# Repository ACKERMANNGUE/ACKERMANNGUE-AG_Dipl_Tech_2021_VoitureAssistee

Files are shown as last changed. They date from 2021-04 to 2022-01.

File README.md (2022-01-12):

# ACKERMANNGUE/AG_Dipl_Tech_2021_VoitureAssistee
 Repository contenant le travail de diplôme de Technicien ES en informatique réalisé par Ackermann Gawen en 2021

 ## Liens utiles
 * [Documentation technique](https://ackermanngue-ag-dipl-tech-2021-voitureassistee.readthedocs.io/fr/latest/documentation_technique.html)
 * [Journal de bord](https://ackermanngue-ag-dipl-tech-2021-voitureassistee.readthedocs.io/fr/latest/logbook.html)
 * [Trello](https://trello.com/b/ZtMZWkWF/voiture-assist%C3%A9e) 

Bonjour à toi.

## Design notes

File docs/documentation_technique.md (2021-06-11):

--- 
title: "Documentation technique de Voiture Assistée"
author: Ackermann Gawen
---
# Documentation technique
## Résumé

_Voiture assistée_ est un projet d'étude portant sur les voitures autonomes et leur fonctionnement. Ce projet est un défi que je me suis lancé étant donné la découverte des différents appareils utilisés pour ce projet. La plus-value sera surtout l'acquisition de nouvelles connaissances dans le domaine de l'informatique physique et de la mise en pratique des connaissances aquisent durant ces 6 dernières années d'études d'informatique. Par conséquent, le but du projet est de réaliser une voiture se déplaçant à l'aide d'une interface web et qui sait se déplacer par elle-même en évitant les obstacles sur sa route.

## Abstract

_Assisted Car_ is a study project about autonomous cars and how they work. This project is a challenge that I set myself given the discovery of the different devices used for this project. The added value will be mainly the acquisition of new knowledge in the field of physical computing and the application of the knowledge acquired during the last 6 years of computer science studies. Therefore, the goal of the project is to realize a car moving with the help of a web interface and which knows how to move by itself by avoiding the obstacles on its way.

## Poster

Poster du projet Voiture Assistée

## Cahier des charges

### Titre du projet

Le titre du projet est Voiture assistée, car le but du projet est d'en réaliser une.

### Contexte

Ce projet m'a été proposé par M. Bonvin car il a vu que j'allais faire une simulation de voiture autonome, il s'est dit que l'on pourrait tourner la chose autrement. Il a une multitude de Raspberry Pi, de composants ainsi qu'une voiture LEGO controlable. C'est pourquoi il m'a dirigé vers une programmation utilisant des capteurs et du bluetooth.

### Objectif

L'objectif principal de ce projet est de réaliser une voiture capable de se déplacer d'un point A à un point B en évitant les différents obstacles sur sa route. Pour ce faire, il faudra trouver un moyen de communiquer avec le Technic Hub afin de mouvoir la voiture. Ensuite, il faudra faire fonctionner indépendamment les différents capteurs. Pour ensuite créer un algorithme événementiel gérant les différentes pondérations des messages que les capteurs enverront.

### Technologies et matériels utilisés

#### Logiciels

- Visual Studio Code
  - Python
  - Flask
- Github
- Markdown
- QCAD
- Photoshop CS6
- Pencil
- Trello

#### Matériels

- Raspberry Pi 0 WiFi
- Raspberry Pi 4B
- 4 Caméras infrarouges (PI NoIR)
- 4 phares (Bright Pi v1.0)
- GPS (Ultimate GPS Breakout v3)
- Émetteur WiFi (ASUS RT-AC58U)
- LEGO 4x4 X-trem Off-Roader
- Détecteur infrarouge (Flying-Fish)
- Radar 360 (RPLiDAR A2M8)

#### Environnement de développement

Pour me connecter au Raspberry Pi sur lequel je travaille, j'utilise :

- Remote SSH pour éditer le code
  - Il s'agit d'une extension Visual Studio Code disponible [ici](https://marketplace.visualstudio.com/items?itemName=ms-vscode-remote.remote-ssh)
- Github pour publier mon code écrit sur le Raspberry Pi et pour mettre à disposition la documentation technique ainsi que le journal de bord
- RealVNC pour me connecter à distance à l'interface graphique du Raspberry Pi
  - Il s'agit d'un logiciel créant un serveur et un client permettant de contrôler à distance l'écran d'un autre ordinateur, disponible [ici](https://www.realvnc.com/fr/connect/download/viewer/).

### Description détaillée de ce que l'application fait

La voiture est télécommandable à distance à l'aide d'une interface web. Sur le site internet, on a accès à la gestion des états des différents capteurs ainsi que des données qu'ils envoient tel que pour la détection sol, le radar 360° ainsi que pour le flux vidéo des caméras.

#### Plan de la voiture

Croquis du plan de la voiture
Dans le croquis du plan de la voiture présent ci-dessus, je vais énoncer le rôle de chaque composant.

1. Les phares sont représentés par le Bright Pi
2. Les détecteurs de sol placés au niveau des roues sont représentés par le Flying-Fish
3. Le Raspberry Pi 4 est représenté par RSP 4
4. Le Raspberry Pi 0 WiFi est représenté par RSP 0 W
5. Le scanner 360° est représenté par le Lidar

En comparaison, voici de quoi est équipée une vraie voiture autonome :

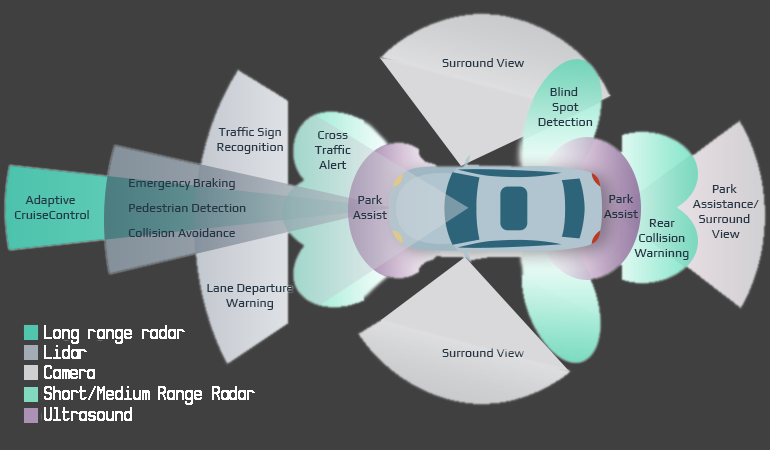
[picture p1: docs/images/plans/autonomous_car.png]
Plan d'une voiture autonome


#### Schéma explicatif de l'application

L'application offre plusieurs pages.

#### Interface utilisateur de l'application

Une page d'interface utilisateur, pour avoir accès aux informations des capteurs ainsi que leurs états.

Interface utilisateur

#### Interface télécommande

Une page de télécommande pour la voiture.

##### En mode manuel

L'utilisateur déplace la voiture à l'aide de la manette disponible sur le site web.

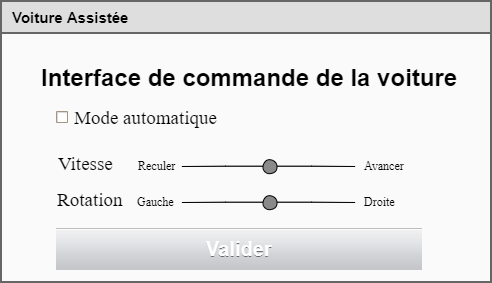
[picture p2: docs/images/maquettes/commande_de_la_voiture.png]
Interface de télécommande en mode manuel


##### En mode automatique

La voiture se déplace de manière rectiligne en évitant les obstacles sur sa route.

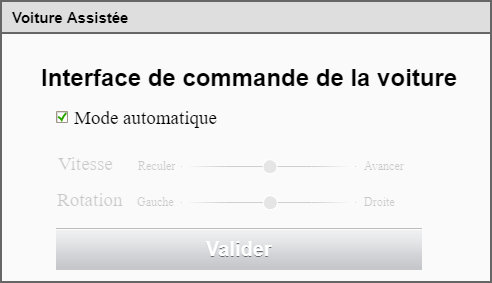
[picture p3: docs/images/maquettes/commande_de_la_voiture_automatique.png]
Interface de télécommande en mode automatique


## Contact

| Status | Nom | Prénom | Email | Numéro de téléphone |
| --- | :---: | :----: | :---: | --- |
| Élève | Ackermann | Gawen  | gawen.ackrm@eduge.ch | +41 79 88 98 69 4 |
| Professeur de diplôme |  Bonvin | Pascal | edu-bonvinp@eduge.ch | +33 6 32 17 84 11 |

## Manuel technique
Dans cette rubrique, nous allons voir comment les divers éléments utilisés dans ce projet ont été mis en place.

### Structure du projet
Dans cette section, je vais vous expliquer la structure de mon projet.

```
├── code
│   ├── Flask
│   └── Toolbox
├── docs
│   ├── images
│   ├── plans
│   ├── documentation_technique.md
│   ├── index.md
│   ├── logbook.md
│   └── requirements.txt
├── site
├── mkdocs.yml
└── README.md
```

Le répertoire :

* `Flask` contient les 2 serveurs Flask à exécuter sur les divers Raspberry Pi
* `Toolbox` contient les différents fichiers python et C++ utilisés pour la mise en place ainsi que les premiers tests des divers éléments à utiliser dans l'application
* `images` contient toutes les images utilisées pour la documentation technique
* `plans` contient les fichiers QCad des plans initiaux de la voiture
* `site` la documentation compilée par MkDocs

### Plan réseau

Étant donné que les divers éléments communiquent par le WiFi, ils doivent donc avoir des adresses IP. Dans mon cas, j'ai choisi d'utiliser des adresses IP statiques. Tous les Raspberry Pi 0 WiFi sont connectés sur le point d'accès qu'est le Raspberry Pi 4. Pour comprendre comment le Raspberry Pi 4 a été transformé en point d'accès, veuillez lire la section parlant de RaspAP dans le guide de mise en place des éléments utilisés.

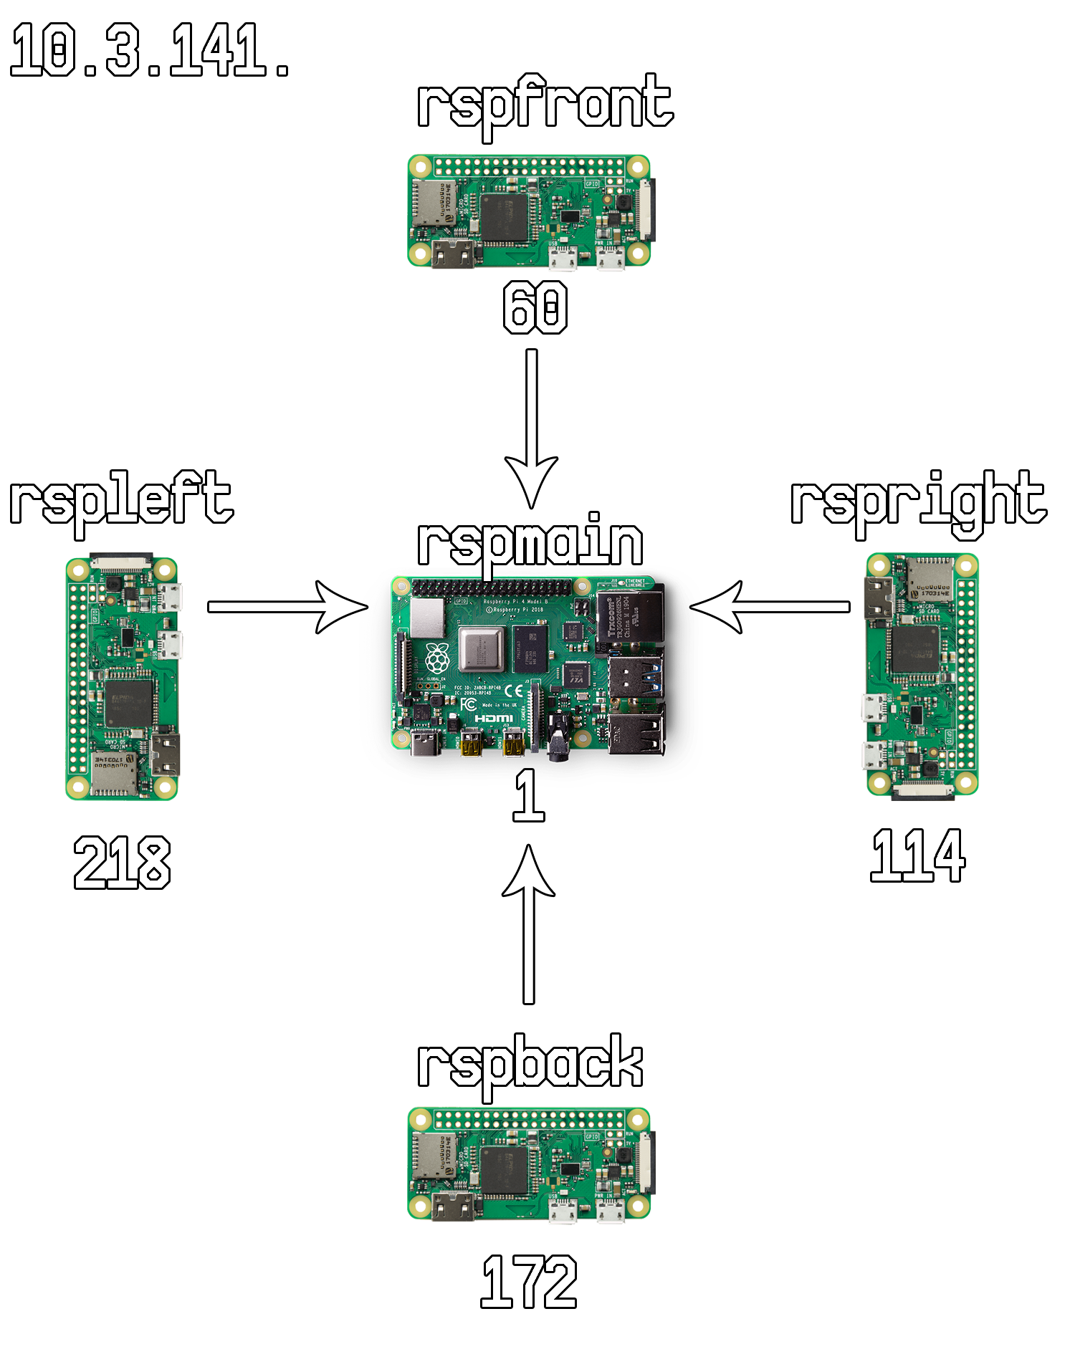
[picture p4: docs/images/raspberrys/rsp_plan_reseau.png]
Plan réseau des Raspberry Pi


### Branchements
#### Alimentation générale
Pour l'alimentation générale, j'ai pris 2 anciens câbles USB que j'ai coupés et dénudés afin de récupérer l'alimentation (Le VCC et le GND). Ces deux câbles ont ensuite été soudés sur les pins soudées à la plaquette.

À la base, la plaquette et la rangée de pins ressemblaient à ceci : 
Plaquette et pins utilisés afin de créer le système d'alimentation générale

Pour ensuite être soudé de la sorte : 

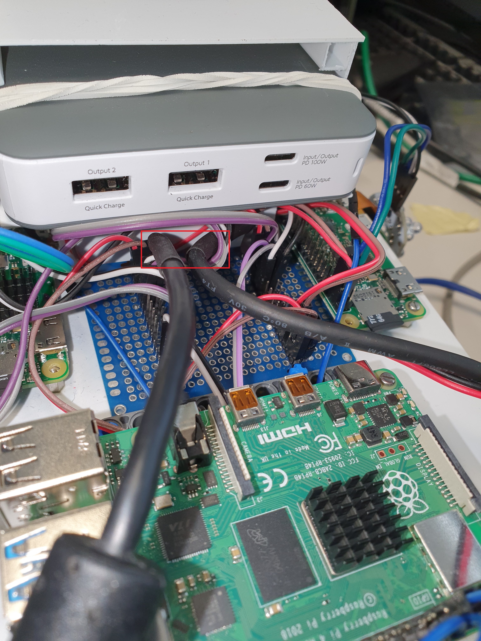
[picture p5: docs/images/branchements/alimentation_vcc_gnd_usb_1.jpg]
Système d'alimentation générale


Système d'alimentation générale

Le courant est soudé sur la pin de gauche tandis que la terre sur la pin de droite. Ce processus a été répété 2 fois, car il y a deux sorties présentes sur la batterie externe.

Les câbles USB sont branchés dans les ports Output 1 et 2 de la batterie externe comme ceci :

Courant de l'alimentation générale

Il est important de noter, que chaque composant est branché à l'alimentation générale de la sorte : 

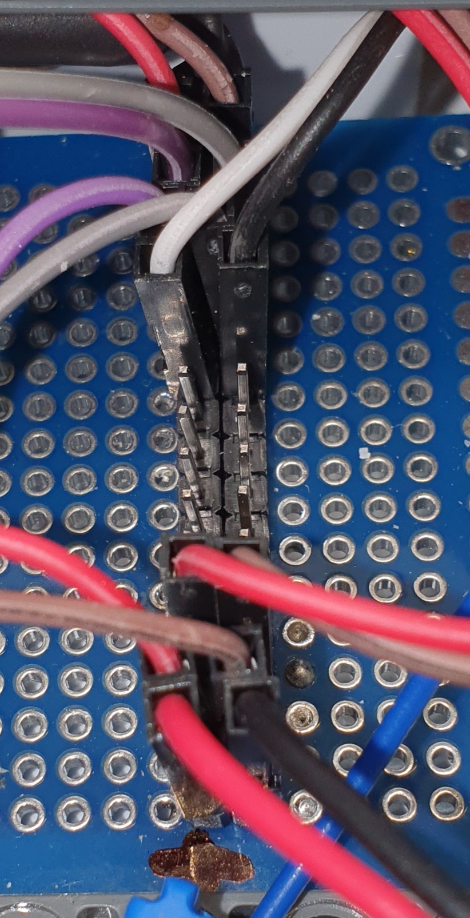
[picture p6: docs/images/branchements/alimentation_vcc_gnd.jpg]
Branchement des composants sur l'alimentation générale


Par conséquent sur cet exemple, les câbles rouges, blancs et violets sont branchés sur le courant et les câbles noirs, gris et bruns sont branchés sur la terre.

#### Raspberry Pi 4
De base, le Raspberry Pi 4 était branché à l'alimentation générale et était alimenté par les pins 4 et 6 du GPIO, mais après quelques tests, j'ai pu me rendre compte que certain Raspberry Pi 0 WiFi branché au système d'alimentation générale n'avait pas assez de courant et ne faisaient que de redémarrer en boucle. C'est pourquoi après réflexion, j'ai branché le Raspberry Pi 4 sur la batterie externe en USB-C comme ceci afin de libérer de la charge de courant de l'alimentation générale :

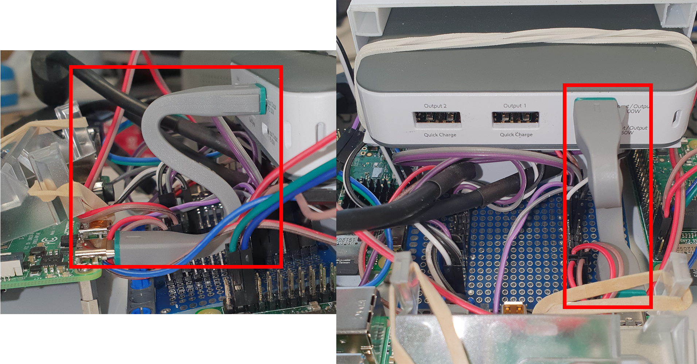
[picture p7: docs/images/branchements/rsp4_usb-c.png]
Branchement du Raspberry Pi 4 à la batterie externe


##### Lidar
Le lidar est connecté à l'adaptateur qui permet de le brancher en USB au raspberry comme vu dans la section portant sur le Lidar dans le guide de mise en place.

Pour l'affichage graphique des données perçues par le Lidar, veuillez regarder la section parlant de Matplotlib dans le guide de mise en place et pour ce qui est de l'affichage des données en un quasi-temps réel, j'utilise la même méthode que pour la récupération du flux de la caméra en temps réel.

##### Flying-Fish
Les divers Flying-Fish sont branchés par des câbles gris et violets à l'alimentation générale, mais les valeurs de sorties qu'ils fournissent sont branchés par des câbles bleus sur les GPIO suivant du raspberry pi 4 :

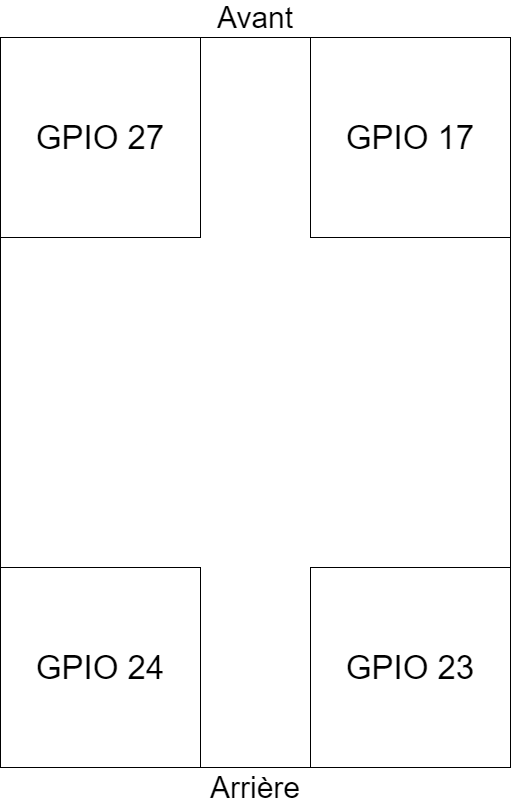
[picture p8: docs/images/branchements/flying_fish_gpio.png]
GPIO utilisés pour les Flying-Fish


#### Raspberry Pi 0 WiFi
Le raspberry pi 0 WiFi est branché à l'alimentation générale et est alimenté par les pins 4 et 6 du GPIO.

##### Caméra 
La caméra est branchée de la même manière que dans la section expliquant le module caméra dans le document de mise en place des composants.

#### Bright Pi 
Le Bright Pi est branché sur l'alimentation générale avec des câbles blancs et noirs. Les 2 autres câbles bleus et verts sont branchés sur des GPIO I2C, donc les pins 2 et 9. Pour ce qui est du câblage pour les câbles bleus et verts, il est identique à la section expliquant ce qu'est le Bright Pi dans le guide de mise en place.

### Analyse organique
Dans cette section, nous allons parler plus en détail du fonctionnement de l'application et des éléments mis en place.

#### Raspberry Pi 4
##### À quoi sert-il ?
Ce raspberry pi est le raspberry pi principal. C'est-à-dire que c'est lui qui va être le point d'accès par rapport aux autres rapsberry pi dont la voiture est équipée.

##### Comment on l'utilise ?
Pour exécuter le script du serveur principal, il faut utiliser la commande `python3 server.py` depuis le répertoire `/code/Flask/flask_server`. Ce script est un serveur Flask nous donnant accès aux différentes fonctionnalités de l'application.

##### Comment fonctionne-t-il ?
Une fois le serveur lancé, et après nous être rendu avec un navigateur web connecté à l'adresse du raspberry pi et sur le port 5000 du réseau fournit par le raspberry pi 4. Exemple : `10.3.141.1:5000`

###### Barre de navigation
La barre de navigation nous permet de changer de page. Cette dernière contient 5 éléments.

Barre de navigation du site web

* A. Redirection sur la page d'accueil
* B. Redirection sur la page de télécommande
* C. Redirection sur la page du tableau de bord
* D. Création d'une connexion avec la voiture
* E. Déconnexion avec la voiture
  
###### Page d'accueil
Ceci est la page sur laquelle on arrive lorsque l'on tape l'adresse IP du point d'accès avec le port 5000.

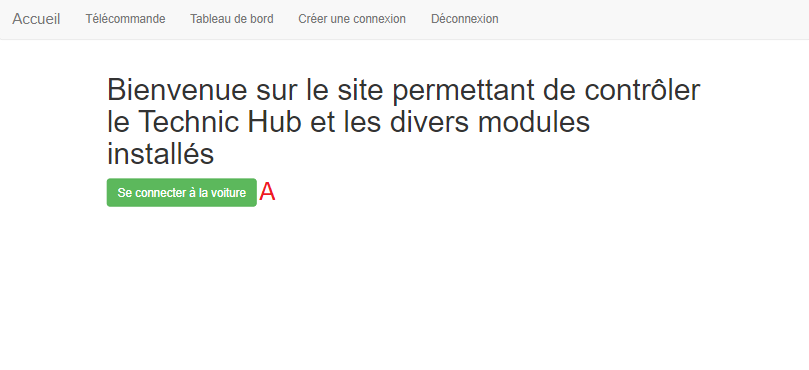
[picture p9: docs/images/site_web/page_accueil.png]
Page d'accueil du site web


* A. Bouton créant une connexion avec la voiture

###### Page de télécommande
Cette page permet, si une connexion avec la voiture est établie, de contrôler la voiture.

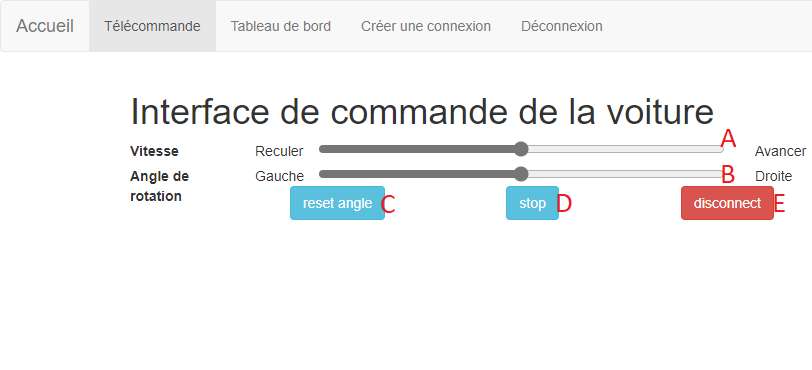
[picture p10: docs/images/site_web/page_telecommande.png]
Page de télécommande du site web


* A. Une barre coulissante allant de -100 à 100 pour gérer la vitesse de la voiture
* B. Une barre coulissante allant de -100 à 100 pour gérer le guidon de la voiture
* C. Bouton remettant le guidon à sa position initiale
* D. Bouton coupant les moteurs de la voiture
* E. Bouton de déconnexion à la voiture

Il est important de savoir que dans le code gérant les déplacements de la voiture, j'inverse les données et les divise par 100, car les valeurs sont comprises entre -1 et 1. La raison pour laquelle j'inverse par la suite les vitesses dans le code, c'est parce que pour avancer avec la voiture, il faut lui donner une vitesse négative, cependant je trouvais plus logique pour une interface utilisateur que pour avancer l'on ajuste la barre coulissante à droite.

###### Page du tableau de bord
Cette page permet à l'utilisateur de gérer les différents capteurs et de voir en temps réel les données reçues par les caméras ainsi que par le Lidar.

Page de télécommande du site web

* A. Case à cocher (dés)activant le mode automatique
* B. Case à cocher (dés)activant les leds à la position indiquée 
  * Les cases de gauche allument les leds blanches, les cases de droites allument les leds infrarouges
* C. Case à cocher (dés)activant la caméra à la position indiquée
* D. Case à cocher (dés)activant la récupération des données du Lidar

De base, toutes les caméras sont éteintes ainsi que le radar :

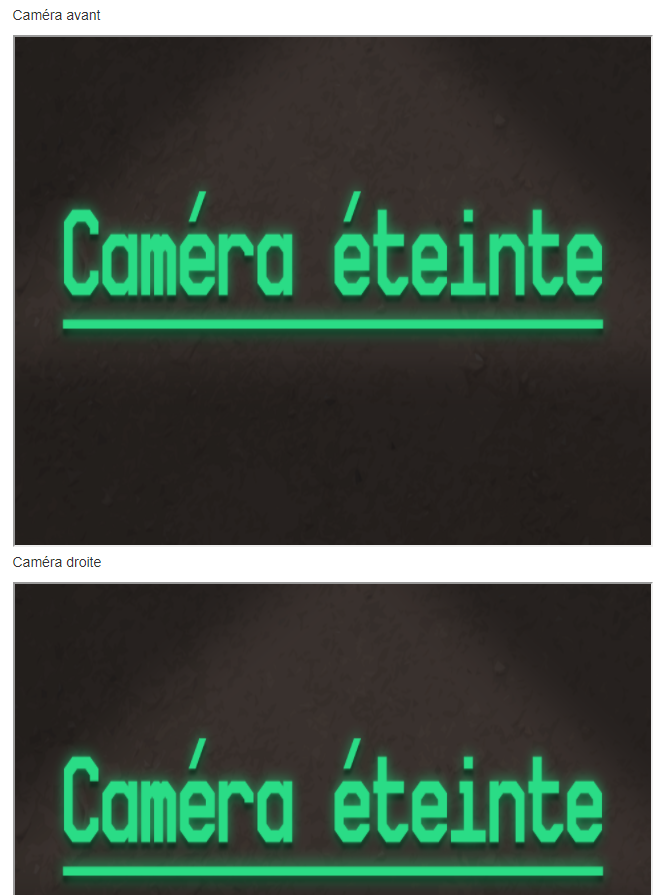
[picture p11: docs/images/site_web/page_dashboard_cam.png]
Caméras éteintes


Radar éteint

Voici ce à quoi ça ressemble lorsque l'on active une caméra et le radar :

Caméra et radar activé

J'ai choisi d'afficher les éléments à la suite, car l'utilisateur va utiliser son téléphone pour se connecter à l'application. Il est donc plus pratique d'avoir accès aux éléments comme ceci étant sur un téléphone portable.

Pour comprendre comment le flux des diverses caméras sont récupérés, veuillez regarder la section parlant de le récupération du flux vidéo dans le guide de mise en place. 

###### Page création de connexion
Lors de l'appui sur cet élément, cela va lancer une connexion avec la voiture.

###### Page de déconnexion
Lors de l'appui sur cet élément, cela va lancer une déconnexion avec la voiture.

##### Comment fonctionne la connexion avec la voiture ?
La création de la connexion avec la voiture s'effectue dans la classe `car`. Cette classe lorsque l'on crée un nouvel objet, va demander une connexion Gatt au Technic Hub.

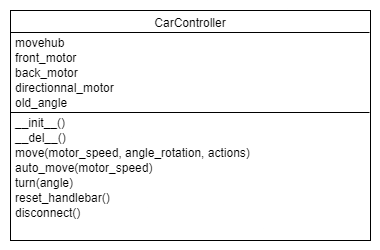
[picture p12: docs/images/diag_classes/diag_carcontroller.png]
Diagramme de classe CarController


```python
class CarController:
    """Class controlling the car"""

    MY_MOVEHUB_ADD = "90:84:2B:50:36:43"
    MY_BTCTRLR_HCI = "hci0"
    MIN_ANGLE = -1
    MAX_ANGLE = 1
    DEFAULT_ANGLE = 0
    MAX_MOTOR_POWER = 1
    MOTOR_STOP_POWER = 0
    MAXIMUM_SPEED_WHEN_GROUND_ISNT_DETECTED = 0.2

    def __init__(cls):
        cls.connection = get_connection_gatt(hub_mac=cls.MY_MOVEHUB_ADD)
        try:
            cls.movehub = MoveHub(cls.connection)
            # The motors
            cls.front_motor = Motor(cls.movehub, cls.movehub.PORT_A)
            cls.back_motor = Motor(cls.movehub, cls.movehub.PORT_B)
            cls.directionnal_motor = EncodedMotor(cls.movehub, cls.movehub.PORT_C)
            cls.old_angle = cls.DEFAULT_ANGLE
        except:
            cls.movehub = None
            cls.front_motor = None
            cls.back_motor = None
            cls.directionnal_motor = None
            cls.instance = None
            cls.connection = None
            cls.old_angle = None

```

On fait un try / except car si la demande n'est pas aboutie, il faut que l'on puisse tout de même remplir les champs de la classe.

Voici la route qui permet de créer la connexion :

```python
@app.route("/create_car/")
def create_car():
    """Used to the creation of the car"""
    global car
    car = CarController()
    if hasattr(car, "connection"):
        return render_template("form_remote_car.html")
    else:
        car = None
        return render_template(
            "error.html", msg="Une connexion est nécessaire pour pouvoir interagir avec"
        )
```

Lors de l'appel à la route ci-dessus, il ne faut pas oublier de cliquer sur le bouton vert du `Technic Hub`. 

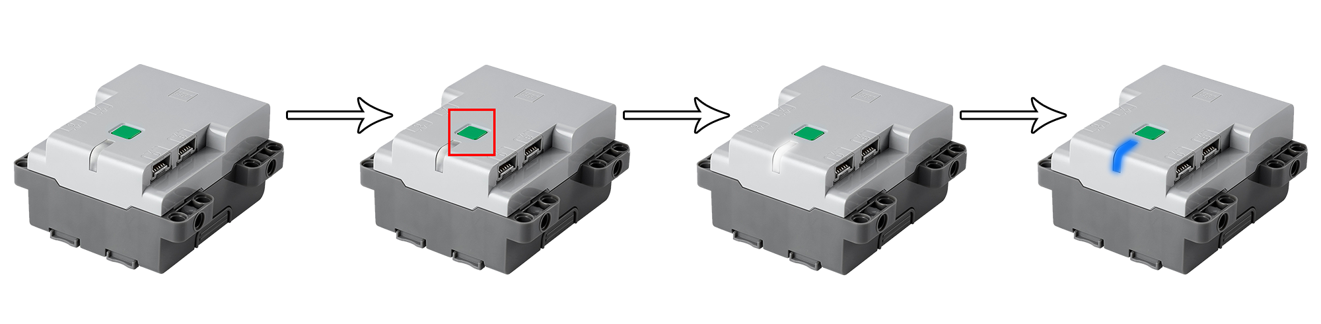
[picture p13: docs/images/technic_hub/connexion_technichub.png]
Préparation du Technic Hub à l'appareillage


Il est important de noter que la voiture est stockée dans une variable globale car ceci nous permet de alors d'avoir accès à la voiture depuis divers méthodes. À la base, cette connexion avec la voiture était faite à travers le design pattern du Singelton : 

```python
def __new__(cls):
    if(cls.instance is None):
        cls.instance = super(CarController, cls).__new__(cls)
        cls.connection = get_connection_gatt(hub_mac=cls.MY_MOVEHUB_ADD)
        try:
            cls.movehub = MoveHub(cls.connection)
            # The motors
            cls.front_motor = Motor(cls.movehub, cls.movehub.PORT_A)
            cls.back_motor = Motor(cls.movehub, cls.movehub.PORT_B)
            cls.directionnal_motor = EncodedMotor(cls.movehub, cls.movehub.PORT_C)
        except:
            cls.movehub = None
            cls.front_motor = None
            cls.back_motor = None
            cls.directionnal_motor = None
    return cls.instance
```

Le problème que le Singleton avait était que des fois, il perdait la connexion à la voiture alors que l'instance de l'objet était toujours présente. C'est-à-dire, que lorsque l'on se déconnectait de la voiture à l'aide de la méthode de déconnexion appelée par la route :

```python
# Code présent dans la classe CarController
def disconnect(self):
        self.connection.disconnect()

# Code présent dans le fichier server.py dans le répertoire /code/Flask/flask_server/
@app.route("/close_connection/")
def close_connection():
    """Close the connection between the Raspberry Pi and the Technic Hub"""
    global car
    output = "Connexion toujours en cours"
    if car != None:
        car.disconnect()
        output = "Connexion fermée avec l'appareil {0}".format(car.MY_MOVEHUB_ADD)
        car = None

    return render_template("connection.html", msg=output)

```

##### Comment fonctionne la récupération des données du Lidar ?

Pour activer l'API C++ pour y récupérer les distances à chaque angles qui sont écrits dans la console et afin d'éviter de rendre le code bloquant, j'ai utilisé `Asyncio`. 

Voici le code permettant l'appel et le traitement asynchrone des données :

```python
@app.route("/bg_processing_lidar/<string:state>", methods=["POST"])
def bg_process_lidar(state=None):
    """Process the values passed by Javascript"""

    try:
        loop = asyncio.get_running_loop()
    except RuntimeError:  # no event loop running:
        loop = asyncio.new_event_loop()
    finally:
        loop.run_until_complete(main(state))

    return ""

async def main(should_scan):
    """
    The main function which calls the run loop async

    should_scan : The code to know if the program should scan or not
    """
    await run(should_scan)

async def run(should_scan):
    """
    Will run the subprocess and bind the async method

    should_scan : The code to know if the program should scan or not
    """
    command = ("./scanner/simple_grabber /dev/ttyUSB0 " + should_scan).split()
    process = await create_subprocess_exec(*command, stdout=PIPE, stderr=PIPE)
    await asyncio.wait([_read_stream(process.stdout, lambda x: {get_radar_data(x)})])
    await process.wait()

async def _read_stream(stream, callback):
    """
    Will read the text in the console from the process simple_grabber

    stream : The streaming of the data in the console
    callback : The method to call when data has been received

    """
    while True:
        line = await stream.readline()
        if line:
            callback(line.split(b","))
        else:
            break

def get_radar_data(row):
    """
    Will parse the data received in text by the Lidar

    row : Row to read and to add or modify in the array of angles
    """
    global rows
    # row normaly is like [angle, distance]
    tmp = row
    if len(tmp) == 2:
        angle = int(tmp[0])
        # remove the line return
        dist = tmp[1].replace(b"\n", b"")
        rows[angle] = float(dist)

```

Comme l'on peut le voir, lors de l'activation ainsi que de la désactivation du Lidar. On effectue un processus, car étant donné que dans le code de l'API, il s'agit d'une boucle infinie récupérant et lissant les données qui sont affichées dans la console, on a besoin de manière asynchrone à traiter ses données et à les mettre dans le tableau.

C'est ce à quoi sert la méthode `_read_stream`. Cette méthode nous permet de lire ligne par ligne le contenu de sortie de la console (`process.stdout`) et en l'ajoutant dans le tableau avec la méthode `get_radar_data(row)`.

Méthode utilisée pour récupérer en temps réel les données du Lidar

###### Code de l'API C++ modifié

```cpp

int main(int argc, const char *argv[])
{
    const char *opt_com_path = NULL;
    _u32 opt_com_baudrate = 115200;
    u_result op_result;
    bool run_scan = false;

    // check if the the program should run scans
    if(argc == 3) {
        char arg = (char)*argv[2];
        if(arg == '1') {
            run_scan = true;
        } else if(arg == '0') {
            run_scan = false;
        }
    }

    if (argc < 2)
    {
        print_usage(argc, argv);
        return -1;
    }
    opt_com_path = argv[1];

    // create the driver instance
    RPlidarDriver *drv = RPlidarDriver::CreateDriver(DRIVER_TYPE_SERIALPORT);

    if (!drv)
    {
        fprintf(stderr, "insufficent memory, exit\n");
        exit(-2);
    }

    rplidar_response_device_health_t healthinfo;
    rplidar_response_device_info_t devinfo;
    do
    {
        // try to connect
        if (IS_FAIL(drv->connect(opt_com_path, opt_com_baudrate)))
        {
            fprintf(stderr, "Error, cannot bind to the specified serial port %s.\n", opt_com_path);
            break;
        }

        op_result = drv->getDeviceInfo(devinfo);

        if (IS_FAIL(op_result))
        {
            if (op_result == RESULT_OPERATION_TIMEOUT)
            {
                // you can check the detailed failure reason
                fprintf(stderr, "Error, operation time out.\n");
            }
            else
            {
                fprintf(stderr, "Error, unexpected error, code: %x\n", op_result);
                // other unexpected result
            }
            break;
        }

        op_result = drv->getHealth(healthinfo);
        if (IS_OK(op_result))
        { // the macro IS_OK is the preperred way to judge whether the operation is succeed.
            switch (healthinfo.status)
            {
            case RPLIDAR_STATUS_WARNING:
                printf("Warning.");
                break;
            case RPLIDAR_STATUS_ERROR:
                printf("Error.");
                break;
            }
            printf(" (errorcode: %d)\n", healthinfo.error_code);
        }
        else
        {
            fprintf(stderr, "Error, cannot retrieve the lidar health code: %x\n", op_result);
            break;
        }

        if (healthinfo.status == RPLIDAR_STATUS_ERROR)
        {
            fprintf(stderr, "Error, rplidar internal error detected. Please reboot the device to retry.\n");
            break;
        }

        drv->startMotor();

        if (IS_FAIL(drv->startScan(0, 1))) // you can force rplidar to perform scan operation regardless whether the motor is rotating
        {
            fprintf(stderr, "Error, cannot start the scan operation.\n");
            break;
        }

        int max_size_arr_angle_dist = 360;
        float angle_dist_tmp[max_size_arr_angle_dist];
        float angle_dist[max_size_arr_angle_dist];
        int size_arr_angle_dist = (sizeof(angle_dist) / sizeof(angle_dist[0]));

        const int MAX_RANGE_LIDAR = 16000.0f;
        const int MIN_RANGE_LIDAR = 0.0f;
        // used as a code in order to treat the data below in another process
        //printf("<<<\n");
        while (run_scan)
        {
            //reset the array to empty (empty represented by the 0)
            std::fill_n(angle_dist, max_size_arr_angle_dist, 0.0f);
            capture_and_display(angle_dist, drv);

            if (size_arr_angle_dist == 0)
            {
                fprintf(stderr, "Error, cannot grab scan data.\n");
                break;
            }
            
            /* Correct the errors */
            for (size_t j = 0; j < max_size_arr_angle_dist; j++)
            {
                if (angle_dist[j] < MIN_RANGE_LIDAR && angle_dist[j] >= MAX_RANGE_LIDAR)
                {
                    angle_dist[j] = MIN_RANGE_LIDAR;
                }
            }

            /* make the average of distance */
            capture_and_display(angle_dist_tmp, drv);
            for (size_t j = 0; j < max_size_arr_angle_dist; j++)
            {
                if (angle_dist_tmp[j] > MIN_RANGE_LIDAR && angle_dist_tmp[j] < MAX_RANGE_LIDAR)
                {
                    angle_dist[j] = (angle_dist[j] + angle_dist_tmp[j]) / 2;
                }
            }

            for (size_t j = 0; j < max_size_arr_angle_dist; j++)
            {
                printf("%d,%f\n", j, angle_dist[j]);
            }
        }

    } while (0);

    drv->stop();
    drv->stopMotor();

    RPlidarDriver::DisposeDriver(drv);
    return 0;
}

```

##### Comment fonctionne la gestion du déplacement de la voiture ?
###### Télécommande
La télécommande effectue des appels AJAX avec les valeurs des barres coulissantes comme ceci :

```javascript
<script type="text/javascript">

$(document).on('input', '#rngMove', function() {
    execute();
});

$(document).on('input', '#rngRotationAngle', function() {
    execute();
});

function execute(){
    $.ajax({
            url: '/bg_processing_car/',
            data: $('form').serialize(),
            type: 'POST',
            success: function(response) {
                console.log("action performed");
            },
            error: function(error) {
                console.log(error);
            }
        });
    }
</script>
```

Les ID `rngMove` et `rngRotationAngle` sont ceux attachés aux barres coulissantes. À chaque changement de valeurs, qu'il s'agisse du guidon ou de la vitesse des moteurs, la route appelée à l'aide d'AJAX `/bg_processing_car/` se charge de faire le traitement :

```python
@app.route("/bg_processing_car/", methods=["POST"])
def bg_process_car():
    """Process the values passed by Javascript"""

    global car

    move_speed = request.form["rngMove"]
    angle_rotation = request.form["rngRotationAngle"]

    if car != None:
        # Convert the values
        move_speed = float(move_speed)
        angle_rotation = int(angle_rotation)
        # Get the allowed actions of the car
        actions = get_actions_for_car(move_speed)
        car.move(move_speed, angle_rotation, actions)
    return render_template(
        "form_remote_car.html",
        speed=move_speed,
        angle=angle_rotation,
    )

def get_actions_for_car(speed):
    """Process the actions that the car is allowed to do according to the flying-fish"""
    actions = (constants.CODE_TURN_NOTHING, constants.CODE_MOVE_NOTHING)
    # INDEX 0 represent the turn code
    # INDEX 1 represent the move code
    if (
        GPIO.input(constants.GPIO_FLYING_FISH_FRONT_LEFT)
        and GPIO.input(constants.GPIO_FLYING_FISH_FRONT_RIGHT)
        and not GPIO.input(constants.GPIO_FLYING_FISH_BACK_LEFT)
        and not GPIO.input(constants.GPIO_FLYING_FISH_BACK_RIGHT)
    ):
        print("les deux avant")
        actions = (constants.CODE_TURN_NOTHING, constants.CODE_MOVE_BACKWARD)

    elif GPIO.input(constants.GPIO_FLYING_FISH_FRONT_LEFT):
        print("gauche avant")
        actions = (constants.CODE_TURN_RIGHT, constants.CODE_MOVE_NOTHING)

    elif GPIO.input(constants.GPIO_FLYING_FISH_FRONT_RIGHT):
        print("droite avant")
        actions = (constants.CODE_TURN_LEFT, constants.CODE_MOVE_NOTHING)

    elif (
        not GPIO.input(constants.GPIO_FLYING_FISH_FRONT_LEFT)
        and not GPIO.input(constants.GPIO_FLYING_FISH_FRONT_RIGHT)
        and GPIO.input(constants.GPIO_FLYING_FISH_BACK_LEFT)
        and GPIO.input(constants.GPIO_FLYING_FISH_BACK_RIGHT)
    ):
        print("les deux arrière")
        actions = (constants.CODE_TURN_NOTHING, constants.CODE_MOVE_FORWARD)

    elif GPIO.input(constants.GPIO_FLYING_FISH_BACK_LEFT):
        print("gauche arrière")
        actions = (constants.CODE_TURN_RIGHT, constants.CODE_MOVE_FORWARD)

    elif GPIO.input(constants.GPIO_FLYING_FISH_BACK_RIGHT):
        print("droite arrière")
        actions = (constants.CODE_TURN_LEFT, constants.CODE_MOVE_FORWARD)

    return actions
```

Voici le code de déplacement pour la voiture dans la classe `CarController` :

```python

    def move(self, motor_speed, angle_rotation, actions):
        """Moves the car with a specific speed and rotation

        motor_speed : The motor's speed
                      NOTE : to move forward, the value must be reversed because it is basically negative
        angle_rotation : The rotation of the directionnal motor
        actions : The list of the possible actions
        """
        # Invert the power direction
        if motor_speed != 0:
            motor_speed *= -1
        # Max value of motor is -1 and +1 but in the HTML form, the range input can be set between -100 to +100
        motor_speed /= 100
        angle_rotation /= 100

        # INDEX 0 represent the turn code
        # INDEX 1 represent the move code
        try:
            if actions[0] == constants.CODE_TURN_LEFT and angle_rotation < 0:
                self.turn(angle_rotation)

            elif actions[0] == constants.CODE_TURN_RIGHT and angle_rotation > 0:
                self.turn(angle_rotation)

            elif actions[0] == constants.CODE_TURN_NOTHING:
                self.turn(angle_rotation)

            if actions[1] == constants.CODE_MOVE_FORWARD and motor_speed < 0:
                if motor_speed > self.MAXIMUM_SPEED_WHEN_GROUND_ISNT_DETECTED:
                    motor_speed = self.MAXIMUM_SPEED_WHEN_GROUND_ISNT_DETECTED
                self.front_motor.start_power(motor_speed)
                self.back_motor.start_power(motor_speed)

            elif actions[1] == constants.CODE_MOVE_BACKWARD and motor_speed > 0:
                if motor_speed > self.MAXIMUM_SPEED_WHEN_GROUND_ISNT_DETECTED:
                    motor_speed = self.MAXIMUM_SPEED_WHEN_GROUND_ISNT_DETECTED
                self.front_motor.start_power(motor_speed)
                self.back_motor.start_power(motor_speed)

            elif actions[1] == constants.CODE_MOVE_NOTHING:
                self.front_motor.start_power(motor_speed)
                self.back_motor.start_power(motor_speed)
        except AssertionError:
            pass

    def turn(self, angle):
        """Turn the directionnal motor from the input value

        angle : The angle we wants the directionnal motor goes to
        """
        try:
            self.directionnal_motor.start_power(angle)
            self.old_angle = angle
        except AssertionError:
            pass

    def reset_handlebar(self):
        # Reset the angle
        angle = self.old_angle * -1
        angle /= 2
        try:
            self.directionnal_motor.start_power(angle)
            self.old_angle = angle
        except AssertionError:
            pass

    def stop_moving(self):
        """Stop the motors"""
        # Reset the angle
        try:
            self.reset_handlebar()
            self.front_motor.start_power(self.MOTOR_STOP_POWER)
            self.back_motor.start_power(self.MOTOR_STOP_POWER)
        except AssertionError:
            pass
```

On peut remarquer que dans les différentes méthodes j'utilise des `try` / `except`. Je suis obligé de les utiliser, car lors de l'envoie d'une commande au `Technic Hub`, il doit retourner une réponse, cependant des fois il se peut que pendant qu'il traite une commande, avant qu'il aie pu répondre une autre commande lui soit envoyée. Ce qui cause un problème de confirmation, et qui par conséquent faisait crash le programme.

###### Boutons
Pour comprendre plus en détail le rôle des boutons présent sur la page de télécommande, veuillez vous référer à la section décrivant l'interface pour la télécommande. 

Voici comment les actions qu'ils produisent sont gérées :

```python
@app.route("/form_remote_response/", methods=["POST"])
def form_remote_response():
    """The form's answer of the remote"""
    global car
    # Init
    move_speed = constants.DEFAULT_SPEED
    angle_rotation = constants.DEFAULT_ANGLE

    returned_value = render_template(
        "form_remote_car.html",
        speed=move_speed,
        angle=angle_rotation,
    )
    error = render_template(
        "error.html", msg="Une connexion est nécessaire pour pouvoir intéragir avec"
    )
    if request.method == "POST":
        if request.form["send_request"] == constants.BTN_REQUEST_RESET_ANGLE:
            if car != None:
                car.reset_handlebar()
            else:
                returned_value = error
        elif request.form["send_request"] == constants.BTN_REQUEST_STOP:
            if car != None:
                car.stop_moving()
            else:
                returned_value = error
        elif request.form["send_request"] == constants.BTN_REQUEST_DISCONNECT:
            returned_value = redirect("/close_connection/")
    return returned_value
```

###### Comment fonctionne le système d'arrêt d'urgence de la voiture ?

Le système d'argent d'urgence est basé sur ce que les Flying-Fish détectent.

Au lancement de l'application, la méthode `initFlyingFish()` est exécutée, ils ont tous été attachés à une méthode qui se déclenchera à chaque changement d'état :

```python

flying_fish_state = [
    constants.FLYING_FISH_STATE_GROUNDED,
    constants.FLYING_FISH_STATE_GROUNDED,
    constants.FLYING_FISH_STATE_GROUNDED,
    constants.FLYING_FISH_STATE_GROUNDED,
]

def initFlyingfish():
    # Set the mode into Broadcom SOC channel
    # It allows to use GPIO number instead of pin number
    GPIO.setmode(GPIO.BCM)
    # Set the GPIO into input mode
    GPIO.setup(constants.GPIO_FLYING_FISH_FRONT_RIGHT, GPIO.IN)
    GPIO.setup(constants.GPIO_FLYING_FISH_FRONT_LEFT, GPIO.IN)
    GPIO.setup(constants.GPIO_FLYING_FISH_BACK_RIGHT, GPIO.IN)
    GPIO.setup(constants.GPIO_FLYING_FISH_BACK_LEFT, GPIO.IN)

    # Add the events
    GPIO.add_event_detect(
        constants.GPIO_FLYING_FISH_FRONT_RIGHT, # GPIO 17
        GPIO.FALLING,
        callback=get_grounded_state,
        bouncetime=constants.GPIO_BOUNCEBACK, 
    )
    GPIO.add_event_detect(
        constants.GPIO_FLYING_FISH_FRONT_LEFT,  # GPIO 27
        GPIO.FALLING,
        callback=get_grounded_state,
        bouncetime=constants.GPIO_BOUNCEBACK,
    )
    GPIO.add_event_detect(
        constants.GPIO_FLYING_FISH_BACK_RIGHT,  # GPIO 23
        GPIO.FALLING,
        callback=get_grounded_state,
        bouncetime=constants.GPIO_BOUNCEBACK,
    )
    GPIO.add_event_detect(
        constants.GPIO_FLYING_FISH_BACK_LEFT,  # GPIO 24
        GPIO.FALLING,
        callback=get_grounded_state,
        bouncetime=constants.GPIO_BOUNCEBACK,
    )

def get_grounded_state(self):
    """Will stop the motors if the ground isn't detected anymore"""
    global car
    global flying_fish_state

    for i in range(len(constants.GPIO_FLYING_FISH)):
        for sensor_state in flying_fish_state:
            input_values = not GPIO.input(constants.GPIO_FLYING_FISH[i][0])
            if sensor_state != input_values:
                if car != None and (input_values) != True:
                    car.stop_moving()
                # Invert his state
                sensor_state = input_values
        flying_fish_state[i] = sensor_state
    print(flying_fish_state)

```

Pour savoir quel Flying-Fish est associée à quel GPIO, veuillez lire la section en parlant dans la section des branchements.

Lorsque l'un des Flying-Fish change d'état et que son nouvel état n'est pas `True`, la voiture coupe alors ses moteurs. Si le nouvel état est `True`, cela veut dire que l'on vient de détecter du sol.

À noter, que l'utilisateur peut toujours faire avancer sa voiture lorsque l'un des capteurs ne détecte plus de sol, car si on arrive dans une configuration comme celle-ci :

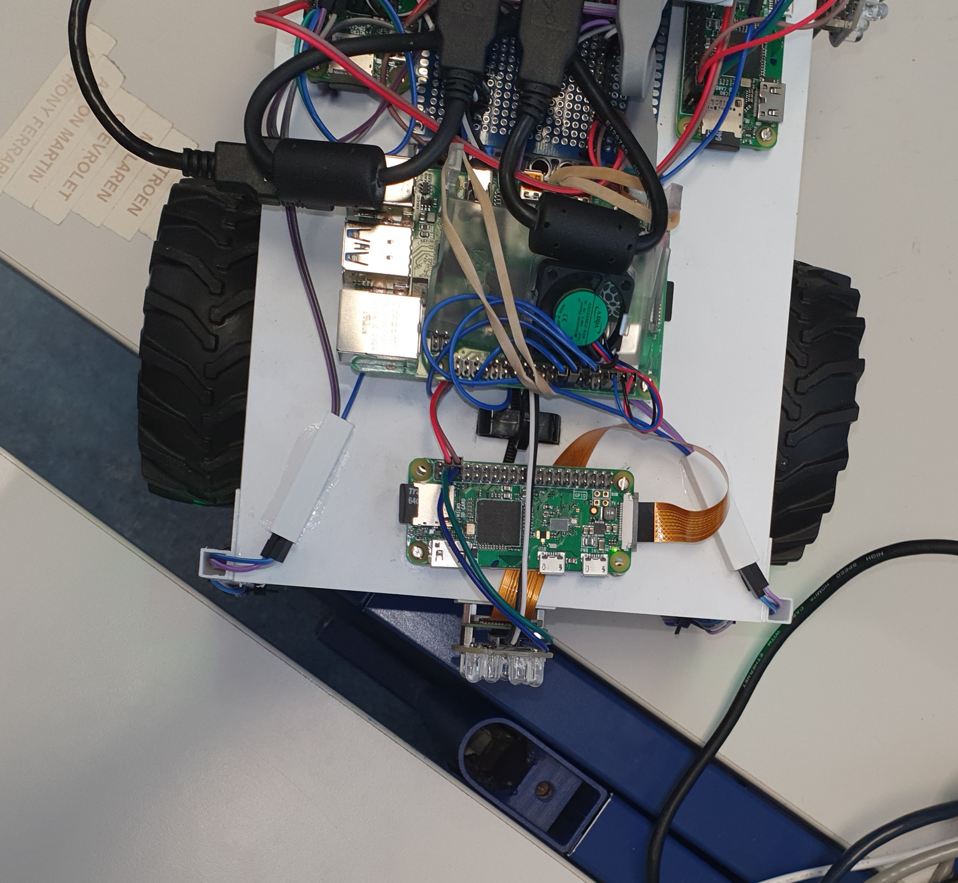
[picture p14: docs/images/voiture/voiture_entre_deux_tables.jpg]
Voiture entre 2 tables


Sachant qu'il s'agit de l'utilisateur, il est conscient qu'il peut toujours avancer, cependant je n'ai pas laissé l'utilisateur allez dans le sens du vide, car même s'il se peut qu l'on arrive dans la quasi-même configuration que vu dans l'image du dessus, mais avec les deux roues entrent les tables. 

Je ne l'ai pas laissé avancer dans le sens du vide, car dans la plupart du temps si la ligne de détecteur ne détecte plus de sol. C'est qu'il y a de fortes chances que nous ne puissions pas atteindre l'autre côté du vide et par conséquent faire tomber la voiture dans ce dernier.

Mais dans le cas où la voiture est au bord de table de justesse, l'utilisateur peut tout de même mettre les gaz à fond. Ce qui est déconseillé, car certes  du moment ou ne l'on détecte plus de sol, les moteurs se coupent, mais à cause de l'inertie des roues, la voiture tombe dans le vide. Il est donc très important que dans ce genre de cas l'utilisateur soit conscient de ce qu'il fait.

Voiture au bord de table

##### Comment fonctionne le mode automatique de la voiture ?

Lorsque le lidar est actif et que le mode automatique a été activé par la route `/launch_automatic_mode/<int:state>`, la méthode gérant la voiture va être lancée sur un autre thread différent de celui principal. À la base, j'avais tenté d'utiliser `Asyncio` une nouvelle fois pour ce cas, mais j'avais besoin de pouvoir changer l'état de la boucle présente dans `automatic_mode()`, car avec `Asyncio` lorsque je relançais le mode automatique, il y avait des erreurs qui intervenaient tandis qu'en exécutant le programme sur un autre thread on peut relancer le mode avec l'état de la case à cocher associée.

```python
@app.route("/launch_automatic_mode/<int:state>", methods=["POST"])
def launch_automatic_mode(state=None):
    """Launch the automatic_mode on another thread"""
    global automatic_mode_state
    automatic_mode_state = state
    # Create the thread
    thread = threading.Thread(target=automatic_mode)
    # Launch it
    thread.start()
    return ""

def automatic_mode():
    """Execute the automatic mode"""
    global car
    global rows
    global automatic_mode_state
    global obstacles_distances_front_left
    global obstacles_distances_front_right

    while automatic_mode_state == constants.MODE_ON:
        # Used to store the obstacles detected at left and right
        obstacles_distances_front_left = []
        obstacles_distances_front_right = []
        for i in range(len(rows)):
            distance = rows[i]

            if car != None:
                # Verify that the current angle is between 0 and 15, 345 and 360 
                if (
                    i < constants.MAX_ANGLE_OBSTACLE_DETECTION
                    or i > constants.FULL_ANGLE - constants.MAX_ANGLE_OBSTACLE_DETECTION
                ):
                    # Verify if the distance is lower than the max front distance obstacle detection 
                    if (
                        distance < constants.FRONT_DISTANCE_OBSTACLE_DETECTION
                        and distance > 0
                    ):
                        # If the current angle is lower than the max angle
                        # Add it into the left array
                        if i < constants.MAX_ANGLE_OBSTACLE_DETECTION:
                            obstacles_distances_front_left.append(distance)
                        # If the current angle is greater than the max angle inverted (345 to 360)
                        # Add it into the right array
                        if (
                            i
                            > constants.FULL_ANGLE
                            - constants.MAX_ANGLE_OBSTACLE_DETECTION
                        ):
                            obstacles_distances_front_right.append(distance)
                        # Compute the power, more the obstacle is near, more the motors will be powered
                        speed = distance / constants.FRONT_DISTANCE_OBSTACLE_DETECTION
                        # Goes backward
                        car.auto_move(speed)
                # Verify that the current angle is between 165 and 180, 180 and 195 
                elif (
                    i < constants.HALF_ANGLE + constants.MAX_ANGLE_OBSTACLE_DETECTION
                    or i > constants.HALF_ANGLE - constants.MAX_ANGLE_OBSTACLE_DETECTION
                ):
                    # Verify if the distance is lower than the max front distance obstacle detection 
                    if (
                        distance < constants.BACK_DISTANCE_OBSTACLE_DETECTION
                        and distance > 0
                    ):
                        # Compute the power, more the obstacle is near, more the motors will be powered
                        speed = distance / constants.BACK_DISTANCE_OBSTACLE_DETECTION
                        # Goes forward
                        car.auto_move(speed * (-1))
                else:
                    # If nothing, reset the handlebar and stop the motors
                    car.stop_moving()
                    car.reset_handlebar()

                # Select the smallest element
                lowest_dist_left = constants.FRONT_DISTANCE_OBSTACLE_DETECTION
                for i in range(len(obstacles_distances_front_left)):
                    if lowest_dist_left > obstacles_distances_front_left[i]:
                        lowest_dist_left = obstacles_distances_front_left[i]

                # Select the smallest element
                lowest_dist_right = constants.FRONT_DISTANCE_OBSTACLE_DETECTION
                for i in range(len(obstacles_distances_front_right)):
                    if lowest_dist_right > obstacles_distances_front_right[i]:
                        lowest_dist_right = obstacles_distances_front_right[i]
                # Check that their values are not the default one
                if (
                    lowest_dist_right != constants.FRONT_DISTANCE_OBSTACLE_DETECTION
                    and lowest_dist_left != constants.FRONT_DISTANCE_OBSTACLE_DETECTION
                ):
                    # If the nearest obstacle is at left, we need to turn to the right
                    if lowest_dist_left < lowest_dist_right:
                        car.turn(car.MIN_ANGLE)
                    # If the nearest obstacle is at right, we need to turn to the left
                    elif lowest_dist_left > lowest_dist_right:
                        car.turn(car.MAX_ANGLE)
                    # Else, just reset the handlebar
                    else:
                        car.reset_handlebar()
```

Voici l'algorithme résumé :

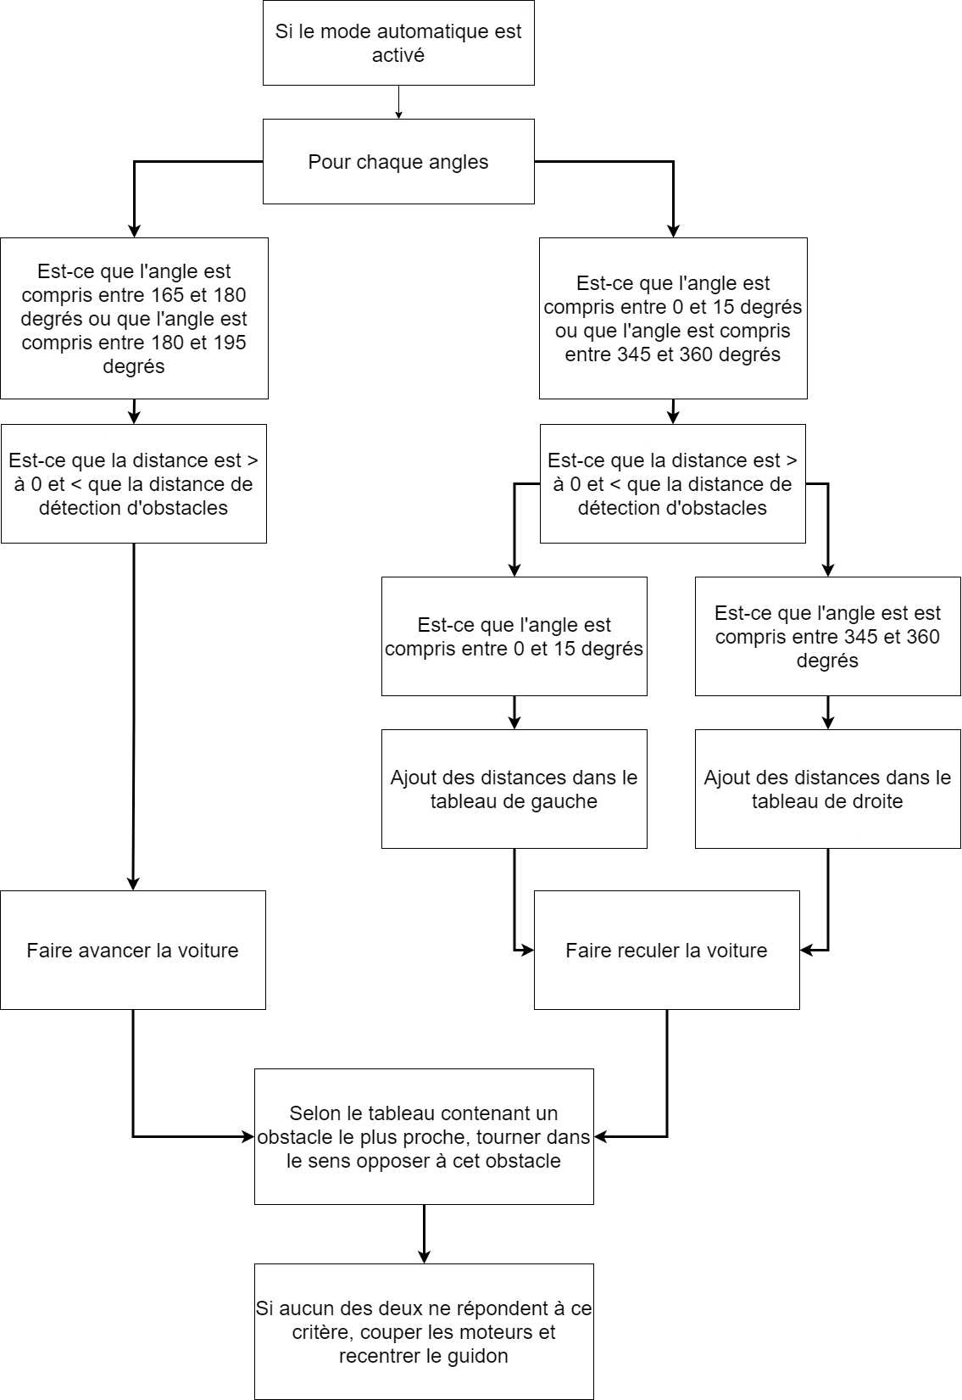
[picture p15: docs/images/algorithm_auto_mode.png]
Algorithme du mode automatique


#### Raspberry Pi 0 WiFi

##### À quoi servent-ils ?
Les raspberry pi 0 WiFi, sont utilisés pour gérer les caméras et les phares.

##### Comment on l'utilise ?
Il faut lancer sur chaque raspberry pi 0 WiFi le serveur Flask avec la commande : `python3 ACKERMANNGUE-AG_Dipl_Tech_2021_VoitureAssistee/code/Flask/flask_sensors_control/server.py`.
##### Comment fonctionne-t-il ?
Le serveur Flask proprose 2 routes :

###### Gestion des capteurs à distance
Pour gérer les capteurs à distance, j'utilise 2 serveurs Flask différents.

Le premier est le serveur principal tournant sur le Pi 4, celui sur lequel l'utilisateur sera pour avoir accès au tableau de bord, à la télécommande pour la voiture.

Le second est le serveur tournant sur les Pi 0 WiFi, son rôle est d'effectuer des actions en fonction des diverses routes utilisées. Il y a 2 routes très importantes.

1. `@app.route('/streaming_camera')`
2. `@app.route('/<string:sensor>/<int:state>', methods=['POST', 'OPTIONS'])`

1. Le flux vidéo de la caméra
2. La gestion des modules caméra et bright-pi

La seconde est celle qui effectue les actions sur les capteurs, voici un exemple : `192.168.50.230:5000/camera/1`. 

À noter, il est important d'utiliser `Flask-CORS` comme suit :

```python

...

from flask_cors import CORS
from flask_cors.decorator import cross_origin

...

app = Flask(__name__)
cors = CORS(app, withCredentials = True)

...

```

Chaque composant est considéré comme un capteur ayant pour valeurs de classes un nom ainsi qu'un état : 

Diagramme de classe Sensor

Vu que l'on accède à cette route depuis une autre adresse IP, il est nécessaire d'ajouter cette ligne `@cross_origin()` car elle permet de laisser l'accès à cette route depuis un autre domaine. De plus, il est important d'ajouter `'OPTIONS'` car lors de la première _lecture_ de CORS, cette méthode sera utilisée en tant qu'approbation de la part du serveur.

```python

@app.route('/<string:sensor>/<int:state>', methods=['POST', 'OPTIONS'])
@cross_origin()
def sensor_control(sensor=None, state=None):
"""
    Route used to manage the sensors

    sensors : The sensor's name
    state : The sensor's state
    """
    state = int(state)
    
    global brightpi_led_state
    global brightpi_ir_state
    global camera_state
    global light
    
    sensors = []
    # Check the request method
    if request.method == "POST": 
        # Change the state
        if sensor == constants.SENSOR_BRIGHTPI_LED:
            if state == constants.STATE_ON:
                brightpi_led_state = constants.STATE_ON
            elif state == constants.STATE_OFF:
                brightpi_led_state = constants.STATE_OFF
            light.set_led_on_off(brightpilib.LED_WHITE, brightpi_led_state)
        elif sensor == constants.SENSOR_BRIGHTPI_IR:
            if state == constants.STATE_ON:
                brightpi_ir_state = constants.STATE_ON
            elif state == constants.STATE_OFF:
                brightpi_ir_state = constants.STATE_OFF
            light.set_led_on_off(brightpilib.LED_IR, brightpi_ir_state)

        if sensor == constants.SENSOR_CAMERA:
            if state == constants.STATE_ON:
                camera_state = constants.STATE_ON
            elif state == constants.STATE_OFF:
                camera_state = constants.STATE_OFF

    # Add the sensors into the list
    sensors.append(Sensor(constants.SENSOR_BRIGHTPI_LED, brightpi_led_state))
    sensors.append(Sensor(constants.SENSOR_BRIGHTPI_IR, brightpi_ir_state))
    sensors.append(Sensor(constants.SENSOR_CAMERA, camera_state))

    return convert_array_to_json(sensors)

...

```

Dans la page du tableau de bord pour l'utilisateur se trouve l'appel AJAX qui va effectuer l'action :

```javascript

<script type="text/javascript">
const STATE_ON = 1;
const STATE_OFF = 0;

const CODE_FRONT = 0;
const CODE_RIGHT = 1;
const CODE_BACK = 2;
const CODE_LEFT = 3;
const CODE_OTHER = 4;

const SENSOR_CAMERA = "camera"
const SENSOR_LIDAR = "lidar"

const MODE_AUTOMATIC = "auto"

const IP_RSP_FRONT = 60;
const IP_RSP_RIGHT = 114;
const IP_RSP_BACK = 172;
const IP_RSP_LEFT = 218;
const IP_RSP_MAIN = 1;
const IP_NETWORK = "10.3.141.";

$(document).ready(function () {
    $("#form_dashboard :checkbox").change(function () {
        let endpoint = "";
        let ip_address = IP_NETWORK;
        // get the value of the checkbok, it can be "bright-pi", "camera" or "flying-fish"
        let cbx_value = $(this).val()
        // get the name of the checkbox
        let cbx_name = $(this).attr('name')
        // get the last char of the checkbox's name in order to know which side needs to be changed
        // example : cbxLight0, the 0 = the bright pi front sensors
        let code_position = parseInt(cbx_name.substring(cbx_name.length - 1, cbx_name.length))
        // reload the iframe of the selected camera
        if(cbx_value == SENSOR_CAMERA){
            var iframe = document.getElementById(`cnvCam${code_position}`);
            console.log(iframe.src)
            iframe.src = iframe.src
        }

        // choose the correct ip for the raspberry 
        switch (code_position) {
            case CODE_FRONT:
                ip_address+=IP_RSP_FRONT
                break;
            case CODE_RIGHT:
                ip_address+=IP_RSP_RIGHT
                break;
            case CODE_BACK:
                ip_address+=IP_RSP_BACK
                break;
            case CODE_LEFT:
                ip_address+=IP_RSP_LEFT
                break;
            case CODE_OTHER:
                ip_address+=IP_RSP_MAIN
                break;
            default:
                break;
        }
        // verify the state of the checkbox
        if (this.checked) {
            cbx_state = STATE_ON;
        } else {
            cbx_state = STATE_OFF;
        }
        // add the Flask port
        ip_address += ":5000";
        // set the URL
        endpoint = `http://${ip_address}/${cbx_value}/${cbx_state}`
        if(cbx_value == SENSOR_LIDAR){
            endpoint = `/bg_processing_lidar/${cbx_state}`;
            $("#lidar").attr("src", `/video_feed/${cbx_state}`);
        }
        if(cbx_value == MODE_AUTOMATIC){
            endpoint = `/launch_automatic_mode/${cbx_state}`;
        }
        execute(endpoint);
    });
});

function execute(endpoint) {
    $.ajax({
        url: endpoint,
        type: "POST",
        success: function (response) {
            console.log(response);
        },
        error: function (error) {
            console.log(error);
        },
    });
}

</script>

```

###### Récupération du flux vidéo
La méthode que j'utilise pour récupérer le flux vidéo de la caméra avec un serveur Flask est tirée de [ce github](https://github.com/EbenKouao/pi-camera-stream-flask).

Cette méthode se construit comme suit : 

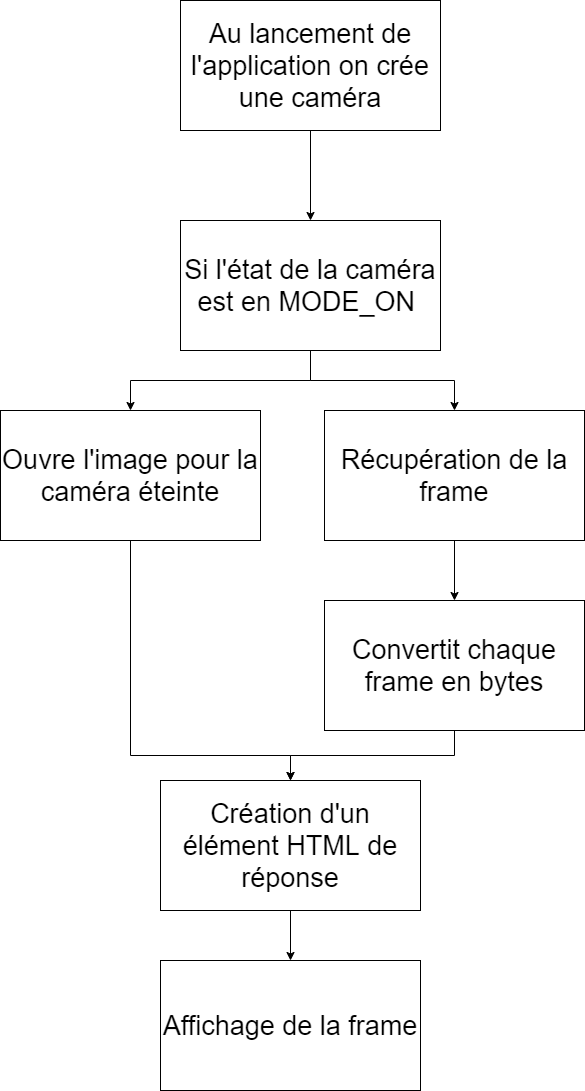
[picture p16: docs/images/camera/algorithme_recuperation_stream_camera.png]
Caméra et radar activé


Voici le code utilisé dans le fichier `server.py` présent dans le répertoire `\code\Flask\flask_sensors_control` :

```python

@app.route('/streaming_camera')
def cam_stream():
    global camera_state
    return render_template('index.html', name=constants.FRONT_CAM, mode=camera_state, on=constants.STATE_ON, off=constants.STATE_OFF)

def gen(camera):
    #get camera frame
    while True:
        frame = camera.get_frame()
        yield (b'--frame\r\n'
               b'Content-Type: image/jpeg\r\n\r\n' + frame + b'\r\n\r\n')

@app.route('/video_feed')
def video_feed():
    global pi_camera
    return Response(gen(pi_camera),
                    mimetype='multipart/x-mixed-replace; boundary=frame')

```

À noter, le code pour la caméra a été repris du GitHub, mais dans mon cas il a été important de le modifier car à la base la caméra avait comme nombre de frame par seconde à 30 ainsi qu'une qualité d'image de 480p ce que j'ai changé à la moitié afin d'éviter de surcharger le processeur du Raspberry Pi 4 :

```python

import cv2
from libs.pivideostream import PiVideoStream
import imutils
import time
import numpy as np

class VideoCamera(object):
    def __init__(self, flip = True, fps=15, res=(320, 256)):
        print("cam init")
        self.vs = PiVideoStream(resolution=res, framerate=fps).start()
        time.sleep(2.0)
        if self.vs != None:
            print("cam init done")
        self.flip = flip

    def __del__(self):
        print("cam del")
        self.vs.stop()

    def flip_if_needed(self, frame):
        if self.flip:
            return np.flip(frame, 0)
        return frame

    def get_frame(self):
        frame = self.flip_if_needed(self.vs.read())
        ret, jpg = cv2.imencode('.jpg', frame)
        return jpg.tobytes()
```

Voici le code `HTML` utilisé pour faire l'affichage de l'image :

```HTML
<title>{{name}}</title>
<meta name="viewport" content="width=device-width, initial-scale=1">
<link rel="stylesheet" href="https://cdnjs.cloudflare.com/ajax/libs/font-awesome/4.7.0/css/font-awesome.min.css">

<body>
  <div class="main" id="newpost">
    {% if mode == on %}
    <img class="camera-bg" style="width: 100%; height:80%; background-attachment: fixed;" id="bg" class="center"
      src="{{ url_for('video_feed') }}">
    {% elif mode == off %}
    <img class="camera-bg" style="width: 100%; height:80%; background-attachment: fixed;" id="bg" class="center"
      src="../static/img/camera_down.png">
    {% endif %}
  </div>
</body>
```

Cette image va donc être modifiée à chaque frame reçue par la caméra.

## Dates importantes

- Lundi 19 avril 2021 : Début du travail de diplôme
- Vendredi 30 avril 2021 : Évaluation intermédiaire 1
- Vendredi 14 mai 2021 : Rendu du rapport intermédiaire + poster
- Vendredi 14 mai 2021 : Rendu version intermédiaire du résumé et de l’abstract (pour conseils par l’enseignant d’anglais)
  Lundi 17 mai 2021 : Évaluation intermédiaire 2
- Jeudi 20 mai 2021 après-midi : Soirée poster : amis, famille, CFC, experts
  - 14h00 : Visite des classes de 1re année (cf. SG)
  - 16h30 : Amis, famille, experts, enseignants Tech ES…
  - 18h00 : Fin de la soirée poster
- Lundi 31 mai 2021 : Évaluation intermédiaire 3
- Vendredi 11 juin 2021 : Rendu du travail avant 12h00
- Jeudi 17 juin 2021 : Défenses à blanc + harmonisation des notes
- Lundi 21 juin ou mardi 22 juin 2021 : Défenses de diplôme

## Retour d'expérience

### Problèmes bloquants

Durant la conception de ce projet, n'étant pas assez préparée théoriquement dans l'univers qu'est l'informatique physique. J'ai rencontré de nombreux problèmes que j'ai su résoudre, mais qui m'ont fait prendre plus de temps que prévu sur certaines tâches.

#### Bluetooth

Le tout premier problème que j'ai eu était le problème de la connexion bluetooth à la voiture. Ce problème est celui qui m'a pris le plus du temps à résoudre, car je m'y étais mal pris dès le départ. La première erreur que j'ai faite a été de penser que pour se connecter à la voiture, il fallait utiliser notre propre connexion bluetooth à la voiture, ceci avec un script python utilisant le module bluetooth. J'ai donc été faire des recherches sur les potentiels manières de s'y connecter. 
La première librairie que j'ai essayée fut celle de [BrickNil](https://github.com/virantha/bricknil), mais je n'avais rien réussi à en faire. Ensuite, je suis tombé sur la libraire [pyb00st](https://github.com/JorgePe/pyb00st) mais en lisant sa documentation j'ai vu qu'il parlait d'un `BOOST Move Hub` pour son code et vu que j'utilisais un `Technic Hub` et que même visuellement il ne ressemblait pas au hub que j'utilisais, j'ai par conséquent cru que cela ne fonctionnerait pas. Cependant, dans la documentation de `pyb00st`, je me suis aperçu que pour se connecter à la voiture il utilisait 2 méthodes diverses avec le bluetooth. `Bluez` et `BlueGiga`, ayant entendu parler de `Bluez`, je m'étais dit qu'il fallait donc que je me connecte par moi même avec le bluetooth du raspberry pi à la voiture. J'ai donc repris le code que j'ai fait pour le t'chat bluetooth que j'ai tenté de modifier afin de me connecter à la voiture. Après plusieurs tentatives qui n'ont pas fonctionné, je suis tombé sur la libraire de [pylgbst](https://github.com/undera/pylgbst) et en lisant ce qu'il proposait, j'ai vu qu'il proposait différents types de connexion bluetooth (`gatt`, `bluepy` et `bleak`) et permettait la connexion avec un appareil à l'aide de sa mac adresse. Le truc qui m'a fait cogiter un moment, c'est que vu qu'il parlait du `LEGO BOOST Move Hub` lui aussi. Je m'étais donc dit que j'allais me concentrer sur l'envoie de commandes par le bluetooth à la voiture grâce à `pygatt`, car j'étais tombé sur [cette documentation](https://lego.github.io/lego-ble-wireless-protocol-docs/). J'ai vu qu'elle y proposait des commandes en bytes, exactement ce que je pensais avoir besoin. Après avoir tenté, 2-3 approches avec gatt, je me suis dit que j'allais aller fouiller dans le code `pylgbst` pour voir comment eux ils envoyaient leurs commandes. En fouillant, je me suis aperçu qu'il faisait exactement ce que j'avais besoin, c'est donc comme ça que j'ai pu m'apercevoir, sans que ce ne soit écrit quelque part, que le `Technic Hub` était considéré lui aussi comme un `Move Hub`, par conséquent, en utilisant le code de `pylgbst`, j'ai pu résoudre ce problème.

Durant quasiment toute la durée du projet j'ai eu des problèmes de connexion avec la voiture et ce car j'utilisais un singleton afin de recréer un objet `car` dans chaque méthode nécessitant l'appel aux méthodes de la voiture. Le problème était que lorsque je demandais une instance lors de la création de la voiture (sachant qu'il existait toujours une instance en cours), la connexion avec le bluetooth ne se faisait plus et cela faisait planter l'application.

#### Lidar

Le second problème auquel j'ai fait face a été celui de la récupération des données fournies par le Lidar. Là aussi, mon erreur a été de m'arrêter au code trouver durant le sprint 0. J'avais regardé en un premier temps ce que le site officiel du fabricant des Lidar, appelé [Slamtec](https://www.slamtec.com). Dans la section mettant à disposition le kit de développement, on y trouve un repository GitHub. Dans ce repository, on y trouve des fichiers écrits en C++, qui une fois compilée rendent les informations du lidar en temps réel dans la console. Ayant vu que le code fonctionnait parfaitement et qu'il s'agissait du code fournit par le fabricant officiel des Lidar, je me suis dit que c'était la meilleure option. Par conséquent, même si l'on dessoudait le port et qu'on soudait les câbles aux pins associés, je n'avais aucune idée de comment je pourrais récupérer ses informations étant donné que il n'y a pas une API qui me rend de valeur sûre. Du moins, c'est ce que je pensais, car après avoir compris ce qu'était ces 2 pins. Je me suis renseigné afin de voir si il n'y avait pas de moyen de récupérer les informations en python depuis ces pins. En faisant mes recherches, je suis tombé sur ce [repository GitHub](https://github.com/SkoltechRobotics/rplidar) qui permettait d'interagir avec le lidar connecté en USB. Cependant, le code C++ était déjà modifié en conséquence et  mon script python s'occupait de traiter les données reçues dans la console de manière asynchrone et pour finir je n'ai pas très bien compris sa manière dont il pouvait récupérer les distances pour les angles avec son code.

#### Alimentation

Le troisième problème majeur a été les problèmes d'alimentations. Ayant mis un système d'alimentation générale afin d'éviter de surcharger le courant des différents rapsberry pi, j'ai pu me rendre compte que certains éléments pompaient trop de courant et que par conséquent l'alimentation générale n'en fournissait pas suffisamment pour certain raspberry pi. Pour m'en rendre compte, j'ai du démonter la voiture, montée de A à Z afin d'y tester unitairement chaque composant pour m'assurer que ce n'était pas un problème matériel, ce qui m'a pris beaucoup de temps. Tout cela, pour me rendre compte qu'il s'agissait d'un problème de courant trop faible distribué par la batterie externe. 

### Résultat

Au cours de ces 2 derniers mois, j'ai pu mettre en place les différents capteurs et interagir avec eux : Le Bright Pi, La Camera, Le Flying-Fish ainsi que le Lidar. J'ai pu mettre le site web en place, celui permettant de gérer les capteurs et de voir les données qu'ils retournent. J'ai pu télécommander la voiture à distance depuis cette même interface et faire la voiture se déplacer en évitant des obstacles ainsi que la chute lorsqu'une roue ne détecte plus de sol.

### Ce qu'il reste à faire

Dans ce projet, il manque l'utilisation du GPS, l'affichage sur les caméras des carrés montrant les obstacles et leurs distances, l'insertion des choix pris par la voiture dans une base de données afin de pouvoir avoir accès aux logs, avoir une image de la voiture et des icônes signifiant à l'utilisateur quels capteurs sont allumés et lesquels sont éteints. La dernière chose qu'il manque est le système de pondérations des différents éléments, car pour l'instant cette pondération est équivalente pour tous les capteurs. C'est-à-dire que les flying-fish ont autant d'importance que le lidar en termes de priorités des opérations en fonction de leur pondérations.

### Améliorations possibles

#### Optimisation

En un premier temps, j'aimerai pouvoir ajuster le système automatique de la voiture, car je pense que l'on peut rendre la détection plus précise. 

Je pense que le code n'est pas très propre par moment, par conséquent que l'on pourrait optimiser certaine partie du code qu'il s'agisse de performance ou tout simplement de suppression de redondance dans certain cas. De plus, je pense que l'utilisation du Lidar branché sur les pins du GPIO du Raspberry Pi 4 serait moins coûteux énergétiquement et en termes de calculs pour le processeur.

D'une manière ou d'une autre, je pense qu'il est possible d'optimiser le code affichant le radar en un quasi-temps réel, car le problème qu'il y a avec le graphique, c'est que les images s'affichent à la suite et au fur et à mesure s'empilent, donc elles prennent du retard.

#### Caméra
On pourrait : 

* Faire en sorte que la voiture se déplace le long d'une ligne détectée au sol
* Enregistrer le flux vidéo afin de pouvoir les regarder plus tard depuis l'interface web.
* Mettre en place la reconnaissance de panneau et de feux de signalisation pour que la voiture réagisse en conséquence

#### Lidar
On pourrait faire la voiture se déplacer dans une certaine zone, que les données du lidar soient enregistrées afin de pouvoir cartographier une pièce. 

#### Capteur de son
On pourrait ajouter un système de commandes vocales à l'aide d'un capteur de son. Ces commandes seraient des instructions simples telles que `Connexion`, `Avance`, `Recule`, `Tourne à droite`, etc...

#### Interface utilisateur

Pour plus de praticité, je pense qu'il serait une bonne idée de rendre les caméras changeables à l'aide d'un balayage sur le côté :

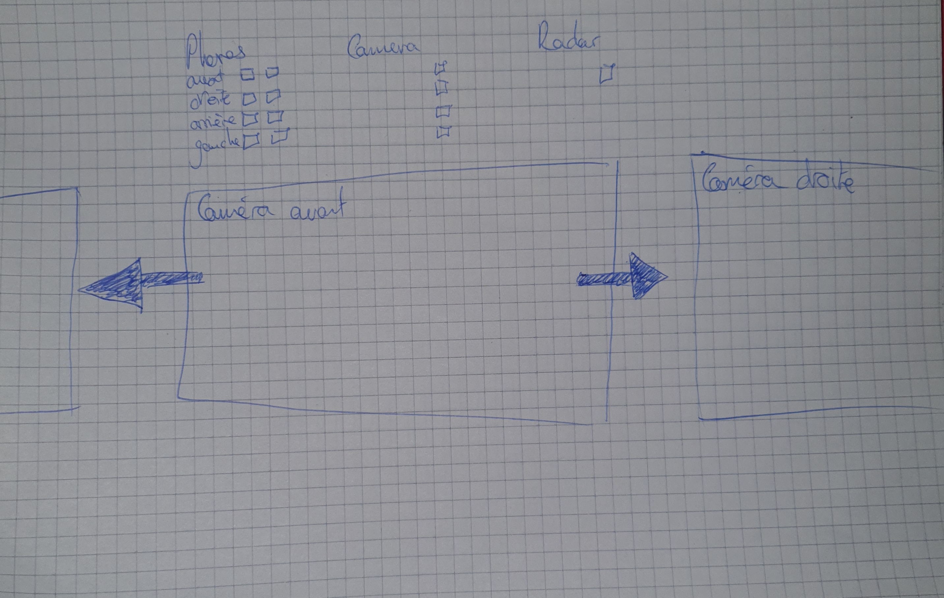
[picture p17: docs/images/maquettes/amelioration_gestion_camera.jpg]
Utilisation d'un balayage pour changer la caméra


### Apports personnels

| Fonctionnalité | Taux d'apport | Commentaire |
|:---:|:---:|:---:|
| Mise en place de serveurs Flask | 100% | |
| Utilisation du Bright Pi | 50% | La librairie fournit avec est très complète et simple d'utilisation |
| Utilisation du Flying-Fish | 80% | M. Bonvin m'a indiqué que l'on pouvait récupérer le signal depuis les pins étant des GPIO |
| Utilisation du Lidar | 70% | L'API C++ a été modifiée par moi pour rendre les distances des angles comme j'en avais besoin |
| Utilisation des caméras | 40% | J'ai utilisé le code d'EbenKouao pour avoir accès au flux vidéo à distance |
| Création d'un point d'accès | 40% | L'application RaspAP m'a permis de rapidement transformer un Raspberry Pi en point d'accès |
| Gestion de la voiture | 60% | Le code de pylgbst m'a été très bénéfique |
| Communication entre les divers appareils | 100% | |
| Gestion des capteurs à distance | 100% | |
| Affichage des données du Lidar sur un graphique | 70% | La librairie Matplotlib m'a permis d'afficher les données dans un format de graphique en cercle pour représenter un radar |

## Conclusion

Il s'est passé plein de choses durant ce travail de diplôme. Ces deux derniers mois ont mis mes connaissances informatiques à rude épreuve. Malgré les divers problèmes que j'ai pu rencontrer durant l'élaboration de ce projet, je suis très fier de ce que j'ai réussi à produire avec les connaissances actuelles que j'ai, n'étant pas un professionnel dans le domaine de l'informatique physique. Grâce à ces 2 mois j'ai pu apprendre de nombreuses choses. 

La première est qu'il est nécessaire d'avoir une approche méthodique et organisée face au travail qui nous est demandé de réaliser. Pour ma part, je devais réaliser une application permettant de contrôler une voiture à distance ainsi de pouvoir interagir avec les capteurs suivant :

- Caméra infrarouge
- Bright Pi
- GPS
- Flying-Fish
- RPLiDAR

Et de récupérer leurs données s'ils en retournent. L'élément que je n'ai pas pu implémenter a été le GPS ainsi que la fonctionnalité d'affichage des obstacles sur la caméra. Cependant, on peut avoir accès au radar 360° en temps réel, ce qui remplace à peu près cette fonctionnalité. De plus, avec mon projet on peut contrôler la voiture à distance et interagir en temps réel avec les capteurs attachés à la voiture à l'aide de son téléphone portable.

La seconde est qu'avoir une approche méthodique et rigoureuse est très important, car c'est en décomposant les diverses thématiques que l'on peut plus aisément prévoir les points bloquants afin de les résoudre. En plus de toutes les connaissances que j'avais, décomposer les problèmes auxquels j'ai fait face, m'a permis de les résoudre plus aisément. 

La dernière chose est la connaissance générale concernant l'informatique physique. De plus, je pense que c'est une très bonne chose de mettre ses compétences à l'épreuve de temps en temps, car connaissant les bases d'un domaine, si dans ce même domaine on donne tout ce qu'on a pour mener à bien un projet, ce dernier nous le rendra en acquisition de connaissances. 

C'est pourquoi je suis fier de ce que j'ai réalisé durant ce travail de diplôme et que s'il m'était demandé de refaire un projet similaire, je sauterais sur l'occasion sans hésiter, car pouvoir créer quelque chose de physique est très satisfaisant.

### Remerciements

Je souhaite remercier :

* M. Bonvin qui a su m'aiguiller dans ce projet
* M. Garcia qui a commandé les divers éléments nécessaires à la réalisation du projet

## Code source

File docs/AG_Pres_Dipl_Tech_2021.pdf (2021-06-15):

Travail de diplôme 2021, CFPT-Informatique | Ackermann Gawen
V1.0

# Voiture Assistée

## Sommaire

PROJET

DÉMONSTRATION

01

03

02
04

05

06

FONCTIONNEMENT DE L’APPLICATION

ÉLÉMENTS TECHNIQUES

CONCLUSION

QUESTIONS

# PROJET

01

## Voiture Assistée

Le but du projet est réaliser une voiture autonome sachant se déplacer en évitant les obstacles sur son chemin. À l’aide d’une interface web, on peut gérer et voir les données des capteurs installés

## Enseignant

- M. Bonvin

5

## Technologie existante

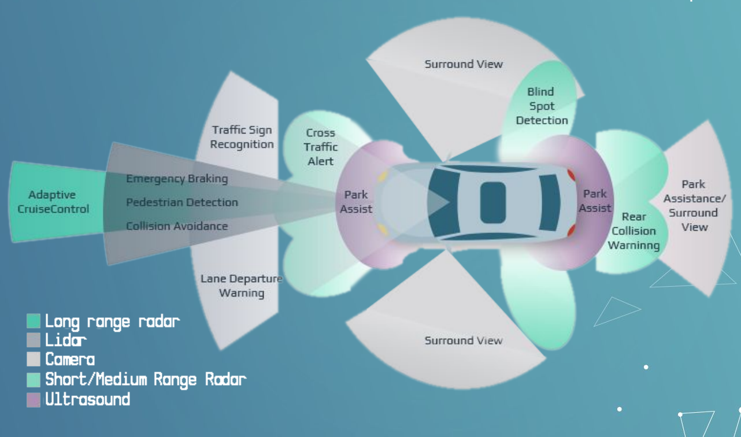
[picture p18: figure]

Une voiture autonome est souvent constituée des mêmes capteurs

## Technologies utilisées

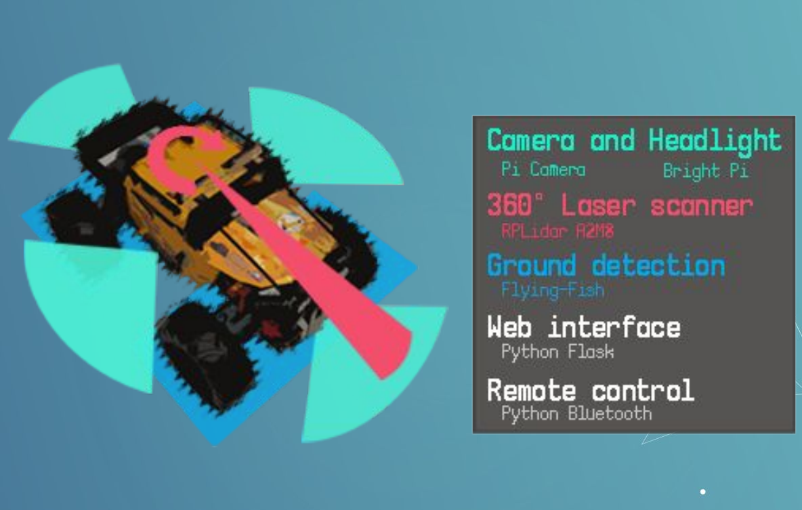
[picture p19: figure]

## Technologies utilisées

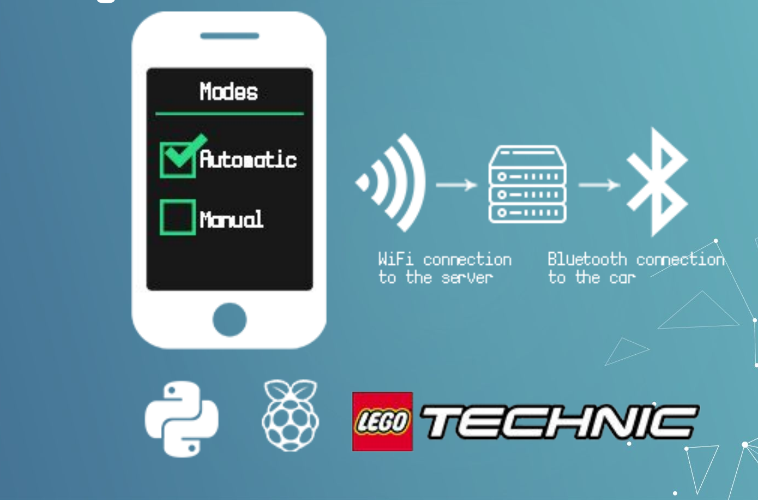
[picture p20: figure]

# DÉMONSTRATION

02

# FONCTIONNEMENT DE L’APPLICATION

03

## Schéma général

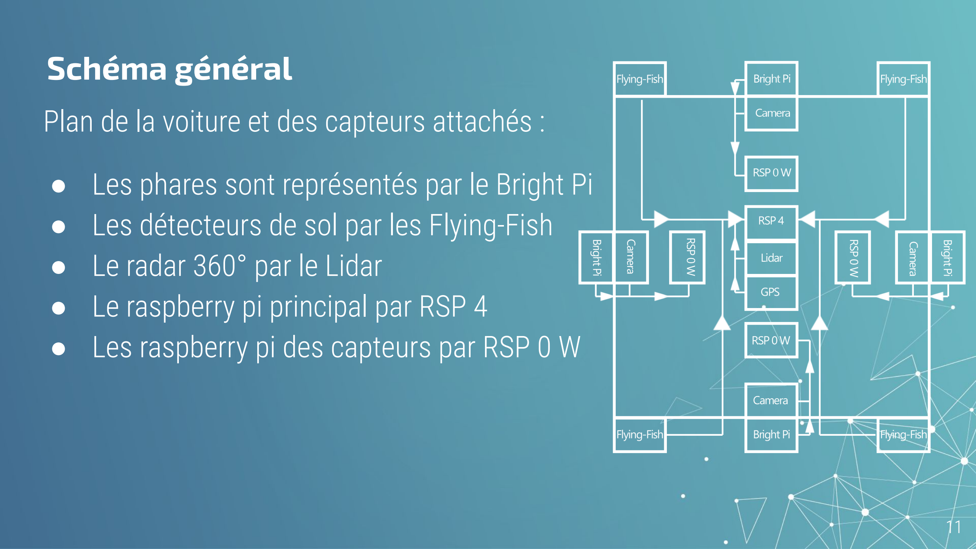
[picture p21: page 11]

Plan de la voiture et des capteurs attachés :

- Les phares sont représentés par le Bright Pi
- Les détecteurs de sol par les Flying-Fish
- Le radar 360° par le Lidar
- Le raspberry pi principal par RSP 4
- Les raspberry pi des capteurs par RSP 0 W

## L’application

L’utilisateur peut depuis l’interface web :

- Se (dé)connecter à la voiture par bluetooth
- Télécommander la voiture
- Gérer l’état des divers capteurs installés
- Avoir accès aux données fournies par les capteurs
- Gérer l’activation du mode automatique

## L’application

L’application est divisé en 2 serveurs différents :

- Serveur principal (connexion à la voiture, télécommande, tableau de bord, …)
- Serveur des capteurs

Le serveur principal tourne sur un Raspberry Pi 4

Le serveur des capteurs tourne indépendamment sur chaques Raspberry Pi 0 WiFi

## L’application

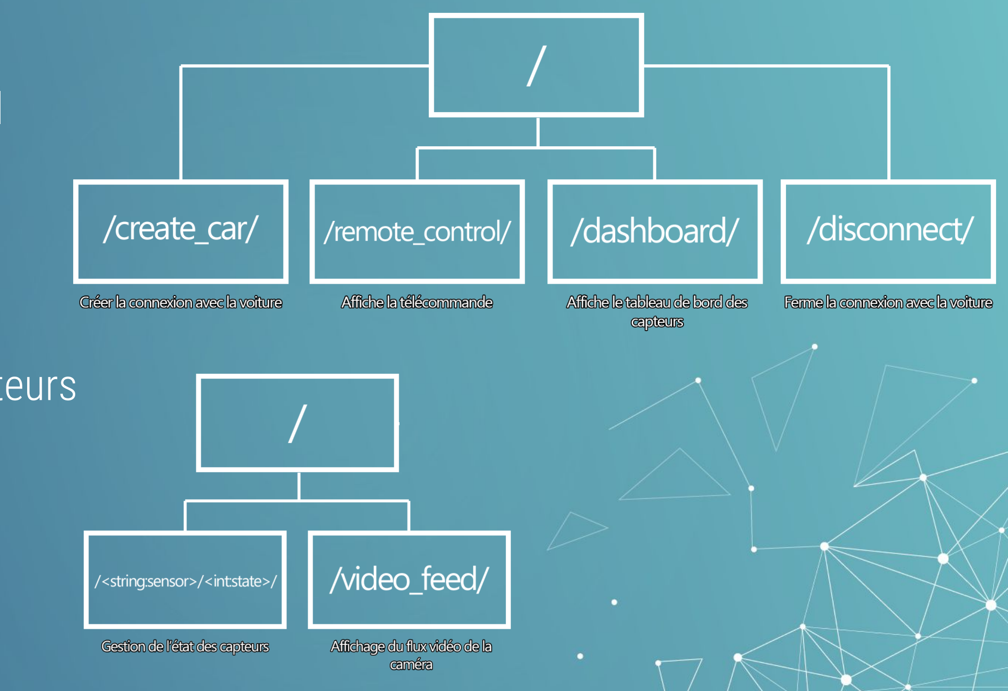
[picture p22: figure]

- Serveur principal
- Serveur des capteurs

# ÉLÉMENTS TECHNIQUES

04

## Récupération des données du Lidar

- Utilisation de l’API C++ fourni par Slamtec

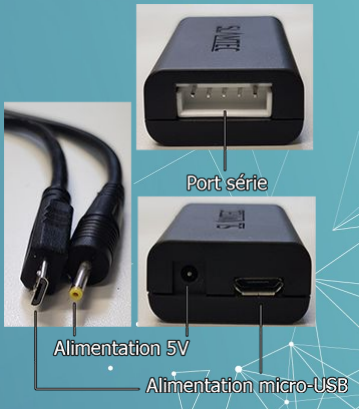
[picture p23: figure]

- Branchement à l’adaptateur

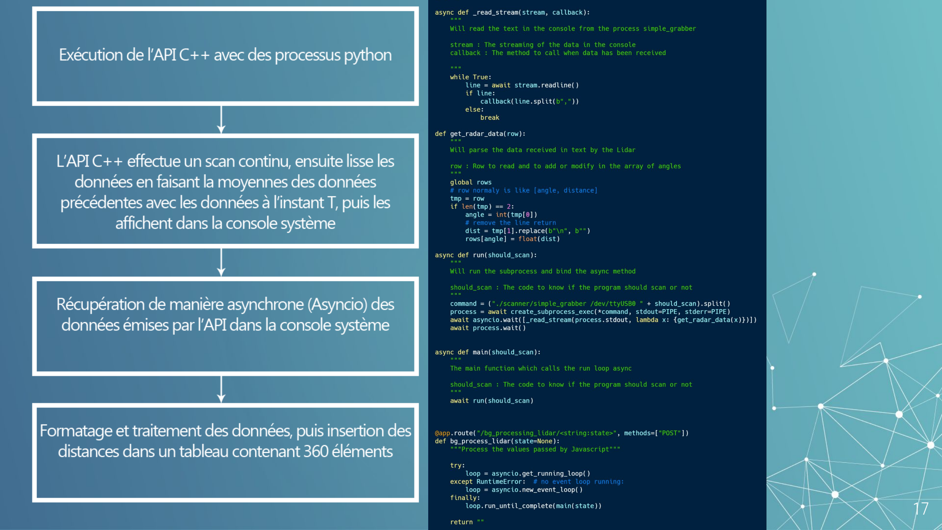
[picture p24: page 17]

## Code C++ modifié


## Récupération des données du Lidar


- Dessouder les câbles branchés au port série pour les souder sur le GPIO du Raspberry Pi 4

## Connexion à la voiture avec le Bluetooth


- Tentative de connexion à l’aide de gatt ○ Connexion établie, mais

toujours pas
télécommandable
- Tentative d’envoi de
commandes en bytes

## Connexion à la voiture avec le Bluetooth


# CONCLUSION

05

## Ce qui devait être fait

Réaliser une interface web accessible depuis le téléphone qui permet :

- De contrôler la voiture
- D’activer le mode automatique
- De gérer les capteurs installés
- De voir les données des capteurs
- D’enregistrer les données GPS
- Afficher les obstacles encadrés avec leurs distance par rapport à la voiture sur les caméras
- D’enregistrer les actions menées par la voiture

## Ce qui a été réalisé

- Interface web accessible depuis le téléphone
- Contrôle de la voiture
- D’activer le mode automatique
- De gérer les capteurs installés
- De voir les données des capteurs

## Ce qu’il reste à faire

- D’enregistrer les données GPS
- Afficher les obstacles encadrés avec leurs distance par rapport à la voiture sur les caméras
- D’enregistrer les actions menées par la voiture

Merci de votre attention,

## Avez-vous des questions ?

06


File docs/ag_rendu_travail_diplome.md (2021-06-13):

# Rendu du travail de diplôme
Vous trouverez ci-dessous les éléments importants : 

## Repository du projet
Pour avoir accès au code source, rendez vous sur mon repository git ici présent : 
L'entièreté du code est placée dans le répertoire `code`.
https://github.com/ACKERMANNGUE/ACKERMANNGUE-AG_Dipl_Tech_2021_VoitureAssistee

## Documentation du projet
Pour avoir accès à la documentation du projet, veuillez vous rendre sur ce lien : https://ackermanngue-ag-dipl-tech-2021-voitureassistee.readthedocs.io/fr/latest/index.html

## Documentation du code du projet
Pour avoir accès à la documentation du code générée avec Doxygen il faut télécharger le repository du projet à cette adresse : https://github.com/ACKERMANNGUE/ACKERMANNGUE-AG_Dipl_Tech_2021_VoitureAssistee. 

Une fois le repository téléchargé, allez dans le répertoire `\docs\Doxygen\html`, puis ouvrez le fichier html nommé : `files.html`.
Une fois ouvert, vous pourrez avoir accès au code commenté que j'ai écrit. 
Par exemple, si vous souhaitez voir le code sur serveur principal, cliquez sur le fichier `server.py` présent dans `\code\Flask\flask_server\`. Une page comme celle-ci apparaîtra :

Interface de l'arborescence du projet

Depuis cette page, vous aurez accès aux divers méthodes présentes dans le fichier. Si vous cliquez sur une des méthodes, vous serez redirigé vers la description de cette dernière:

Interface des méthodes présentes dans un fichier

Interface des méthodes présentes dans un fichier décrites

Pour voir les divers mini projets de tests élaborés qui m'ont servis à implémenter les divers éléments, allez dans le répertoire `Toolbox`. Ce répertoire contient aussi des codes d'exemples trouvés sur internet.

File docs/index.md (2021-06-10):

--- 
title: "Page d'accueil de la documentation en ligne"
author: Ackermann Gawen
---
# Bienvue sur la documentation en ligne de Voiture Assistée

## Navigation

Pour lire : 

* la documentation technique du projet, cliquez sur l'onglet `Documentation technique de Voiture Assistée`
* le journal de bord, cliquez sur l'onglet `Journal de bord du projet`
* le guide de mise en place des différents éléments utilisés, cliquez sur l'onglet `Guide de mise en place des différents logiciels et matériels utilisés`


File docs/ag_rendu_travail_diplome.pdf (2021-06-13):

ag_rendu_travail_diplome.md | 6/13/2021


1 / 2

# Rendu du travail de diplôme

Vous trouverez ci-dessous les éléments importants :

## Repository du projet

Pour avoir accès au code source, rendez vous sur mon repository git ici présent : L'entièreté du code est placée dans le répertoire code. https://github.com/ACKERMANNGUE/ACKERMANNGUE-AG_Dipl_Tech_2021_VoitureAssistee

## Documentation du projet

Pour avoir accès à la documentation du projet, veuillez vous rendre sur ce lien : https://ackermanngue-agdipl-tech-2021-voitureassistee.readthedocs.io/fr/latest/index.html

## Documentation du code du projet

Pour avoir accès à la documentation du code générée avec Doxygen il faut télécharger le repository du projet à cette adresse : https://github.com/ACKERMANNGUE/ACKERMANNGUE-AG_Dipl_Tech_2021_VoitureAssistee.

Une fois le repository téléchargé, allez dans le répertoire \docs\Doxygen\html, puis ouvrez le fichier html nommé : files.html. Une fois ouvert, vous pourrez avoir accès au code commenté que j'ai écrit. Par exemple, si vous souhaitez voir le code sur serveur principal, cliquez sur le fichier server.py présent dans \code\Flask\flask_server\. Une page comme celle-ci apparaîtra :

Depuis cette page, vous aurez accès aux divers méthodes présentes dans le fichier. Si vous cliquez sur une des méthodes, vous serez redirigé vers la description de cette dernière:


ag_rendu_travail_diplome.md | 6/13/2021

2 / 2

Pour voir les divers mini projets de tests élaborés qui m'ont servis à implémenter les divers éléments, allez dans le répertoire Toolbox. Ce répertoire contient aussi des codes d'exemples trouvés sur internet.

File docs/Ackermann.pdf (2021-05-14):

Ackermann Gawen | 14.05.2021 | T.IS-E2A

## Résumé

Voiture assistée est un projet d'étude portant sur les voitures autonomes et leur fonctionnement. Ce projet m'a été proposé par M. Bonvin étant donné que la première ébauche du cahier des charges comportait en une simulation de voiture autonome mais ce dans une application windows form. M. Bonvin ayant entendu parler de mon projet, il a su amener un côté plus intéressant et professionnel dans le travail que je vais devoir réaliser. Étant donné la découverte des différents appareils utilisés pour ce projet, la plus value sera surtout l'acquisition de nouvelles connaissances dans le domaine de l'informatique physique. Par conséquent, le but du projet est de réaliser une voiture se déplaçable à l'aide d'une interface web et qui sait se déplacer par elle-même en évitant les obstacles sur sa route.

## Abstract

Voiture assistée is a study project about autonomous cars and their functioning. This project was proposed to me by Mr. Bonvin since the first draft of the specifications included a simulation of an autonomous car but in a windows form application. Mr. Bonvin heard about my project, he knew how to bring a more interesting and professional side in the work that I will have to realize. Considering the discovery of the different devices used for this project, the added value will be especially the acquisition of new knowledge in the field of physical computing. Therefore, the goal of the project is to realize a car that can be moved by a web interface and that knows how to move by itself and which avoids obstacles on its way.

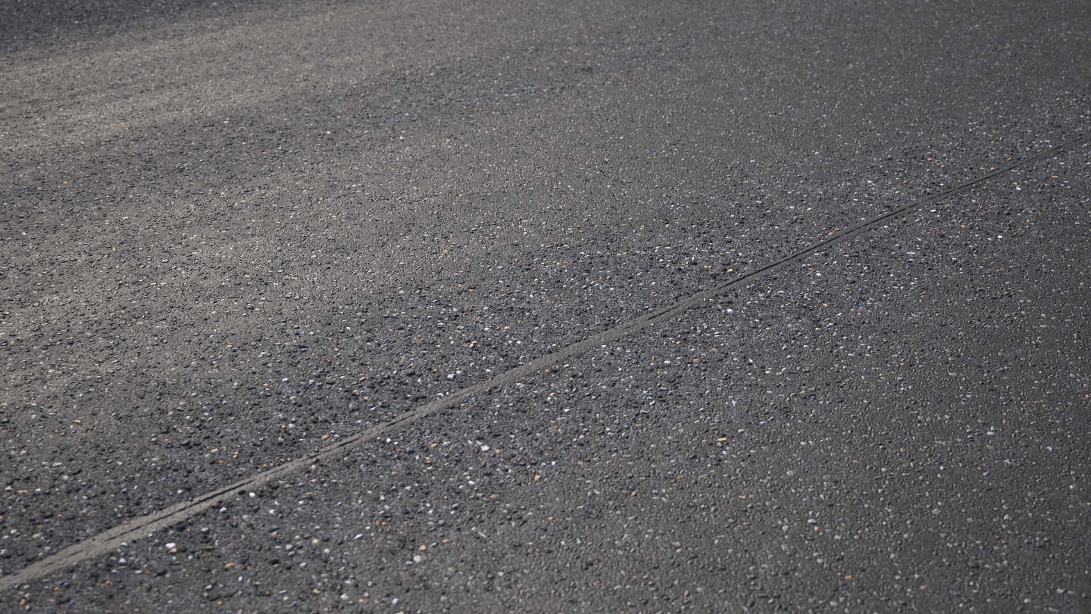
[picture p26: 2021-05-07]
docs/images/references_poster/texture_road.jpg

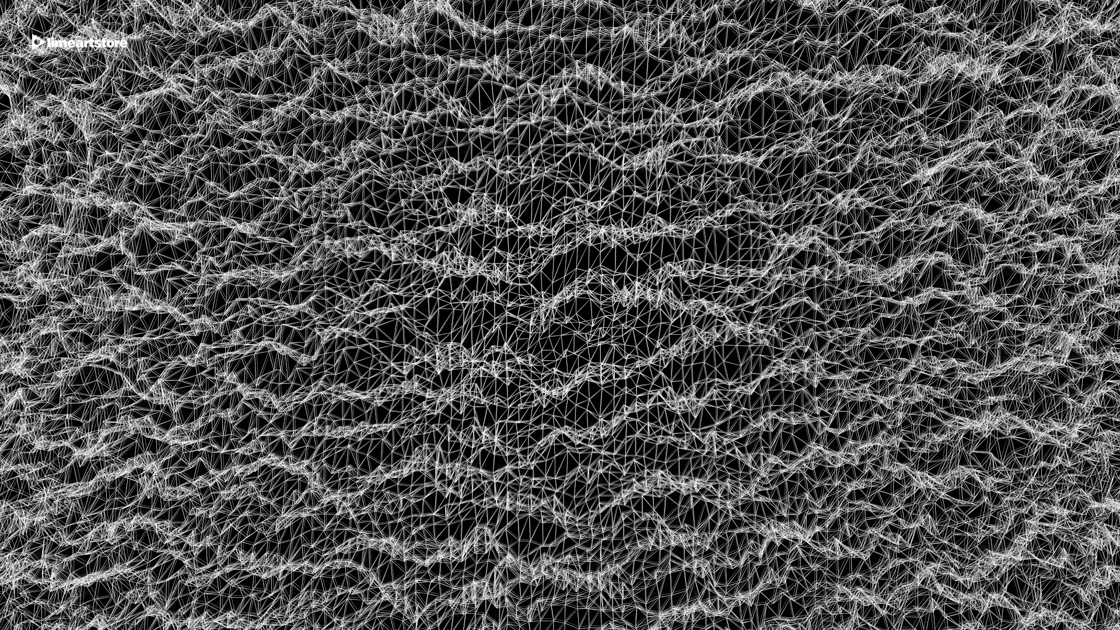
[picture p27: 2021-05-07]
docs/images/references_poster/texture_wireframe.jpg

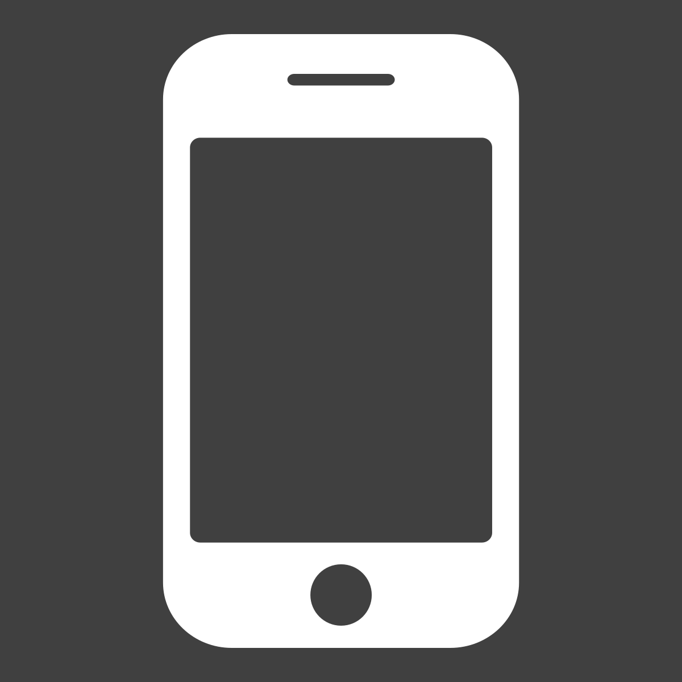
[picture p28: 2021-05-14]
docs/images/references_poster/smartphone.png

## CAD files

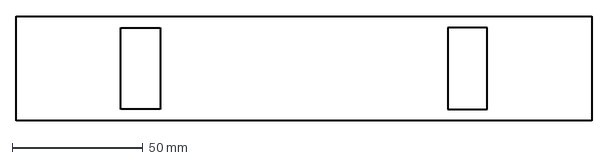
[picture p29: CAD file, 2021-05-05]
docs/plans/plaque_avant-arriere.dxf
220.0 x 40.0 mm

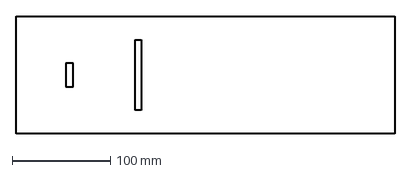
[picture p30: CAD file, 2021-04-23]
site/plans/plaque_superieure.dxf
385.0 x 120.0 mm

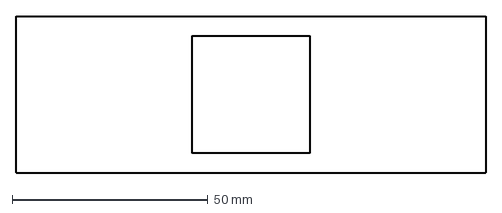
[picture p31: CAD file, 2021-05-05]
docs/plans/plaque_cote_droite-gauche.dxf
120.0 x 40.0 mm

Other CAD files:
docs/plans/plaque_superieure.dxf

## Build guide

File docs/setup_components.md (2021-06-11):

--- 
title: "Guide de mise en place des différents logiciels et matériels utilisés"
author: Ackermann Gawen
---
# Guide de mise en place des différents logiciels et matériels utilisés

## Description détaillée de chaque capteur

### Raspberry Pi

Il s'agit d'un mini-ordinateur de la taille d'une carte de crédit équipée de différents capteurs, cela dépend du modèle.

#### Mise en place

En fonction du modèle du Raspberry Pi, il faut flasher les cartes SD avec différents OS avec le [Raspberry Pi Imager](https://www.raspberrypi.org/software/) :

- Pour un Raspberry Pi 4, installé la version `Raspberry Pi OS Full (32-bit)` pour faire les tests à l'aide d'une interface graphique
- Pour un Raspberry 0 WiFi, installé la version `Raspberry Pi OS Lite (32-bit)` utilisé juste pour transiter des données

#### Utilisation

##### Pi 4

Un Raspberry Pi 4B est constitué des différents éléments :

Schéma du Raspberry Pi 4 montrant où se situent chaque composant Schéma du Raspberry Pi montrant où se situent chaque composant Pour le GPIO, voici les pins disponibles :

Schéma du Raspberry Pi montrant où se situent les GPIO (General Purpose Input/Output)

À noter, la pin numéro 1 se situe à côté du module Bluetooth tandis que la pin 39 se situe en diagonal du `PoE HAT Header`.

##### Pi 0 WiFi

Le Pi 0 WiFi détient moins d'éléments que le Pi 4, cependant il en détient quelque-uns de différents tel que :

Schéma du Raspberry Pi 0 Wifi montrant où se situent chaque composant

#### Images des Raspberry Pi
Les images qui ont été faites pour les différents raspberry pi nécessitent de télécharger divers paquets. Ces paquets doivent être installés sur les divers raspberry pi afin de lancer les différents scripts.

##### Pi 4

Voici la liste des commandes à effectuer dans l'ordre :

Pour mettre à jour le raspberry pi, utilisez la commande : `sudo apt update && sudo apt full-upgrade`
Ensuite, il faut installer git : `sudo apt install git`.

- Cloner le repos : `git clone https://github.com/ACKERMANNGUE/ACKERMANNGUE-AG_Dipl_Tech_2021_VoitureAssistee`
- Installer les dépendences :
    - `sudo apt install python3-pip`
    - `sudo pip3 install flask`
    - `sudo pip3 install flask_bootstrap`
    - `sudo pip3 install flask_nav`
    - `sudo pip3 install flask_cors`
    - `sudo pip3 install pylgbst`
    - `sudo pip3 install gatt`
    - `sudo pip3 install pygatt`
    - `sudo pip3 install matplotlib`
    - `sudo pip3 install -U numpy`
    - `sudo apt install libatlas-base-dev`
    - `sudo apt install bluetooth pi-bluetooth bluez blueman`
    - `sudo pip3 install RPi.GPIO`
    - `sudo pip3 install opencv-python`
    - `sudo pip3 install smbus`
    - `sudo pip3 install dbus`
    - `sudo pip3 install asyncio`

##### Pi 0 WiFi

Pour mettre à jour le raspberry pi, utilisez la commande : `sudo apt update && sudo apt full-upgrade`
Ensuite, il faut installer git : `sudo apt install git`.

- Cloner le repos : `git clone https://github.com/ACKERMANNGUE/ACKERMANNGUE-AG_Dipl_Tech_2021_VoitureAssistee`
- Installer les dépendences :
    - `sudo apt install python3-pip`
    - `sudo pip3 install flask`
    - `sudo pip3 install flask_cors`
    - `sudo pip3 install libwebp-dev`
    - `sudo pip3 install libtiff-dev`
    - `sudo pip3 install libopenjp2-7`
    - `sudo pip3 install libilmbase-dev`
    - `sudo pip3 install libopenexr-dev`
    - `sudo pip3 install opencv-python`
    - `sudo pip3 install smbus`
    - `sudo pip3 install picamera`
    - `sudo pip3 install imutils`

##### Clonage de carte SD

Pour cloner les cartes SD, j'utilise le programme [balenaEtcher](https://www.balena.io/etcher/). 
Une fois les cartes SD branchées en USB au PC, lorsque le programme est lancé, il faut sélectionner le disque à copier, puis le disque sur lequel la copie doit être effectuée et cliquer sur `Flash` : 

Différentes étapes d'utilisation de balenaEtcher

### Ventilateur

Un ventilateur dans le cadre informatique est utilisé afin de faire descendre la température du processeur, car lorsqu'il fait beaucoup de traitement en même temps, il surchauffe et ceci peut causer des problèmes matériels. 

Le ventilateur est nécessaire, car lorsque toutes les caméras sont allumées et que le lidar tourne, sans le ventilateur, le processeur atteint des températures excédant 70° Celsius tandis qu'avec le ventilateur cette température est limitée à 55° Celsius.

Entre temps, je suis passé du ventilateur de gauche à celui de droite :

Deux ventilateurs que j'ai utilisé

Celui de gauche était temporaire. Je l'avais démonté d'un vieux disque dur, car j'avais demandé à ce que l'on en commande pour un raspberry pi étant donné que mon processeur surchauffait. 

#### Mise en place

Pour le connecter, il faut brancher le câble d'alimentation (rouge) sur la pin 4, le câble de la terre (noir) sur la pin 6 et le câble de transmission (bleu) sur la pin 8  du GPIO comme le montre la boîte dans laquelle le ventilateur était : 

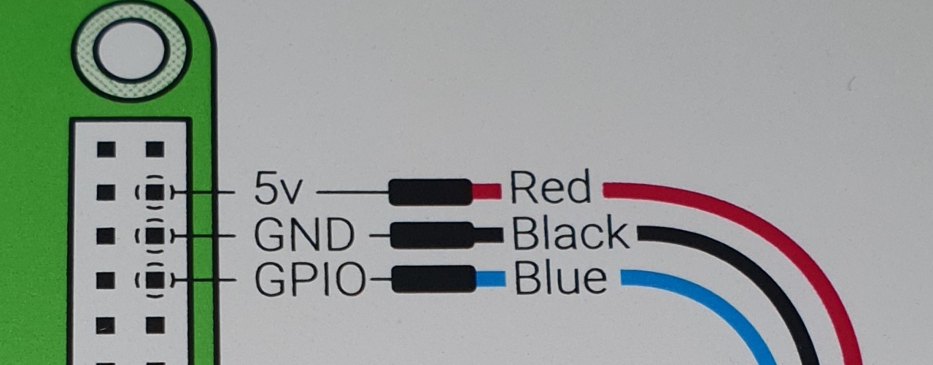
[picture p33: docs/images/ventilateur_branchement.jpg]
Branchement du ventilateur pour le Raspberry Pi


Étant donné qu'il est fournit avec un socle, socle qui est démontable. Je ne l'ai pas enlevé, car sinon il aurait été difficle de faire tenir le ventilateur, car il toucherait le processeur. C'est pourquoi j'ai utilisé un élastique afin de le maintenant sur le Raspberry Pi 4 :

Placement du ventilateur avec un élastique

L'élastique passe sous le Raspberry Pi 4, et est tenu par les branches présentes sur les côtés.

### Caméra

La caméra est un module permettant d'avoir accès à un flux vidéo.

#### Mise en place

J’ai utilisé le guide de la caméra disponible sur sur le [site officiel de MagPi](https://magpi.raspberrypi.org/books). Pour commencer, j’ai activé la caméra dans le panneau de configuration du Raspberry Pi, puis j’ai branché la caméra dans l’emplacement prévu qui se situe entre la prise jack et les ports HDMI.

Si vous branchez une caméra à un Pi 4 :

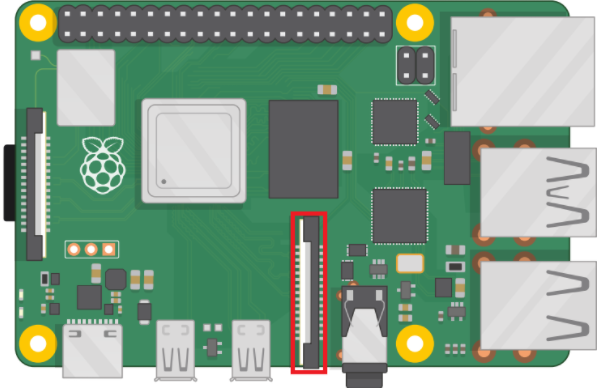
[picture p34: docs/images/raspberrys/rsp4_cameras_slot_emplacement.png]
Schéma du Raspberry Pi 4 montrant où se situe le port d’entré pour la caméra


Si vous branchez une caméra à un Pi 0 WiFi :

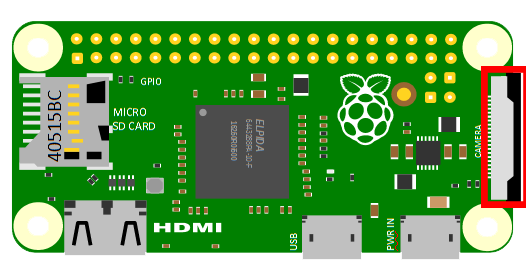
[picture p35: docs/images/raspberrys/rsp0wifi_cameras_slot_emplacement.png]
Schéma du Raspberry Pi 0 WiFi montrant où se situe le port d’entré pour la caméra


Le ruban de la caméra doit être placé de sorte que la languette bleue fasse face à la prise jack. Pour m’assurer que la caméra soit fonctionnelle, j’utilise la commande suivante pour prendre une photo `raspistill -o test.jpg`.

À noter que si vous utiliser une caméra sur un Raspberry Pi 0 WiFi, il faut le câble orange comme ci-dessous :

Différents câbles pour la caméra

#### Utilisation

Pour vérifier qu'un flux vidéo pouvait être lu, j'ai utilisé le code ci-dessous :

```python
from picamera import PiCamera
from time import sleep

camera = PiCamera()

camera.start_preview()
sleep(5)
camera.stop_preview()
```

À noter, il est nécessaire d'exécuter ce code depuis le Raspberry Pi et non par VNC, car l'affichage de la prévisualisation du flux ne s'affiche pas. D'après [ce post](https://raspberrypi.stackexchange.com/questions/29537/sending-raspberry-pi-camera-preview-to-a-laptop-running-vnc-viewer) disponible sur StackEchange, il semblerait que l'aperçu de la caméra soit géré à un bas niveau dans le processeur graphique et par conséquent n'est visible que par le moniteur directement branché au Raspberry Pi.

### Phare (Bright Pi v1.0)

Le Bright Pi est un module comportant 4 leds infrarouges situées aux extrémités et au centre 8 leds.

#### Mise en place

Pour l’utilisation du Bright Pi, je me suis basé sur le guide disponible à l’adresse suivante : https://learn.pi-supply.com/make/bright-pi-quickstart-faq/. J’ai commencé par activer l’I2C dans le panneau de configuration du Raspberry Pi puis j’ai branché les pins aux emplacements indiqués dans le guide de démarrage. Les couleurs ci-dessous doivent être respectées (pour le placement uniquement).
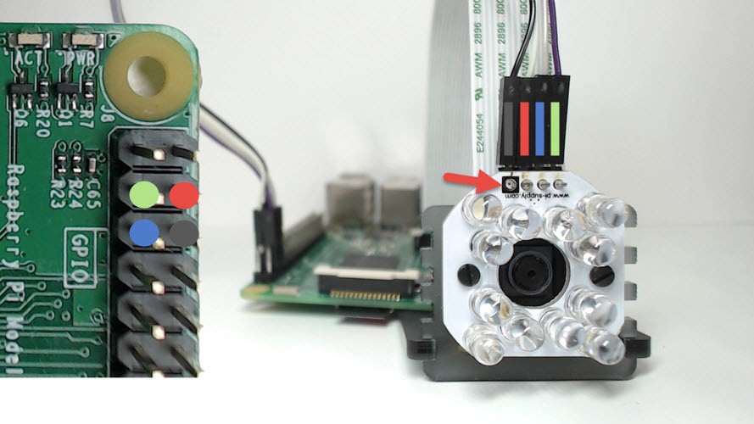
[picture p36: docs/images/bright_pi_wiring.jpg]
Branchement du Bright Pi


Pour s'assurer que le branchement soit correct, il est nécessaire d'utiliser la commande `i2cdetect -y 1`. Ceci devrait être affiché dans la console :

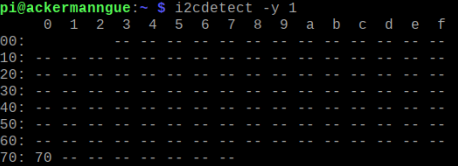
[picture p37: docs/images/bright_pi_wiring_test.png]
Commande affichant le branchement du Bright Pi


Pour tester le Bright Pi, il est nécessaire d'avoir le kit de développement disponible sur [ce repos Github](https://github.com/PiSupply/Bright-Pi).

#### Utilisation

Une fois cela fait, il faut importer les éléments concernant le brightpi avec

```python
from brightpi import *
import time
```

Pour faire clignoter les leds manuellement (à l’aide de lignes de code) j’aurai pu utiliser l’objet BrightPi, mais j’ai finalement utilisé le BrightPiSpecialEffects, car il permet d’avoir accès à des fonctions prédéfinies concernant la manipulation des leds, par exemple à les faire s’allumer une à une dans le sens des aiguilles d’une montre, ce qui peut devenir utile par la suite du travail. Voici le code que j'ai écrit. Ce code permet de faire clignoter les leds d'un côté spécifié.

```python
def blink(repetitions, speed, right_leds, left_leds, side):
    # fait clignoter les leds des côtés spécifiés
    duration = speed / 2
    leds_to_activate = []
    leds_to_desactivate = []
    for i in range(0, repetitions):
        if side == "L":
            leds_to_activate = left_leds
            leds_to_desactivate = right_leds
        if side == "R":
            leds_to_activate = right_leds
            leds_to_desactivate = left_leds

        bright_special.set_led_on_off(leds_to_desactivate, OFF)
        bright_special.set_led_on_off(leds_to_activate, ON)
        time.sleep(duration)
        bright_special.set_led_on_off(leds_to_activate, OFF)
        time.sleep(duration)

bright_special = BrightPiSpecialEffects()
bright_special.reset()

RIGHT_LEDS = [1, 2]
LEFT_LEDS = [3, 4]

blink(10, 1, RIGHT_LEDS, LEFT_LEDS, "R")
```

### Détecteur infrarouge (Flying-Fish)

Le Flying-Fish est un module comportant 2 leds infrarouges, une qui émet et une autre qui reçois. Il est équipé d'un potentiomètre réglant la distance d'émission.

#### Mise en place

Comme le montre ce schéma, le Flying-Fish doit être connecté à une alimentation ainsi qu'à un _Ground_ (appelé _Terre_ en français). La dernière broche est la sortie. C'est-à-dire que lorsque la distance d'émission réglée à l'aide du potentiomètre est dépassée, la lumière d'obstacle s'éteindra et cette broche enverra un signal électrique informant du changement d'état.

Schéma du module Flying-Fish Commande affichant le branchement du Bright Pi

Il faut importer l'accès au GPIO du Raspberry Pi avec :

```python
import RPi.GPIO as GPIO
```

#### Utilisation

C'est pourquoi, j'ai branché le _Vcc_ sur la pin 1 du GPIO, car le voltage accepté est compris entre 3 et 6 Volts, ensuite j'ai branché le _Gnd_ sur la pin 6. J'ai branché le _Out_ à la pin 16 (GPIO 23). Voici le code de test :

```python
import RPi.GPIO as GPIO
import time

# Set the mode into Broadcom SOC channel
# It allows to use GPIO number instead of pin number
GPIO.setmode(GPIO.BCM)

# Set the GPIO 23 into input mode
GPIO.setup(23, GPIO.IN)

while True:
    # The actual state of the GPIO 23
    input_state = GPIO.input(23)
    if input_state == True:
        print("ATTENTION ! IL N'Y A PLUS DE SOL !")
        time.sleep(0.5)
    else:
        print("Sol détecté")
        time.sleep(0.5)
```

### Connexion bluetooth avec le LEGO 4x4 X-trem Off-Roader

Le LEGO 4x4 X-trem Off-Roader est une voiture télécommandable en bluetooth.

#### Mise en place

Dans un premier temps, il faut installer `bleak`, `pygatt` et `bluepy` pour ce faire, j'ai utilisé cette commande : `sudo pip3 install pygatt && pip3 install gatt && pip3 install gattlib && pip3 install bluepy && pip3 install bleak` puis j'ai télécharger le code sources du [repository pylgbst](https://github.com/undera/pylgbst).
Pour tester la connexion bluetooth, j'ai lancé la commande `sudo bluetoothctl`, ensuite j'ai lancé les commandes suivantes : `power on` pour m'assurer que le service soit actif, puis `scan on`. Une fois que des appareils ont été détectés, on peut lancer l'interface graphique située dans la barre des tâches :

Bluetooth interface depuis barre des tâches
ou il est possible d'aller dans les préférences pour l'ouvrir :

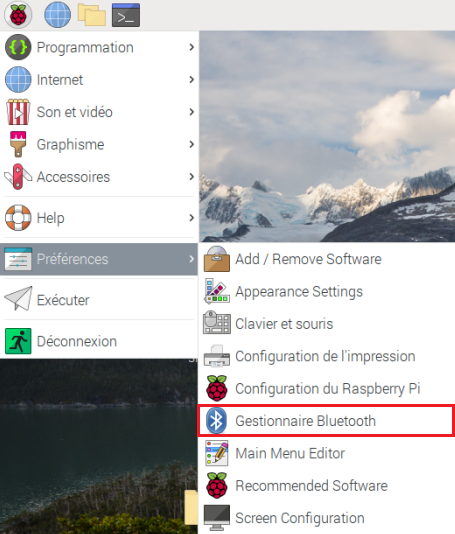
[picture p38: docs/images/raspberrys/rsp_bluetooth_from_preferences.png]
Bluetooth interface depuis les préférences
.

Une fois cette interface ouverte, il faut cliquer sur le bouton _Rechercher_, ce qui effectuera un scan des alentours. Une fois le `Technic Hub` trouvé dans la liste, il est nécessaire de noter son adresse mac : `90:84:2B:50:36:43` afin de pouvoir l'utiliser par la suite.

#### Utilisation

Pour gérer le déplacement de la voiture, à l'aide du kit de développement fourni par pylgbst, voici le code que j'ai écrit :

```python
from pylgbst.hub import MoveHub
from pylgbst.peripherals import Motor, EncodedMotor
from pylgbst import *
from time import sleep

MY_MOVEHUB_ADD = "90:84:2B:50:36:43"
MY_BTCTRLR_HCI = "hci0"

def forward(motor_1, motor_2, motor_3):
    motor_1.start_power(-1)
    motor_2.start_power(-1)
    motor_3.angled(0)
    print("done!")

def downward(motor_1, motor_2, motor_3):
    motor_1.start_power(1)
    motor_2.start_power(1)
    motor_3.angled(0)
    print("done!")

def go_left(motor_3):
    motor_3.angled(-180)
    print("done!")

def go_right(motor_3):
    motor_3.angled(180)
    print("done!")

def stop_moving(motor_1, motor_2):
    motor_1.start_power(0)
    motor_2.start_power(0)
    print("done!")

def reset_angle(motor_3):
    motor_3.angled(degrees=-150)
    print("test 1")
    sleep(1)
    motor_3.angled(degrees=-75)
    print("test 2")
    sleep(1)

def play_scenario(movehub):
    motor_a = Motor(movehub, movehub.PORT_A)
    motor_b = Motor(movehub, movehub.PORT_B)
    motor_c = EncodedMotor(movehub, movehub.PORT_C)

    print("Reset angle:")
    reset_angle(motor_c)
    sleep(2)

    print("Forward:")
    forward(motor_a, motor_b, motor_c)
    sleep(1)

    print("Downward:")
    downward(motor_a, motor_b, motor_c)
    sleep(1)

    print("Stop")
    stop_moving(motor_a, motor_b)

    print("Left:")
    go_left(motor_c)
    sleep(2)

    print("Right:")
    go_right(motor_c)
    sleep(2)

def exiting(connection):
    print("bye")
    connection.disconnect()

conn = get_connection_gatt(hub_mac=MY_MOVEHUB_ADD)

try:
    movehub = MoveHub(conn)
    play_scenario(movehub)
    exiting(conn)
finally:
    exiting(conn)
```

Le code fournit, propose différentes méthodes de connexion tel que :

- bluepy
- bluegiga
- gatt
- bleak
- gattool
- gattlib

Ayant vu dans plusieurs documentations le nom de `GATT` ressortir, je m'y suis penché pour comprendre de quoi il s'agissait. `GATT` est un acronyme de l'anglais _Generic Attribute Profile_, il définit comment les 2 appareils vont échanger leurs données, tout en suivant un système de _Services_ et de _Characteristics_. C'est pourquoi j'ai utilisé la connexion avec `GATT`.

#### Problème rencontré

Au départ, je tentais d'appareiller le Raspberry Pi au Technic Hub depuis les commandes disponibles dans le mode `bluetoothctl`, mais j'avais cette erreur `Failed to pair: org.bluez.Error.AuthenticationFailed`.

##### Comment je l'ai résolu

J'ai alors compris que pour me connecter au Technic hub, j'aurai besoin d'y avoir accès par un moyen qui permette de transmettre des données, car depuis la documentation LEGO, j'ai aperçu des commandes écrites avec des bytes en hexadécimal. De plus,j'ai remarqué qu'ils mettaient à disposition les UUID des hubs, car ils ont tous le même fabricant.

Il y a plein de pistes que j'ai entrevues sur les différents repository, cependant je ne m'y étais pas intéressé plus que ça, car aucun ne mentionnait le nom de Technic Hub. Après avoir été dans les différents repository ci-dessous et après avoir regardé comment étaient écrites leurs transmissions au hub bluetooth. J'ai réussi à comprendre comment je pouvais m'appareiller au Technic Hub et comment interagir avec.

### Radar 360 (RPLiDAR A2M8)

Le RPLiDAR A2M8 est un scanner laser à 360°. Il permet de connaître la distance entre lui et les obstacles à chaque angle.

#### Mise en place

Le lidar est branchable par port série. Cependant, un adaptateur est fourni avec et nous permet de récupérer les données par USB.

Types de connexions

Au dos de l'adaptateur, on peut y voir les éléments suivants :

Informations inscrites au dos de l'adaptateur

| Couleur du câble | Nom du signal | Type de signal | Description | Tension minimale | Tension habituelle | Tension maximale |
| :---: | :---: | :---: | :---: | :---: | :---: | :---: |
| Rouge | VCC | Power | Puissance totale | 4.9V | 5V | 5.2V |
| Vert | TX | Output | Sortie des données sur le port série relative au scanner | 0V | 3.3V | 3.5V |
| Jaune | RX | Input | Entrée des données sur le port série relative au scanner | 0V | 3.3V | 3.5V |
| Noir | GND | Power | La Terre | 0V | 0V | 0V |
| Bleu | MOTOCTL | Input | Moteur de scan, régulé avec un PWM | 0V | 3.3V | 5V |

Informations complémentaires pour le PWM, voici les valeurs utilisées :

| |  Unité | Valeur minimale | Valeur habituelle | Valeur maximale |
| :---: | :---: | :---: | :---: | :---: |
| Haut niveau de tension |  Volts | 3.0 | 3.3 | 5 |
| Fréquence du PWM | Herz | 24,500 | 25,000 | 25,500 |
| Plage de cycles d'utilisation | Pourcent | 0 | 60 | 100 |

Si on le souhaite, on peut modifier la vitesse de transmission. De base, la vitesse de transmission est paramétrée sur 115'200 Baud, mais on peut la montée à 256'000 Baud.

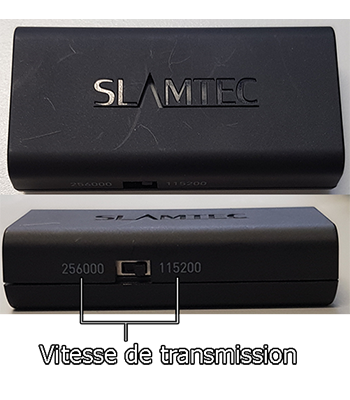
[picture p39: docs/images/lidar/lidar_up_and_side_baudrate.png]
Vitesse de transmission du Lidar


Il faut commencer par télécharger le kit de développement disponible sur [le repository officiel de Slamtec](https://github.com/Slamtec/rplidar_sdk/releases/tag/release%2Fv1.12.0). Une fois le SDK téléchargé sur le Raspberry. Nous pouvons brancher le Lidar à l'adaptateur. Depuis l'adaptateur, branché le micro-USB dessus puis l'USB au Raspberry Pi.

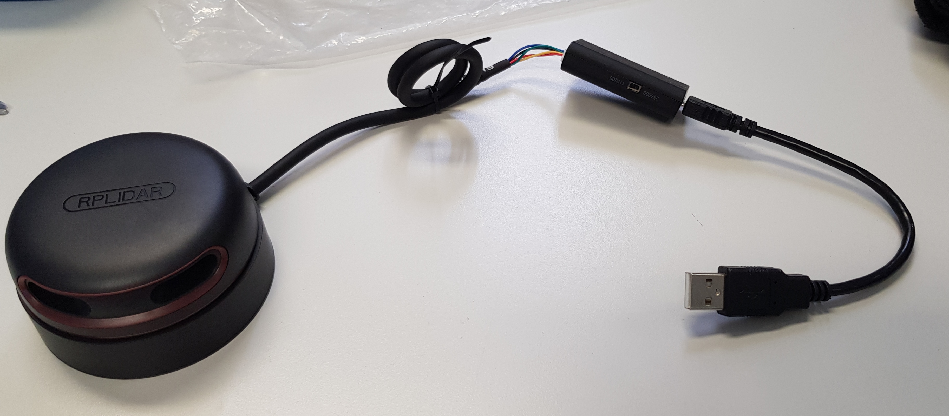
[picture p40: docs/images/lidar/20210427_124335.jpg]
Branchement du Lidar à l'adaptateur


#### Utilisation

Afin de vérifier qu'il soit bien détecté, il faut exécuter la commande suivante `ls /dev/*USB*` ceci devrait être retourné `/dev/ttyUSB0`. Dans le dossier du code source, il faut aller dans le répertoire `sdk/app/` et exécuter la commande make dans un terminal. Pour exécuter l'un des 3 programmes suivant :

1. ultra_simple
2. simple_grabber
3. frame_grabber

Nous pouvons maintenant exécuter le programme souhaité en utilisant la commande suivante dans un terminal : `nom_du_programme /dev/ttyUSB0`.

#### Problème rencontré

Les codes fournis fonctionnent parfaitement, sauf qu'aucun ne permet de récupérer depuis une variable ou autre les valeurs d'angles. Cependant, elles sont affichées dans la console.

##### Comment je l'ai résolu

Il y avait 2 possibilités :

1. La première était de récupérer les câbles séries (rouge, bleu, jaune, ...) et de les connecter directement au GPIO sur les pins qui fournissent :
   - TX
   - RX
   - VCC
   - Ground
   - MotorCTL est un PWM

Comme indiqué sur ce schéma du GPIO du raspberry pi de manière plus détaillé que le premier vu dans la section parlant des Raspberry Pi :

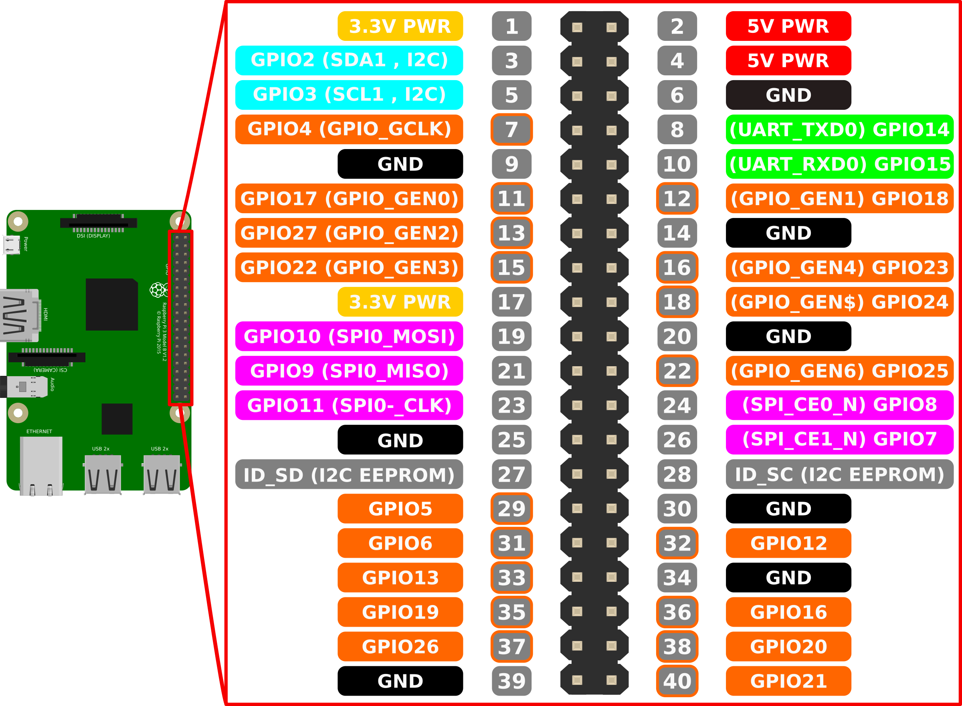
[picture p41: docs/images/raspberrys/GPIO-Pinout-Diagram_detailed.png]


Il s'agirait donc des pins : 2 (VCC), 6 (GND), 8 (TX), 9 (RX)

2. La seconde option était de récupérer les données que l'API de Slamtec, [ici présente](https://github.com/Slamtec/rplidar_sdk/releases) écrite en `C++`. Cette dernière fournissait les données en les affichant dans la console sous un format : `Theta: 210.31 Dist: 00875.00`, Theta représentant un angle et Dist représentant la distance en millimètre d'un obstacle.
   Malheureusement trop tard, j'ai trouvé [cette librairie](https://rplidar.readthedocs.io/en/latest/) en python qui faisait quasiment tout le travail à ma place.

Cela dit, la méthode que j'utilise actuellement se résume à ça :

Méthode utilisée pour récupérer en temps réel les données du Lidar

Le problème de cette méthode est qu'elle n'est vraiment pas optimisée, car on va lire de manière asynchrone les données reçues par le programme `C++` et traitée puis mise dans le tableau de distance à chaque itération. Cette même itération est stoppable à tout moment avec un paramètre à changer dans le lancement du processus.

### Émetteur WiFi (ASUS RT-AC58U)

Un émetteur sans fil diffuse des ondes en utilisant la fréquence radio (RF). Il permet de rendre une connexion internet sans y être connecté de manière filaire. Pour ce projet, nous utilisons un ASUS RT-AC58U.

#### Mise en place

##### Branchement

Pour mettre en place le routeur, il faut d'abord brancher l'alimentation dans le port indiqué ainsi que le câble ethernet permettant la connexion à internet dans le port bleu. Pour récupérer les sorties ethernet, il faut les brancher dans les ports jaunes.

Branchements à faire pour le routeur

Sur le haut du routeur, on peut voir différentes leds s'allumer, voici la signification de ces dernières : 

Branchements à faire pour le routeur

Une fois que le branchement est fait, il faut se rendre sur http://router.asus.com/, la page de connexion vous sera alors affichée. Par défaut, les identifiants pour s'y connecter sont pour le nom d'utilisateur ainsi que pour le mot de passe `admin`.

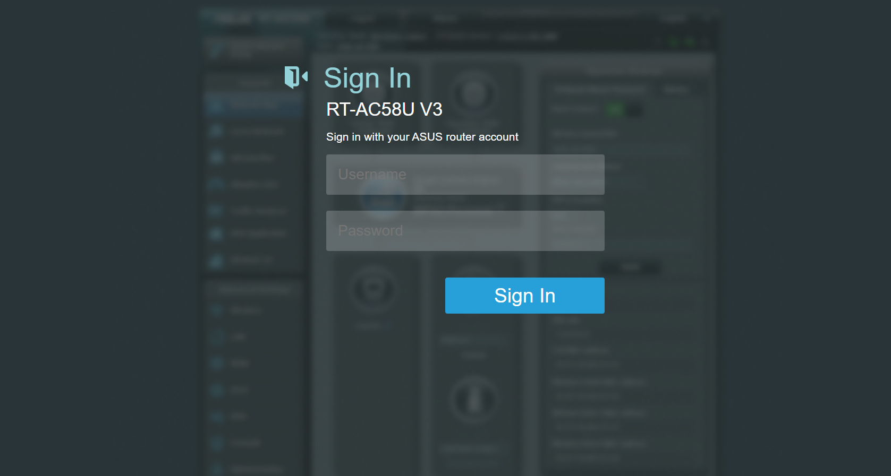
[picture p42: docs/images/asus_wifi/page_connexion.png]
Page de connexion


##### Configuration

Pour commencer à paramétrer le réseau, il faut en un premier temps cliquer sur le bouton `Quick Internet Setup`

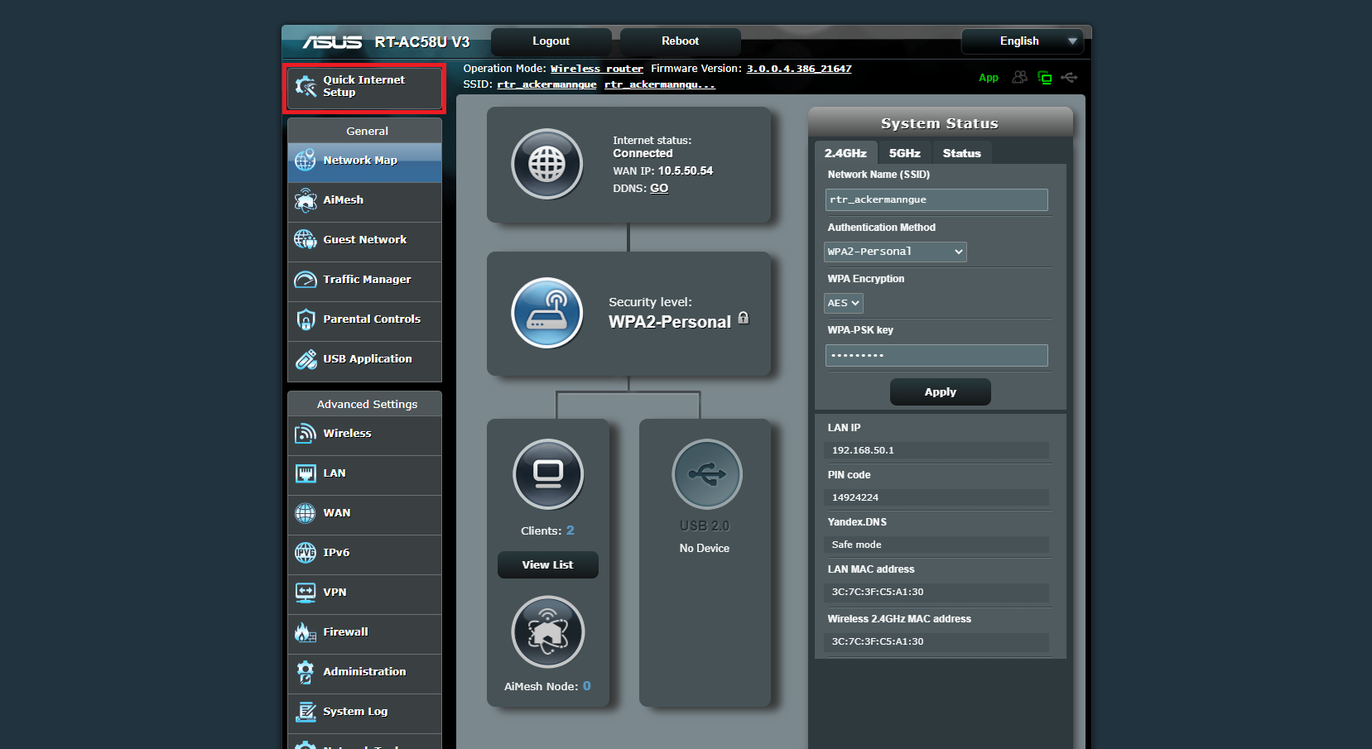
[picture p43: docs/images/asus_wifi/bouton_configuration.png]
Bouton de configuration du réseau


Cette première page sera affichée, vous laissant le choix entre une configuration rapide ou détaillée. Le mode avancé n'étant pas nécessaire, il est préférable de cliquer sur le bouton `Create A New Network`

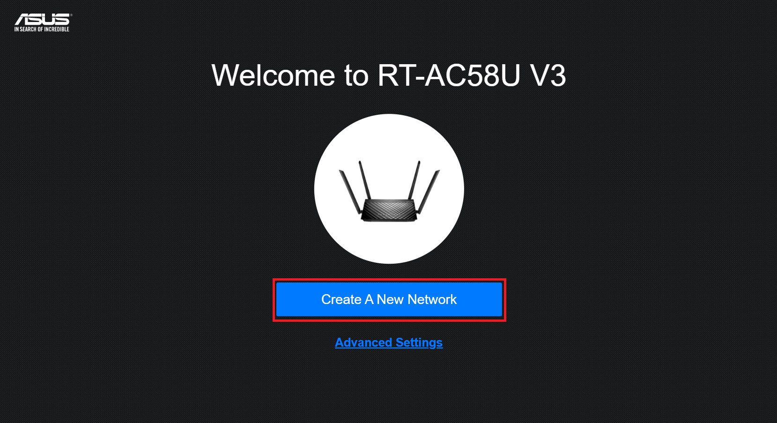
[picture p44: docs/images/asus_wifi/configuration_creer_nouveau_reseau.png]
Création d'un nouveau réseau


Ensuite, cette page de configuration s'affichera, et vous pourrez renter les différentes informations telles que le SSID (nom du réseau) et son mot de passe. Une fois les différents champs remplis, il faut cliquer sur `Apply`.

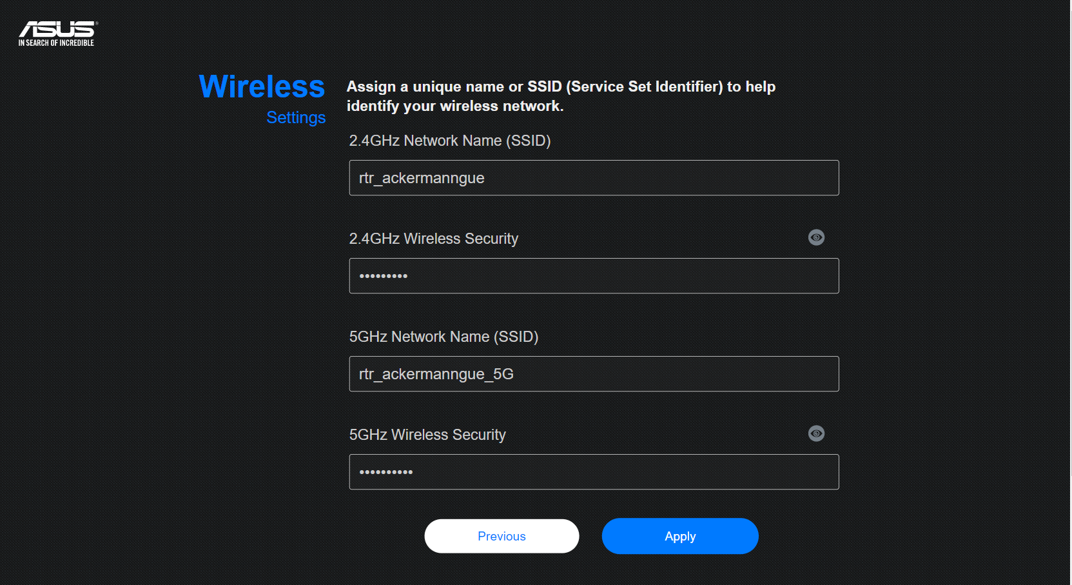
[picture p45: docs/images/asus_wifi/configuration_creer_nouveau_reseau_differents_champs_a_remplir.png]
Champs à remplir


Le routeur va nous demander si l'on veut que `Yandex` soit active, son rôle est de restreindre l'accès aux sites malicieux et aux contenus pour adulte. Dans mon cas, je l'ai activé :  

Activation de Yandex

Il est fort probable que vous deviez mettre à jour votre appareil avec le firmware :

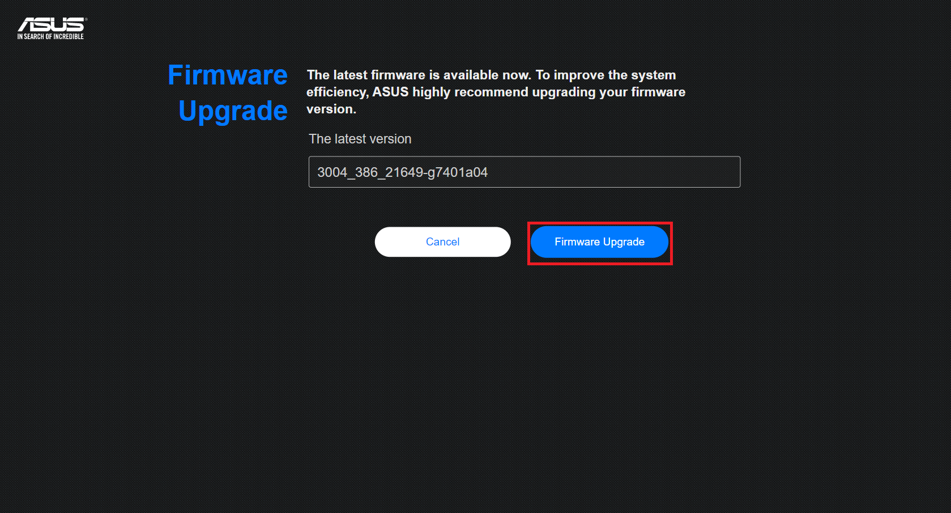
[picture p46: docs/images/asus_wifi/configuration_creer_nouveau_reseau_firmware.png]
Mise à jour du firmware


##### Changement des paramètres de connexion à l'interface web

Pour modifier le nom d'utilisateur ainsi que son mot de passe, il faut cliquer sur le bouton `Administration` : 

Bouton d'administration du réseau

Cette page s'affichera, et il faudra cliquer sur l'onglet `System` afin d'avoir accès à l'interface nous permettant de modifier ces informations : 

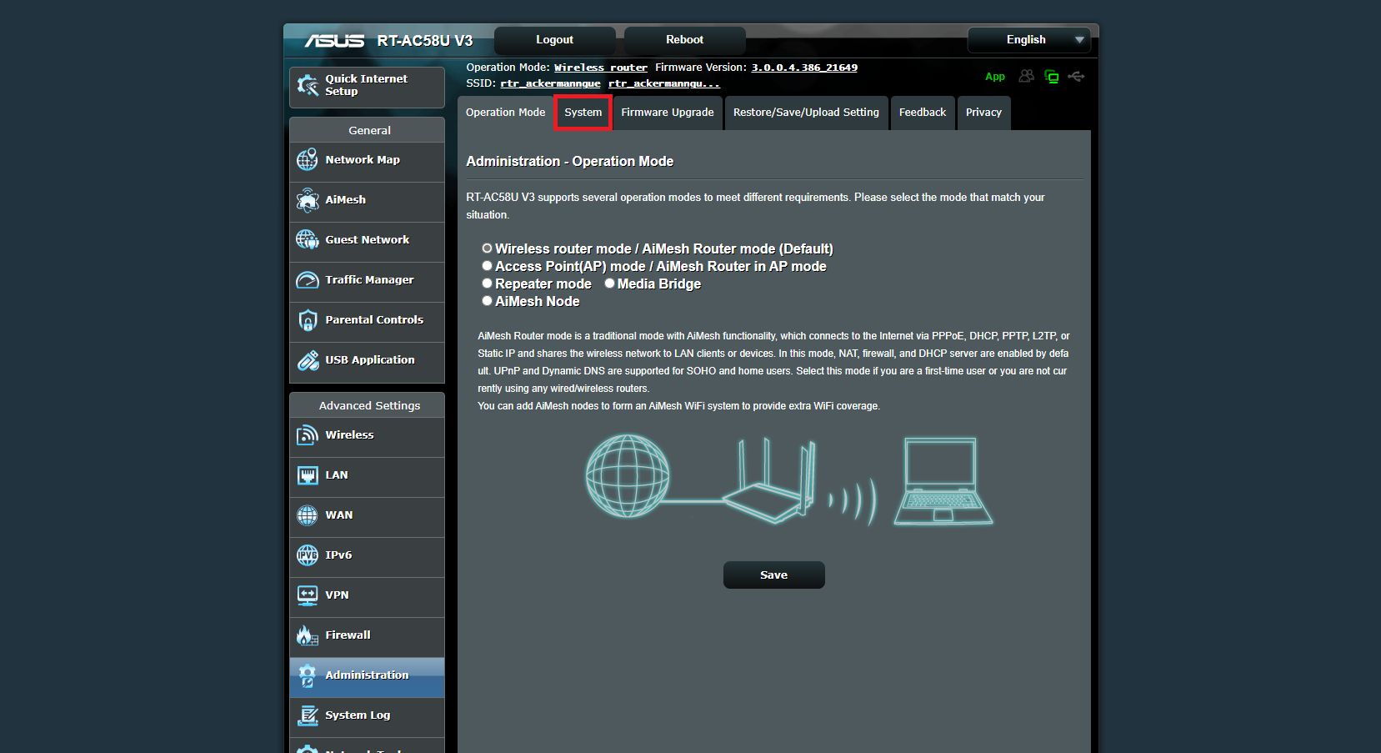
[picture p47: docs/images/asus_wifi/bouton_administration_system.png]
Onglet system


Une fois dans l'onglet, vous pourrez modifier les informations ici : 

Changement du nom d'utilisateur ainsi que de son mot de passe pour se connecter à l'interface web

#### Utilisation

Il faut activer le WiFi sur l'appareil que l'on souhaite connecter, une fois les réseaux scannés. Nous devrions pouvoir avoir accès au réseau `le_SSID_du_réseau` et s'y connecter en entrant le mot de passe choisi sur l'interface nous permettant de paramétrer notre réseau.

## Python Flask

Flask est un framework web disponible en python qui permet de développer aisément des applications web.

### Mise en place

Flask est téléchargeable depuis la commande `pip3 install Flask`.

### Utilisation

Dans un premier temps, il est important de créer un fichier python. Dans cet exemple, ce sera `hello.py`.

#### Application de base

Il faut d'abord importer Flask. Et l'initialiser de la manière suivante :

```python
from flask import Flask
app = Flask(__name__)

@app.route('/')
def hello_world():
    return 'Hello, World!'
```

Pour lancer l'application, il faut d'abord exporter la variable d'environnement `FLASK_APP` de la manière suivante dans un terminal : `export FLASK_APP=hello.py`. Une fois cela fait, lancer le serveur avec la commande : `flask run --host=0.0.0.0`. Le `--host=0.0.0.0` rend l'accès au serveur public depuis d'autres appareils connectés sur le réseau. Dans mon cas, mon Raspberry Pi a cette adresse IP : `10.5.50.42` et mon PC `10.5.50.52`. Pour aller sur le site, je tape l'adresse IP du Raspberry Pi ainsi que le port 5000, http://10.5.50.42:5000/.

```
 * Serving Flask app "hello.py"
 * Environment: production
   WARNING: Do not use the development server in a production environment.
   Use a production WSGI server instead.
 * Debug mode: off
 * Running on http://0.0.0.0:5000/ (Press CTRL+C to quit)
127.0.0.1 - - [28/Apr/2021 08:42:15] "GET / HTTP/1.1" 200 -
127.0.0.1 - - [28/Apr/2021 08:42:16] "GET /favicon.ico HTTP/1.1" 404 -
10.5.50.52 - - [28/Apr/2021 08:42:32] "GET / HTTP/1.1" 200 -
10.5.50.52 - - [28/Apr/2021 08:42:32] "GET /favicon.ico HTTP/1.1" 404 -
```

Le port 5000 étant le port par défaut définit par Flask, mais qui est changeable avec le paramètre `flask run --host=0.0.0.0 -p 8000`, dans ce cas, le port de Flask sera changé à 8000.

##### Routes

Flask fonctionne avec un système de routes. Les routes sont écrites de la manière suivante :

```python
@app.route('/nom_de_la_route')
def nom_de_la_fonction():
    # Code ...
    return html_a_afficher
```

Lors de l'accès à une route, le code à l'intérieur de la fonction sera exécuté puis rendra de l'HTML à afficher.

On peut aussi récupérer une valeur depuis la route de la manière suivante :

```python
@app.route('/hello/<name>')
def hello(param_name):
    return render_template('hello.html', name=param_name)
```

##### Templates

Si les routes rendent de l'HTML, c'est que l'on peut injecter des valeurs dans du code HTML pré-écrit. Pour ce faire, à la racine du projet, il faut créer un dossier précisément nommé de la sorte : `templates`. Ce répertoire contiendra les différents templates HTML à afficher. Voici comment un fichier de template HTML est écrit :

```HTML
<!doctype html>
<title>Hello from Flask</title>
{% if name %}
  <h1>Hello {{ name }}!</h1>
{% else %}
  <h1>Hello, World!</h1>
{% endif %}
```

Les balises {% ... %} permettent d'écrire du code comme des tests et des boucles.

Les balises {{ nom_de_la_variable }} permettent d'injecter des valeurs dans l'HTML dynamiquement.

Depuis le code python, pour pouvoir utiliser des templates, il faut importer `render_template` comme suit : `from flask import render_template`

##### Barre de navigation

En prérequis, il faut installer les librairies :

1. flask_bootstrap
2. flask_nav

Voici la commande à utiliser : `sudo pip3 install flask_bootstrap && sudo pip3 install flask_nav`

Ensuite, dans le code une fois les libraires importées comme suit :

```python
from flask_bootstrap import Bootstrap
from flask_nav import Nav
from flask_nav.elements import *
```

Nous pouvons initialiser notre barre de navigation avec un nom ainsi que leurs routes :

```python
topbar = Navbar(
    View('Accueil', 'home'),
    View('Télécommande', 'control_car'),
    View('Déconnexion', 'close_connection'),
    View('Créer une connexion', 'create_car'),
)

nav = Nav()
nav.register_element('top', topbar)

app = Flask(__name__)
Bootstrap(app)
```

Pour y avoir accès, on peut l'inclure dans une page HTML de la manière suivante :

```python
{% block navbar %}
    {{nav.top.render(id='top-navbar')}}
{% endblock %}
```

##### Formulaires

Les formulaires avec Flask sont écrits en HTML classique :

```html
<form action="/route_apres_validation" method="POST ou GET">
  <input type="text" name="input_txt" placeholder="..." />
  <input type="checkbox" name="input_cbx" checked="true" />
  <input type="submit" value="valider" name="input_validation" />
</form>
```

Pour récupérer les informations des différents champs du formulaire, voici le code qui permet de les récupérer :

```python
@app.route('/route_apres_validation', methods=['GET', 'POST'])
def nom_de_fonction():
    if request.method == 'POST' and request.form["input_validation"]:
        valeur = request.form["nom_input_html"]
        # Traitement ...
    return html_a_afficher
```

Dans le paramètre `methods` de la route, le paramètre GET est celui de base, mais peut être changé par POST.

##### Javascript / AJAX

Étant donné que Flask nous permet d'écrire des pages HTML qui seront insérées dans la page lors de l'appel (voir la section regroupant les Templates), cela veut dire que nous pouvons écrire du javascript à l'aide des balises `<script type=text/javascript></script>`. Pour le cas d'AJAX, il suffit de télécharger la librairie JQuery afin d'y avoir accès ou en utilisant le CDN `<script src="https://code.jquery.com/jquery-3.6.0.min.js" integrity="sha256-/xUj+3OJU5yExlq6GSYGSHk7tPXikynS7ogEvDej/m4=" crossorigin="anonymous"></script>`.

À noter que l'unique différence entre ces deux manières d'avoir accès à JQuery, est que l'un est accessible en ligne et l'autre sur la machine donc la rapidité d'exécution, car en utilisant la version en ligne, en fonction du débit de la connexion, il peut y avoir de la latence.

Pour mettre en place de l'AJAX, il faut dans des balises script sur l'une des pages HTML présentent dans le répertoire `templates`. La méthode `serialize()`, permet de récupérer de sérialiser les données présentes dans le formulaire HTML.

```javascript
<script>
function execute(){
    $.ajax({
            url: '/bg_processing_car/',
            data: $('form').serialize(),
            type: 'POST',
            success: function(response) {
                console.log("action performed");
            },
            error: function(error) {
                console.log(error);
            }
        });
    }
</script>
```

Et dans le code python, voici comment on récupère et traite les données : 

On peut considérer les données envoyées par l'appel AJAX comme ceci :

```javascript

[
  {
    rngMove : 75,
    rngRotationAngle : 1
  }
]

```

Et on les récupère exactement comme pour un formulaire classique : 

```python

@app.route("/bg_processing_car/", methods=["POST"])
def bg_process_car():
    """Process the values passed by Javascript"""
    automatic_mode = MODE_OFF
    move_speed = request.form["rngMove"]
    angle_rotation = request.form["rngRotationAngle"]
    car = CarController()
    # Reverse the result because it returns True if there isn't a ground below
    grounded = not GPIO.input(GPIO_FLYING_FISH_FRONT_RIGHT)
    car.move(float(move_speed), int(angle_rotation), grounded)
    return render_template(
        "form_remote_car.html",
        mode=automatic_mode,
        speed=move_speed,
        angle=angle_rotation,
    )
```

## Bluetooth

### Qu'est-ce que le bluetooth ?

Le bluetooth est une norme de communication à courte distance utilisant des ondes radio sur la bande de fréquence 2,4GHz. Ce qui permet d'échanger des données dans les deux sens en _peer-to-peer_ dans un picoréseau.

Logo du Bluetooth

Un picoréseau (en anglais piconet) est un mini-réseau qui se crée de manière instantanée et automatique quand plusieurs périphériques Bluetooth sont dans un même rayon.

#### Comment est-il structuré ?

Quand on parle de bluetooth, au niveau des protocoles, on peut parler de relations _Maîtres_ et d'_Esclaves_. Le _Maître_ Bluetooth est celui qui peut initier une connexion avec un périphérique (ou _Esclave_), cependant une fois les appareils connectés, le _Maître_ et l'_Esclave_ peuvent échanger des informations sans restriction (en fonction de la limitation de l'application).

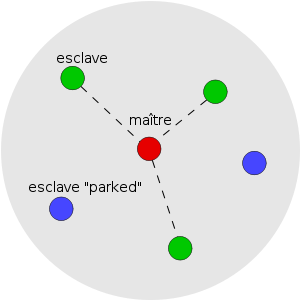
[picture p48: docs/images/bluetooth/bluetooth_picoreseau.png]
Schéma d'un picoréseau (Piconet en anglais)


Les relations _Maître_-_Esclave_ sont gérées par le gestionnaire de liaison. Il implémente le protocole L2CAP (de l'anglais _Logical Link Control and Adaptation Protocol_) et le gère (création, destruction de canaux). Il implémente aussi les mécanismes de sécurité comme :

- l'authentification
- l'appairage (l'association)
- la création et la modification des clés
- et le chiffrement

#### Sécurité

Il existe 3 modes de sécurité :

- Mode 1
  - Non sécurisé pour toutes opérations
  - Peut uniquement communiquer avec des appareils du même mode
- Mode 2
  - Fournit un niveau de sécurité à la couche application après l'établissement d'une liaison avec un autre dispositif
- Mode 3
  - Fournit un niveau de sécurité avant l'établissement du canal de communication
  - Chiffrement sécurisé au niveau de la liaison avec autre dispositif

À noter, si un service effectue une demande de connexion, le mode de sécurité les plus haut sera celui utilisé afin de traiter la demande tout en s'assurant de la sécurité relative aux différents modes.

Le bluetooth est divisé en deux parties :

1. La couche contrôleur implémentant la partie matérielle
2. La couche hôte implémentant la partie logicielle.

L'émission et la réception de signaux radio sont possibles grâce à un module RF (RadioFrequency).

L'interface host-controller (HCI) fait la liaison entre la couche hôte et la couche contrôleur en assurant le transfert des événements et des paquets de données. Cette interface assure le transfert d’information pour que la couche hôte puisse découvrir, ajouter et gérer les appareils dans un picoréseau.

Chaque paquet possède un champ header permettant de distinguer le picoréseau de l’appareil des autres picoréseaux. Voici le format d'un paquet :

| Champ | Header | Access Address | Protocol Data Unit (PDU) | Cyclic redundancy Check (CRC) |
| --- | :----: | :---: | :---: | :---: |
| Taille en bits | 8 | 32 | de 2 à 39 | 24 |

Le PDU est une unité de mesure des informations échangées dans un réseau informatique. Appliqué aux couches du modèle OSI, le PDU de :

- La couche physique est le bit.
- La couche liaison est la trame.
- La couche réseau est le paquet.
- La couche transport est le segment pour TCP, et le datagramme pour UDP.
- Les couches application, présentation et session sont les données.

Le Cyclic Redundancy Check, autrement appelé contrôle de redondance cyclique, permet de détecter des erreurs de transmission ou de transfert par ajout, combinaison et comparaison de données redondantes, obtenues grâce à une procédure de hachage. Cette méthode est comparable au checksum, mais ce dernier est plus élaboré.

Les paquets reçus par le HCI sont traités par le protocole L2CAP. Il assure le transport des paquets vers les couches supérieures du modèle OSI, la segmentation et le réassemblage des paquets.

La couche de liaison est définie dans les systèmes bluetooth comme la couche assurant le transport des paquets entre les appareils d’un même picoréseau à travers plusieurs canaux :

Architecture du Bluetooth

- Basic channel : Canal pour la communication entre deux appareils
- Adapted piconet channel : Canal pour la communication dans le picoréseau
- Inquiry scan : Canal pour l'acquisition des appareils bluetooth aux alentours
- Page scan : Canal pour la connexion avec un nouvel appareil

#### Qu'est-ce que Generic Access Profile

Generic Access Profile (GAP), est responsable de la connexion. De plus, il gère aussi :

- les modes d'accès
- les procédures du dispositif
- la découverte du dispositif
- l'établissement et la fin de la liaison
- le lancement des fonctions de sécurité
- la configuration du dispositif.

Diagramme d'états du profile GAP

- Veille : le dispositif est dans l'état initial de veille lors de la réinitialisation.
- Annonce : Le dispositif envoie un message d'annonce avec des données spécifiques pour faire savoir aux dispositifs initiateurs qu'il est un dispositif connectable (cette annonce contient l'adresse du dispositif et peut contenir des données supplémentaires telles que le nom du dispositif).
- Scan : Lorsqu'il reçoit l'annonce, le dispositif de scan envoie une demande de scan à l'annonceur qui répondra par une réponse d'analyse. Cette méthode est appelée découverte du dispositif. Le dispositif d'analyse connaît le dispositif ayant émis l'annonce et peut établir une connexion avec lui.
- Initiation : Lors de l'initialisation, l'initiateur doit spécifier une adresse de dispositif homologue à laquelle se connecter. S'il reçoit une annonce correspondant à l'adresse du dispositif homologue, le dispositif initiateur envoie une demande de connexion avec les paramètres disponible ci-dessous :
  - Intervalle de connexion (entre 7.5 et 3200 ms)
  - La latence de l'esclave
  - Délai de supervision (entre 10 et 3200 ms)
- Esclave/Maître : Lorsqu'une connexion est établie, le dispositif fonctionne comme un esclave s'il s'agit de l'annonceur sinon comme un maître s'il s'agit de l'initiateur.

##### Qu'est-ce que Generic Attribute Profile

Generic Attribute Profile (GATT), est responsable de la communication de données entre les appareils connectés. Il est structuré en _Services_ et _Characteristics_ comme ci-dessous :

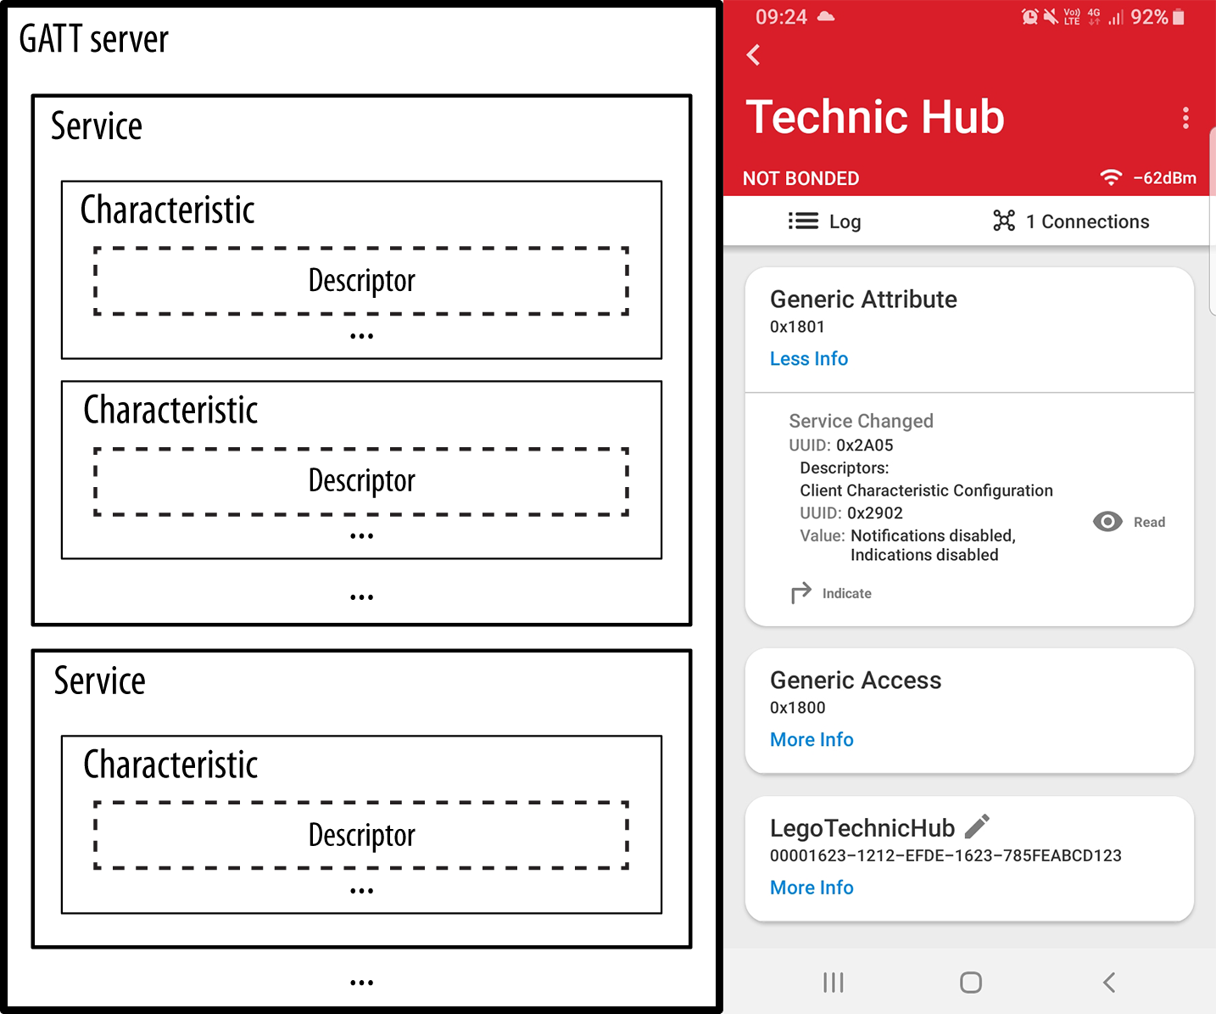
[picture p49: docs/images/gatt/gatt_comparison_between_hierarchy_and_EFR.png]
Architecture GATT


Les attributs sont groupés en _services_, chaque _services_ peut contenir 0 ou + _characteristics_. Ces dernières peuvent avoir de 0 à + _descriptors_.

- GATT Server : Technic Hub
- Service : Generic Attribute
  - Characteristic : Service Change
- Service : Generic Access
  - Characteristic : Device Name
  - Characteristic : Appearance
  - Characteristic : Peripheral Preferred Connection Parameters
- Service : LegoTechnicHub (renommée car de base l'application affichait Unknown ervice)
  - Characteristic : Unknown Charateristic

Pour avoir accès à ces informations, j'ai utilisé l'application EFRConnect disponible sur le playstore.
J'ai lancé un scan depuis le Raspberry Pi, voici les informations qui ont été retournées :

```
[NEW] Device 90:84:2B:50:36:43 Technic Hub
[CHG] Device 90:84:2B:50:36:43 RSSI: -58
[CHG] Device 90:84:2B:50:36:43 TxPower: 0
[CHG] Device 90:84:2B:50:36:43 ManufacturerData Key: 0x0397
[CHG] Device 90:84:2B:50:36:43 ManufacturerData Value:
  00 80 06 00 61 00                                ....a.
```

Par la suite, j'ai lancé un scan depuis l'application afin de comparer les données, voici les informations que l'application m'a retournées concernant le Technic Hub :

- Flags : `0x06: LE General Discoverable Mode, BR/EDR Not Supported`
- Complete list of 128-bit service class UUIDs : `00001624-1212-EFDE-1623-785FEABCD123`
- Manufacturer Data :

  1. Company Code : `0x0397`
  2. Data : `0x008006004100`
  3. Slave connection interval range : `20.0ms`
  4. Tx power level: `0 dBm`
  5. Complete local name : `Technic Hub`

- Generic attribute : `0x1801`
  1. UUID : `0x2A05`
  2. Descriptor : _champs vide_
  3. Client characteristic configuration : `0x2902`
- Generic access :
  1. Device name : `0x1800`
  2. Appearance : `0x2A01`
  3. Peripheral preffered connection parameters : `0x2A04`
- _Unknown Service_ :
  1. UUID : `00001624-1212-EFDE-1623-785FEABCD123`
  2. Descriptor : _champs vide_
  3. Client characteristic configuration : `0x2902`
  4. Value : `05 00 04 03 00 2E 00 00 10 00 00 00 10 00 00 00 00 00 00 00`

### T'chat en bluetooth

#### Mise en place

Il faut que les 2 Raspberry Pi soient en mode "Découvrable" activable ici :

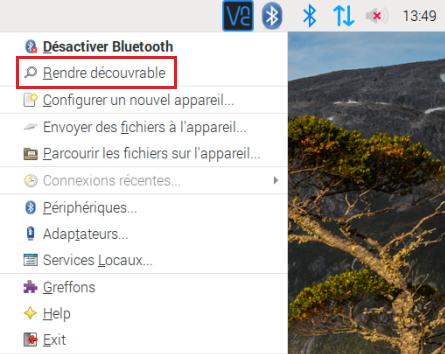
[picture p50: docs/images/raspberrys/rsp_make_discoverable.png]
Rendre découvrable le Raspberry Pi
.

Il faut ensuite effectuer un scan des appareils si nous ne connaissons pas le nom d'hôte de l'autre Raspberry Pi. Le script doit être présent sur les deux Raspberry Pi afin de pouvoir écouter, recevoir ainsi qu'envoyer des messages. La machine hôte, moi dans ce contexte, doit être en mode MODE_SEND tandis que l'autre en mode MODE_RECEIVE.

#### Utilisation

Le code fonctionne de la manière suivante. La machine hôte va en premier temps lancer le scan à la recherche de l'appareil nommé `morenoPi42`.
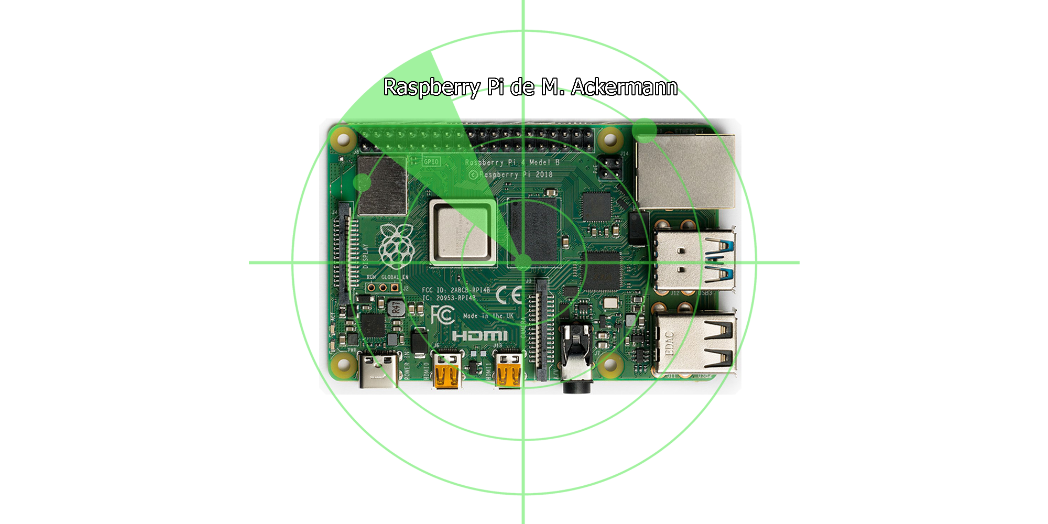
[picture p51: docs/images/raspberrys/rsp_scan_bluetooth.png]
Scan bluetooth des environs


Une fois l'appareil trouvé, je m'y appareille, puis lui envoie le premier message.
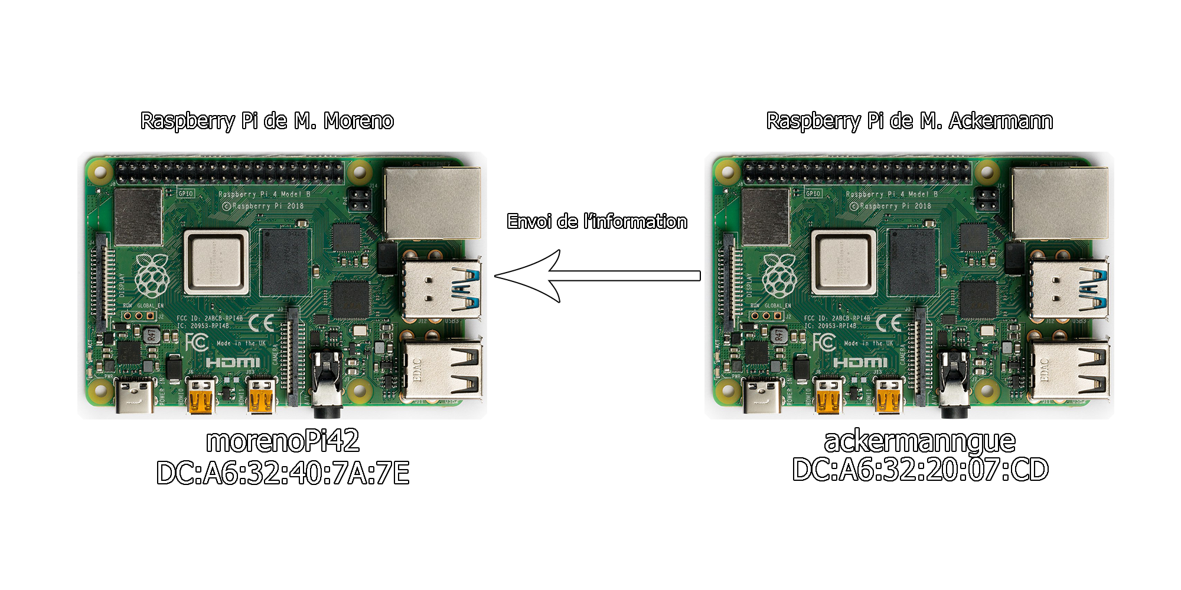
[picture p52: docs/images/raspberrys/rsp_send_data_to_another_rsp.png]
Transfère de données entre les 2 Raspberry Pi 4


Le mode actuel, change et je deviens la machine qui écoute le port spécifié en attendant un message.

T'chat en bluetooth

Diagramme de séquence du T'chat en bluetooth

## Remote GPIO

Le GPIO nous permet d'accéder aux entrées / sorties des appareils connectés au Raspberry Pi.

### Mise en place

Pour pouvoir utiliser le Remote GPIO, il faut tout d'abord l'activer dans l'interface de configuration présente ci-dessous :

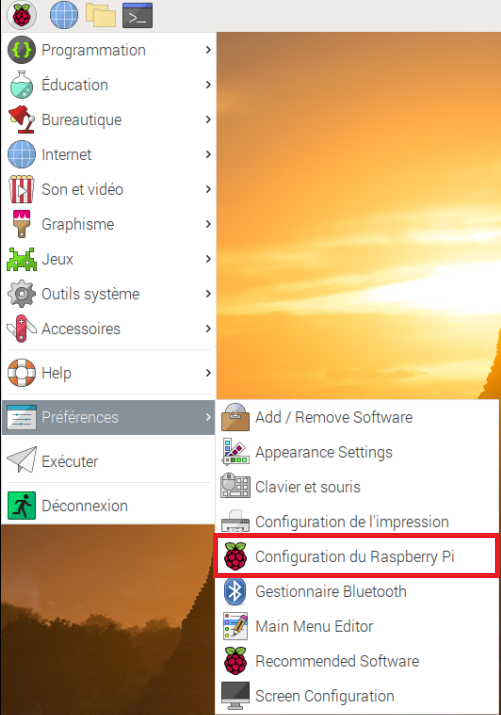
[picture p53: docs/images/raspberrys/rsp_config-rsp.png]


Puis dans la fenêtre présente, tout en bas, cliquer sur _Activé_ :

Diagramme de séquence du T'chat en bluetooth

Une fois que la configuration des différents Raspberry Pi est faite, il ne manque plus qu'à télécharger GPIO Zero, une librairie nous donnant accès à la gestion des différentes pins :
`sudo pip3 install gpiozero`

Ensuite nous aurons besoin de Pi GPIO :
`sudo apt install pigpio`

Une fois installé, il faut lancer le service PiGPIO : `sudo pigpiod` sur la machine qui sera contrôlée à distance.

### Utilisation

Pour pouvoir se connecter au Raspberry Pi, il faut connaître son adresse IP. Une fois connue, voici comment établir une connexion :

```python
import gpiozero
from gpiozero import LED,Button
from gpiozero.pins.pigpio import PiGPIOFactory
from signal import pause

factory = PiGPIOFactory('10.5.50.42')

btn = Button(2) # local RPi.GPIO pin
led = LED(17, pin_factory=factory) # remote pin

btn.wait_for_press()
print("button pressed !")
led.off()
pause()
```

Dans notre cas, avec M. Moreno interprétant le Raspberry Pi _principal_ qui interagirait avec les pins de mon Raspberry Pi.

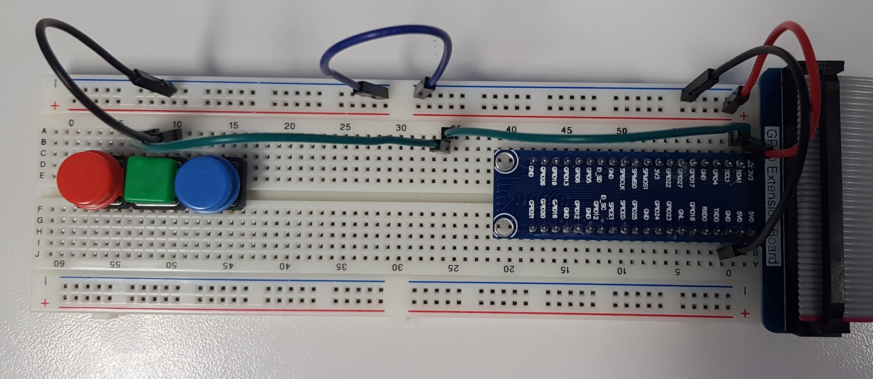
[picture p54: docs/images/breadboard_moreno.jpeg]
breadboard de M. Moreno


- Le bouton est connecté au GPIO 2, donc la pin 3

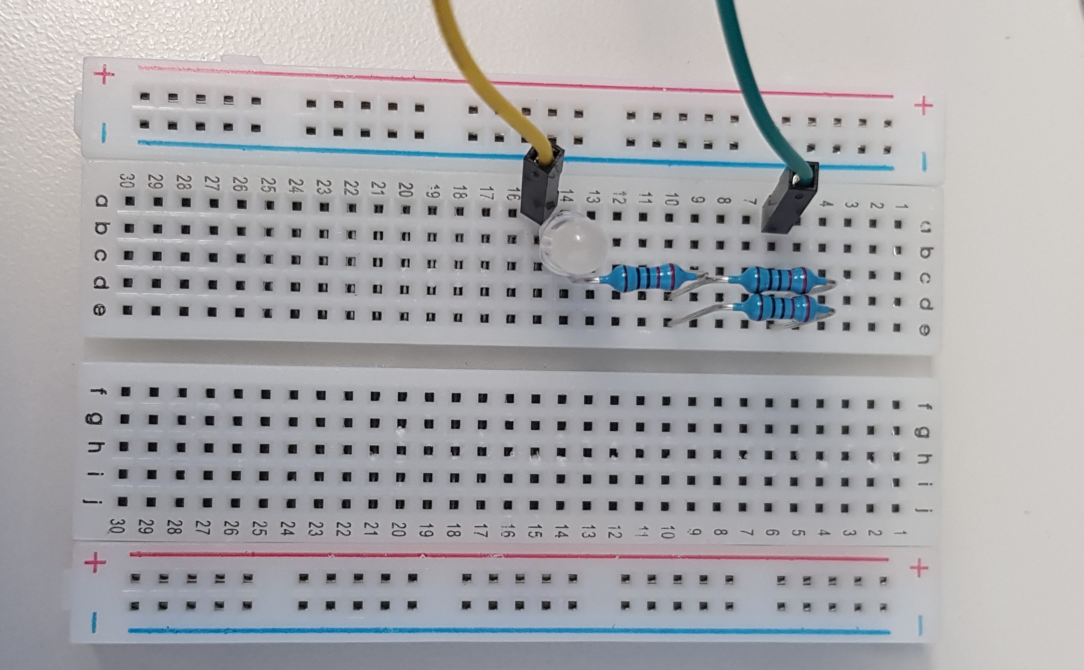
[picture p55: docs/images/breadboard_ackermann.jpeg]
breadboard de M. Ackermann


- La led est connectée au GPIO 17, donc la pin 11

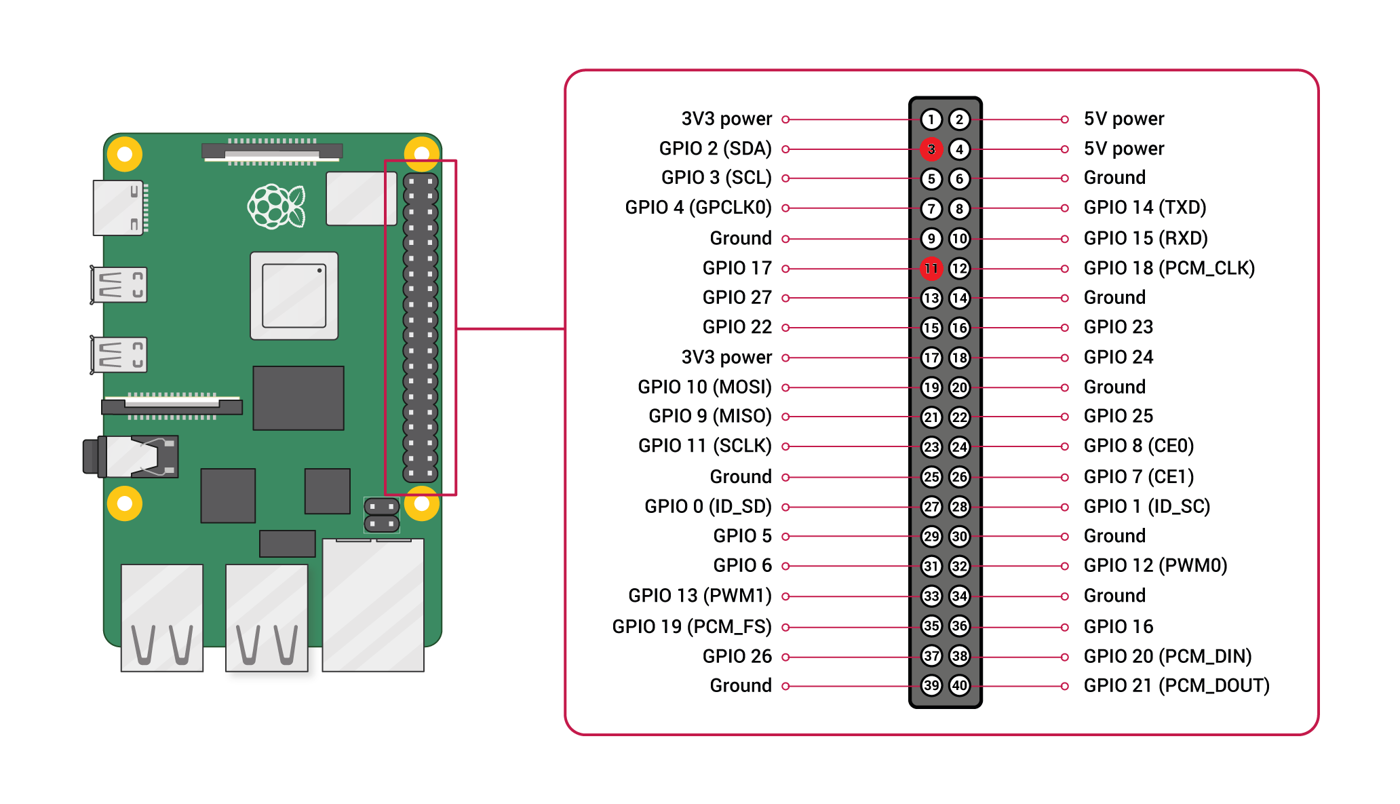
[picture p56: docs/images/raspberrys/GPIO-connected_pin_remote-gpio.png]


## Matplotlib

Matplotlib est une librairie complète permettant la création de statistiques sur un large panel de graphiques utilisable en Python.

### Mise en place

Il faut d'abord installer Matplotlib avec la commande `sudo apt-get install python3-matplotlib` 

### Utilisation

Sur le site officiel, il y a cet exemple que j'ai repris pour en faire l'affichage de mon radar 360° :

```python

import numpy as np
import matplotlib.pyplot as plt

# Fixing random state for reproducibility
np.random.seed(19680801)

# Compute areas and colors
N = 150
r = 2 * np.random.rand(N)
theta = 2 * np.pi * np.random.rand(N)
area = 200 * r**2
colors = theta

plt.subplot(projection='polar')
plt.scatter(theta, r, c=colors, s=area, cmap='hsv', alpha=0.75)

```

Voici ce que l'exemple [ici](https://matplotlib.org/stable/gallery/pie_and_polar_charts/polar_scatter.html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) présent donne : 

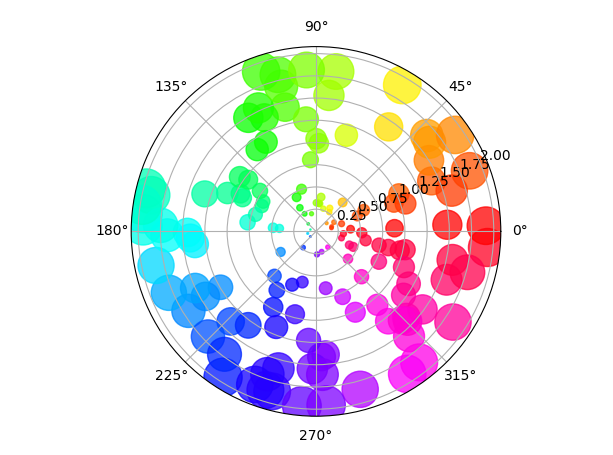
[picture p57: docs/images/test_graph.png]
Affichage du graphique généré par le code d'exemple


Voici le code créant le graphique que j'utilise pour afficher les points : 

```python

def make_chart():
    """
    Will process the chart and save it into a png
    """
    global rows
    area = 5
    colors = [(1, 0.2, 0.3), (1, 0.8, 0), (0.1, 0.5, 0.1)]  # near -> mid -> far
    cmap_name = "distance_warning"
    cmap = matplotlib.colors.LinearSegmentedColormap.from_list(cmap_name, colors)
    data_x = []
    data_y = []
    angle = 0
    # Create the colors I need, values between 0 and 1 for (r, g, b)
    # add angle in radian and his value in two array x and y
    for distance in rows:
        data_x.append(math.radians(angle))
        data_y.append(distance)
        angle += 1

    # set the projection to polar
    plt.subplot(projection="polar")
    plt.scatter(data_x, data_y, s=area, c=data_y, cmap=cmap)
    plt.ylim(0, 2000)
    plt.savefig(constants.CHART_PATH + constants.CHART_NAME)
    plt.clf()

```

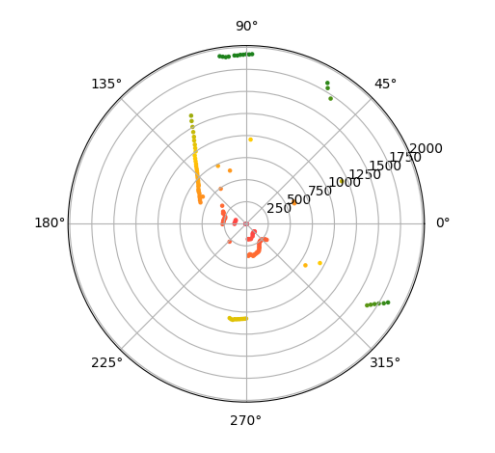
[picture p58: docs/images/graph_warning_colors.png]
Affichage du graphique généré avec les couleurs prévenant le danger par rapport à un obstacle


Voici un exemple du scanner en un quasi-temps réel : 

Affichage des données en temps réel

Ici, on parle de quasi-temps réel, car comme vu dans le section parlant du Lidar, on traite les données émises par l'API en temps réel de manière asynchrone, mais le graphique étant une image enregistrée, le temps d'écriture de l'image ainsi que le temps de lecture fait que les images s'accumulent et que par conséquent l'image gagne du délai.

## RaspAP
RaspAP est une application permettant de mettre en place un point d'accès WiFi avec un raspberry pi facilement.
### Mise en place
Par précaution, il est nécessaire de mettre son raspberry pi à jour avec la commande `sudo apt update && sudo apt full-upgrade`.

Ensuite, il faut télécharger le code du repository Git avec la commande suivante : `wget -q https://git.io/voEUQ -O /tmp/raspap && bash /tmp/raspap`. Durant toute l'installation, il faut tout accepter, à moins d'avoir une bonne raison, mais dans ce cas il n'y a pas de raison valable de dire non.

Après l'installation, il faut redémarrer le raspberry pi. Une fois redémarré, le raspberry pi devrait avoir cette adresse IP : `10.3.141.1`. Pour pouvoir avoir accès à cette information, ouvrez un terminal et exécuter la commande : `ip a` ou `ifconfig`. Normalement vous devriez voir un section nommée `Wlan0`.

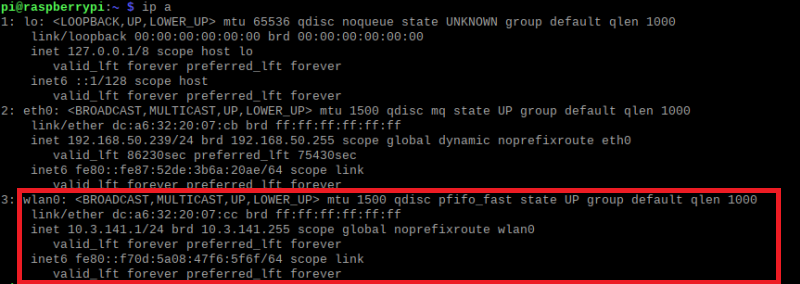
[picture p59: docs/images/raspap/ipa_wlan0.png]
Détails des éléments réseaux avec ip a


### Utilisation
Une fois RaspAP installé, vous pouvez vous rendre sur `10.3.141.1` dans un navigateur web afin d'avoir accès au tableau de bord de RaspAP : 

Pour se connecter, une fenêtre comme celle ci-dessous apparaîtra. Les identifiants par défaut sont `admin` pour le nom d'utilisateur et `secret` comme mot de passe.

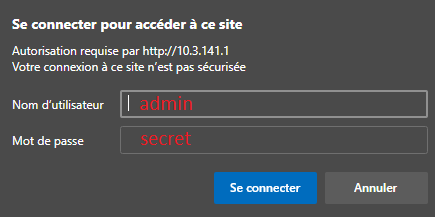
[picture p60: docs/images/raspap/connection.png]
Page de connexion pour RaspAP


Pour pouvoir se connecter au WiFi (toujours avec les valeurs par défaut) le nom du réseau est : `raspi-webgui` avec pour mot de passe `ChangeMe`. Vous pourrez le voir dans les appareils permettant d'accéder à des réseaux WiFi.

Une fois connecté, vous arriverez sur la page de tableau de bord de RaspAP :

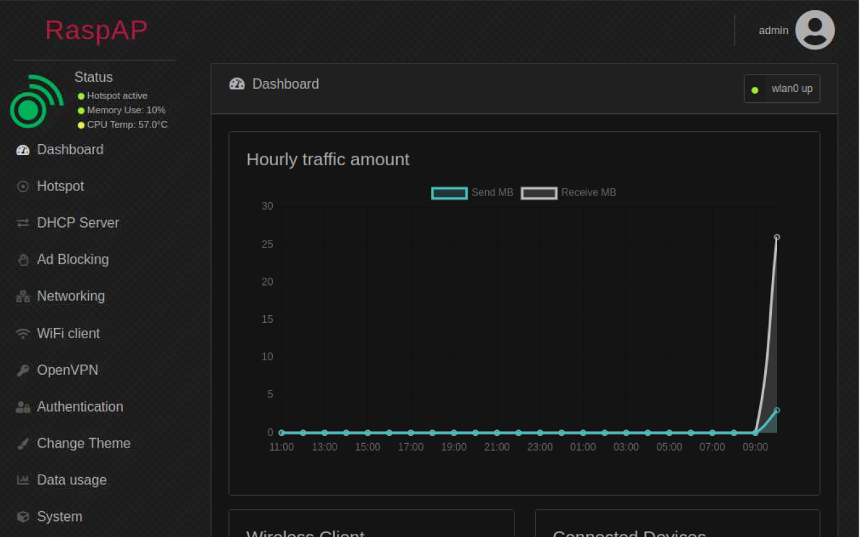
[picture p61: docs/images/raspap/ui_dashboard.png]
Tableau de bord de RaspAP


Depuis l'interface utilisateur, il faut cliquer sur `Hotspot` pour pouvoir changer le nom du réseau `SSID`. 

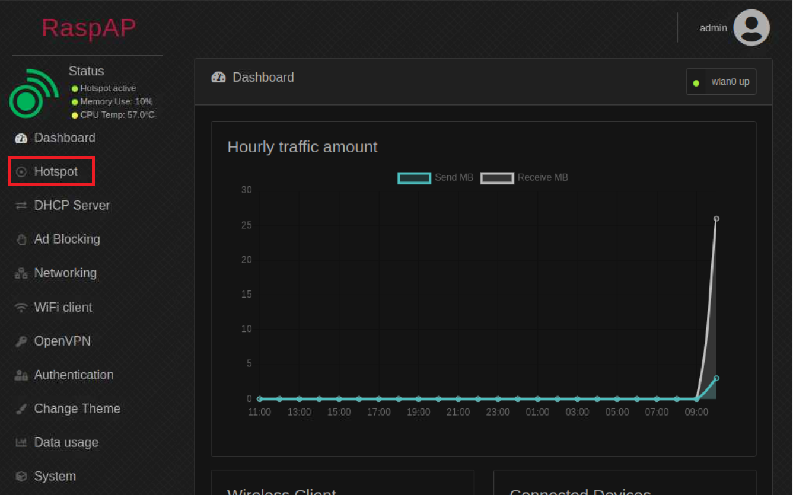
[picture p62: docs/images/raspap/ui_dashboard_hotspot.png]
Section Hotsport de RaspAP


Une fois sur la page de configuration du Hotspot, il faut changer le SSID du réseau par le nom que vous souhaiteriez qu'il adopte. Dans mon cas je l'ai changé à `rps4_access_point` :

Section Hotsport de RaspAP

Pour changer le mot de passe `Pre Shared Key`, il faut aller dans l'onglet `Security`, remplir les informations que vous souhaitez utiliser pour vous connecter au réseau WiFi. :

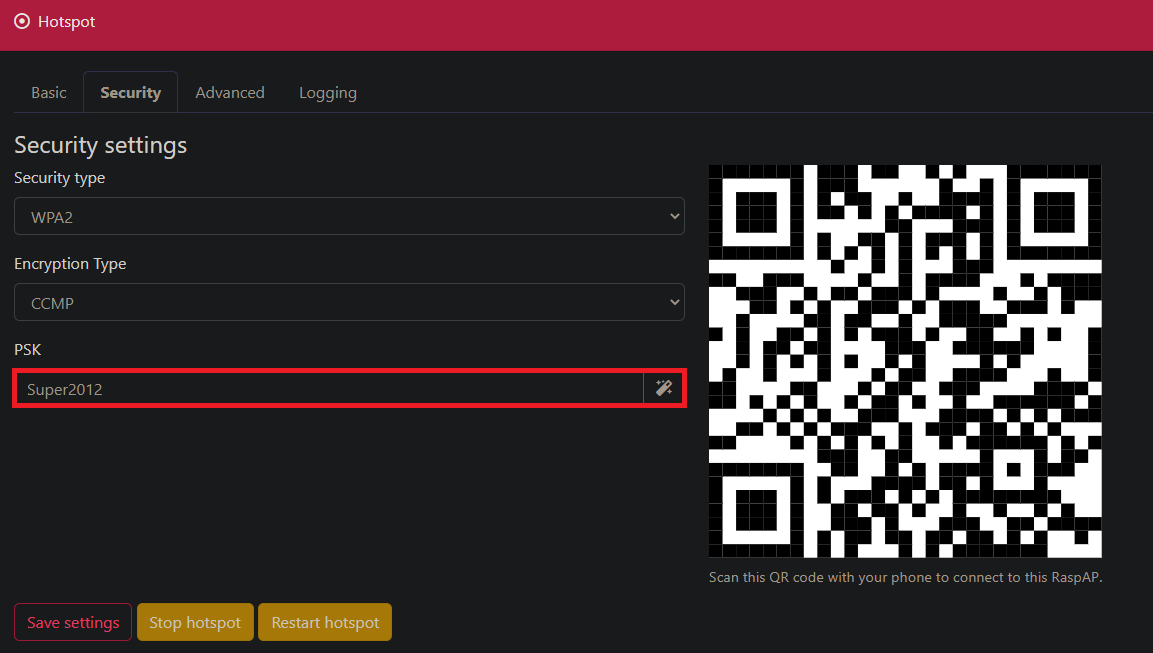
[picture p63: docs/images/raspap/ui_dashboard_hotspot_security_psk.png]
Section Hotsport de RaspAP


Pour terminer, cliquez sur `Restart hotspot` en bas à droite de la page.

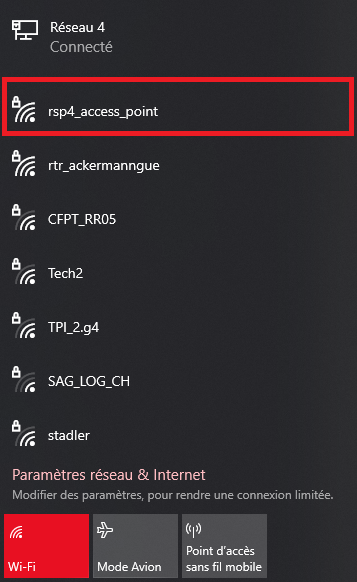
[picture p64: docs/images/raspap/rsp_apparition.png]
Apparition du point d'accès dans la liste des réseaux sans fil disponibles


Si vous souhaitez connaître toutes les personnes connectées sur le réseau, allez dans la section `DHCP Server` :

Onglet de la liste des client connectés au réseau

Une fois sur la page `DHCP Server`, allez dans l'onglet `Client list`. Vous y trouverez une liste comme celle ci :

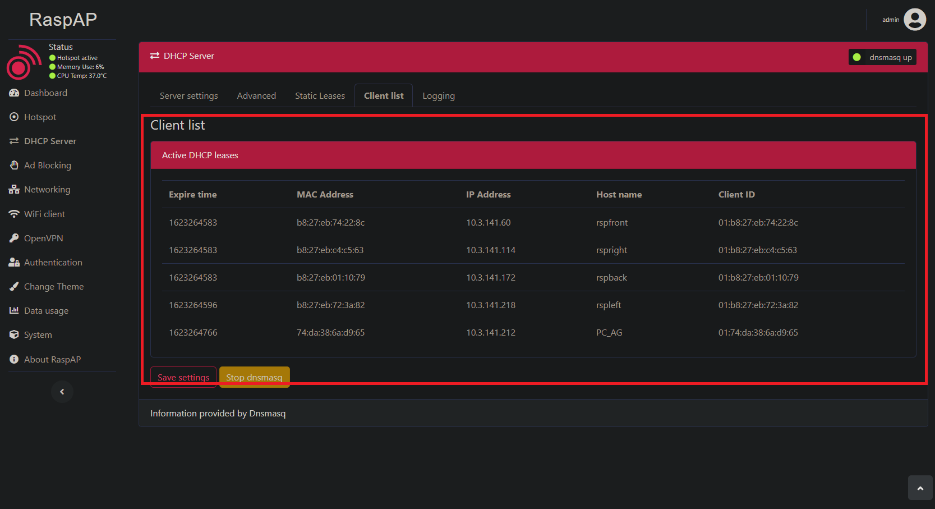
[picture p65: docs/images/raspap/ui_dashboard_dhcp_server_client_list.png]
Liste des client connectés au réseau


## Asyncio ?
[Asyncio](https://docs.python.org/3/library/asyncio-eventloop.html#asyncio.AbstractEventLoop.run_forever) est une librairie python nous permettant d'écrire du code `concurrent` c'est à dire sur différents thread à l'aide de la syntaxe async / await. 

### Mise en place
Pour installer asyncio il faut exécuter la commande `sudo pip3 install asyncio`.

### Utilisation

Voici un code d'exemple pour montrer la mécanique :

```python
import asyncio

try:
    # Tente de récupérer la référence d'une boucle
    loop = asyncio.get_running_loop()
except RuntimeError:  
    # Si aucune référence n'a été trouvée, on crée une nouvelle boucle
    loop = asyncio.new_event_loop()
finally:
    # Exécution de la méthode jusqu'à ce qu'elle soit finie
    loop.run_until_complete(main("Ceci est un message asynchrone"))

async def main(message)
    print(message)
```

Il est important de savoir qu'il existe 2 différentes manières d'exécuter le code.

1. `run_until_complete`, va exécuter le code jusqu'à être arrivé à la fin de la méthode.
2. `run_forever`, va exécuter le code en boucle jusqu'à ce que l'on stop la boucle avec `loop.stop()`.

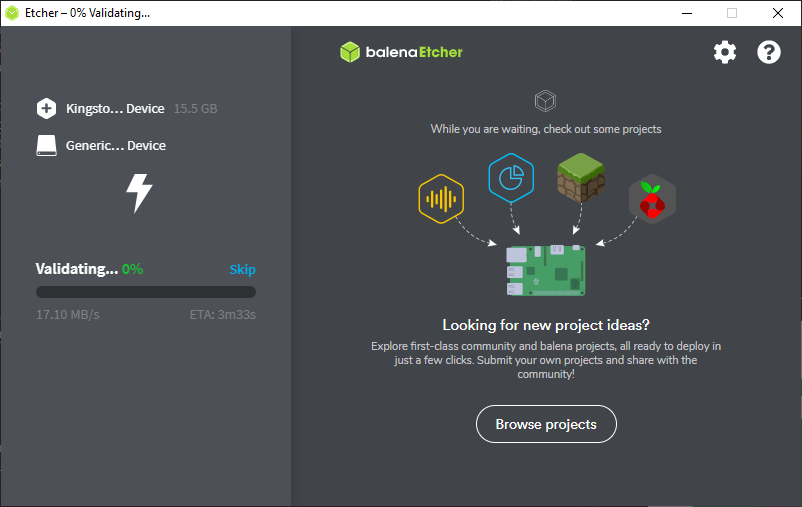
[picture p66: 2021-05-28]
docs/images/clone_sd/balenaEtcher_clone_kingstone_SD_flash_step_2.png

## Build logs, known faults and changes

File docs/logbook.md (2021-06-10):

--- 
title: "Journal de bord du projet"
author: Ackermann Gawen
---
## Journal de bord du travail de diplôme 2021

### 19.04.2021

- J'ai copié le disque dur de M. Bauduccio car le mien causait des soucis
- M. Moreno, M. Huber et moi avons eu un entretien avec M. Bonvin pour discuter des appréciations du stage
- J'ai mis en place mon poste (Création du repository, installation des programmes nécessaires tel que : VS Code, Github Desktop, Suite Office, etc...)
- J'ai lu le chapitre 6 du magpi nommé "Le guide officiel du débutant Raspberry Pi" conseillé par M. Bonvin
- J'ai commencé à m'intéresser à l'utilisation du Remote GPIO pour établir une connexion entre mon Raspberry Pi 4 et celui de M. Moreno
  - Nous avons d'abord mis nos 2 Raspberry Pi sur le même réseau, ensuite nous nous sommes assurés que l'interface `Remote GPIO` était bien active des 2 côtés et nous avons vérifié que `pigpio` était bien installé, puis pour terminer nous avons mis en place le code disponible dans ce [PDF](https://magpi.raspberrypi.org/issues/60) à la page 61 sur le Raspberry Pi de M. Moreno. Avant d'exécuter le programme, nous avons tout deux exécuter la commande suivante dans un terminal `sudo pigpiod`
  - De son côté nous avons utilisé un bouton pressoir et du miens une LED
  - breadboard de M. Moreno
    - Le bouton est connecté au GPIO 2, donc la pin 3
  - breadboard de M. Ackermann
    - La led est connectée au GPIO 17, donc la pin 11
  - Le code disponible sur la machine de M. Moreno va attendre que le bouton soit pressé, une fois ceci fait, la LED connecté en remote (liée à mon Raspberry Pi) se vera allumée.
- J'ai commencé mes recherches sur l'échange d'informations par bluetooth entre 2 Raspberry Pi 4
  - J'ai tenté de mettre en place le code disponible sur ce [repos](https://gist.github.com/keithweaver/3d5dbf38074cee4250c7d9807510c7c3) mais j'avais l'erreur suivante `ModuleNotFoundError: No module named 'bluetooth'`, pourtant j'avais déjà le bluetooth d'installé ainsi que blueman. En faisant des recherches je suis tombé sur cette commande `sudo apt-get install bluetooth libbluetooth-dev && sudo python3 -m pip install pybluez`. Depuis l'installation des 2 commandes je n'ai plus d'erreurs d'import.

#### Liens consultés

##### Remote GPIO

- https://www.instructables.com/Remote-control-Raspberry-PI-GPIO-pins-over-the-int/
- https://www.instructables.com/Raspberry-Pi-Remote-GPIO/
- https://magpi.raspberrypi.org/articles/remote-control-gpio-raspberry-pi-gpio-zero
- https://magpi.raspberrypi.org/issues/60

##### Échange d'informations par bluetooth entre 2 Raspberry Pi 4

- https://technologisttips.com/raspberry-pi-bluetooth/
- https://bluedot.readthedocs.io/en/latest/pairpipi.html
- https://gist.github.com/keithweaver/3d5dbf38074cee4250c7d9807510c7c3
- https://www.stuffaboutcode.com/2017/07/python-bluetooth-rfcomm-client-server.html
- https://bluedot.readthedocs.io/en/latest/pairpipi.html
- https://stackoverflow.com/questions/23985163/python3-error-no-module-named-bluetooth-on-linux-mint#23985374

### 20.04.2021

- M. Moreno et moi avons continué l'échange d'informations par bluetooth entre nos 2 Raspberry Pi 4
  - De mon côté, j'ai utilisé les fonctions suivantes :
    - `lookUpNearbyBluetoothDevices`, va lancer un scan bluetooth pour découvrir les appareils alentours. Pour chaque appareil trouvés, ils vont être affichés dans la console, si l'un de ces appareils est nommé `morenoPi42` alors son adresse mac se voit être retournée pour être utilisée en paramètre par la fonction ci-dessous.
    - `sendMessageTo` va se connecter à un appareil à l'aide de son adresse mac et d'un port désigné (le port 1 dans notre cas) pour ensuite lui envoyé une information et fermner la connexion.
- Du côté de M. Moreno, il a utilisé la méthode `receiveMessage` qui va écouter sur le port spécifié (dans notre cas, il s'agit toujours du port 1), qui va ensuite accepter la connexion entrante jusqu'à 1024 bytes, puis affiche dans la console les données reçues, une fois cela fait, elle va fermer les sockets de connexion.
  Scan bluetooth des environs
  Transfère de données entre les 2 Raspberry Pi 4
- Avec M. Moreno, nous avons modifié le programme pour en faire un t'chat par bluetooth. Pour lancer le programme, il faut utiliser la commande suivante en remplaçant le _XXXX_ par le nom d'hôte de l'appareil bluetooth : `python3 bluetooth_data_transfer.py XXXX`
  - En premier temps nous avons pensé regrouper l'ouverture des sockets dans une fonction d'initialisation afin d'avoir une trace sur les sockets pour pouvoir les fermer lorsque cela est voulu.
    - Nous avons une erreur nous indiquant ceci `_bluetooth.error: (111, 'Connection refused')`, cela nous a fait comprendre que pour s'envoyer des informations, il faut que l'un écoute pendant que l'autre parle et réciproquement dans l'autre sens.
    - Nous avons mis en place une boucle while qui tourne constamment. Dans cette boucle, il y a des if qui vérifient le mode actuel.
      - 0 veut dire que nous sommes en attente d'un message
      - 1 veut dire que nous allons envoyé un message

T'chat en bluetooth

1. Affiche le nom d'hôte et l'adresse mac de l'appareil connecté
2. Espace de saisie de message à envoyer
3. Connexion réussie à l'appareil (adresse mac, port)
4. Réception du message
5. Espace de saisie de message à envoyer, utilisant une commande personnalisée pour quitter le programme

- J'ai commencé mes recherches sur le `Technic Hub`.

#### Liens consultés

##### Échange d'informations par bluetooth entre 2 Raspberry Pi 4

- https://pybluez.readthedocs.io/en/latest/api/bluetooth_socket.html

##### Sockets

- https://docs.python.org/3/library/socket.html

##### Récupération de saisie utilisateur

- https://pythonprogramminglanguage.com/user-input-python/

##### Récupération de paramètres en ligne de commande Python

- https://www.pythonforbeginners.com/system/python-sys-argv

##### Bluetooth LEGO

- https://lego.github.io/lego-ble-wireless-protocol-docs/
- https://github.com/hoharald/leguno-remote

### 21.04.2021

- J'ai commencé la journée par lire [cet article sur le bluetooth](https://www.novelbits.io/deep-dive-ble-packets-events/) pour tenter d'approfondir mes connaissances afin de régler le problème de connexion entre le Raspberry Pi et le `Technic Hub`. Après avoir lu l'article, j'ai tenté de relancer le code d'exemple disponible sur le repos [Bricknil](https://github.com/virantha/bricknil), malheureusement j'avais toujours la même erreur. Je me suis dit que j'allais tenté de créer un script python qui ne fait que se connecter pour l'instant pour pouvoir ensuite tenté d'envoyer des ordres par bluetooth.
  - J'ai commencé par essayer de lire dans [cette documentation](https://lego.github.io/lego-ble-wireless-protocol-docs/index.html#port-information-request) et de comprendre comment je pouvais envoyer des messages que le `Technic Hub` pourrait comprendre. J'ai donc en un premier temps cherché à comprendre si c'était à moi d'envoyé le premier message et sur quel port ou de faire l'inverse, c'est-à-dire moi écouter un port particulier car à chaque fois que depuis l'interface graphique ou par commande dans le terminal, quand je tente de me connecter au `Technic Hub`, j'ai toujours cette erreur ci : `Failed to pair: org.bluez.Error.AuthenticationFailed`.
  - La première chose que j'ai constaté, c'est que des fois après avoir beaucoup tenté d'utiliser le bluetooth de redémarrer le Raspberry Pi car il a de la peine à capter les appareils alentours, tandis qu'une fois redémarré, si l'on utilise `bluetoothctl`, qu'on active le scan avec `scan on`, on peut voir les informations suivantes :

```
[NEW] Device 90:84:2B:50:36:43 Technic Hub
[CHG] Device 90:84:2B:50:36:43 RSSI: -58
[CHG] Device 90:84:2B:50:36:43 TxPower: 0
[CHG] Device 90:84:2B:50:36:43 ManufacturerData Key: 0x0397
[CHG] Device 90:84:2B:50:36:43 ManufacturerData Value:
  00 80 06 00 61 00                                ....a.
```

- RSSI (Received Signal Strength Indicator) représente la mesure du niveau de la puissance au niveau du récepteur. Il est mesuré en dBm, sur une échelle logarithmique et étant négatif. Plus le nombre est négatif, plus le dispositif est éloigné. Par exemple, une valeur de -20 à -30 dBm indique que le dispositif est proche, tandis qu'une valeur de -120 indique que le dispositif est proche de la limite de détection.
- TxPower représente la puissance du signal. Pour un émetteur Bluetooth, 0 dBm (décibel-milliwatt) est le niveau de puissance standard
- ManufacturerData Key: 0x0397 est le code de LEGO System A/S
- ManufacturerData Value: 00 80 06 00 61 00
  1. Longueur des données (0x09)
  2. Le nom du type de données (0xFF)
  3. L'ID du fabricant (0x0397)
  4. L'état du bouton (entre 0x00 et 0x01)
  5. Le type de système et le numéro de l'appareil (entre 0x00 et 0xFF)
  6. Les capacités de l'appareil (entre 0x01 et 0xFF)
  7. L'id du précédent réseau (entre 0x00 et 0xFF)
  8. Le statut actuel (entre 0x00 et 0xFF)
- En continuant mes recherches, je me suis demandé s'il n'était pas une bonne idée de tester petit à petit ce que propose le code de Bricknil pour ensuite l'implémenté petit à petit. Le premier élément que je voulais tester était le `bleak` car j'avais vu lorsque je lançais le code de Bricknil qu'il y avait un message contenant le nom de ce module. Pour installer `bleak`, `pygatt` et `bluepy` j'ai utilisé cette commande : `sudo pip3 install pygatt && pip3 install gatt && pip3 install gattlib && pip3 install bluepy && pip3 install bleak`. Une fois cela fait, j'ai donc été sur [le repos officiel](https://github.com/hbldh/bleak) pour exécuter le code présent. Le premier code nous montre la méthode `discover` tandis que le second nous montre une manière de s'appareiller.
  - La première chose que j'ai faite c'est de tester la connexion. Pour ce faire, j'ai testé la méthode `discover` disponible grâce à `BleakScanner`. J'ai pu voir apparaître le `Technic Hub` dans la liste des appareils détectés. Pour tenter de me "connecter", j'ai utilisé l'adresse mac tel que : `90:84:2B:50:36:43` ainsi que le `Characteristic UUID` tel que : `00001624-1212-EFDE-1623-785FEABCD123` qui va ensuite retourner le numéro de modèle. La led sur le `Technic Hub` devient bleue lorsque je lance le programme et que la méthode `read_gatt_char` est exécutée. Cette méthode retourne un array de byte, dans mon cas voici ce qu'elle me retourne `\x05\x00\x04\x03\x00.\x00\x00\x10\x00\x00\x00\x10\x00\x00\x00\x00\x00\x00\x00`, autrement écrit : `50430460016000160000000`.

#### Liens consultés

##### Bluetooth

- https://www.novelbits.io/deep-dive-ble-packets-events/
- https://punchthrough.com/crash-course-in-2m-bluetooth-low-energy-phy/
- https://github.com/karulis/pybluez
- https://www.bluetoothle.wiki/tx_power
- https://www.bluetoothle.wiki/rssi?s[]=rssi
- https://www.bluetooth.com/specifications/assigned-numbers/company-identifiers/
- https://lego.github.io/lego-ble-wireless-protocol-docs/index.html
- https://bleak.readthedocs.io/en/latest/usage.html
- https://github.com/hbldh/bleak
- https://learn.adafruit.com/introduction-to-bluetooth-low-energy/gatt

##### Repos Bricknil

- https://github.com/virantha/bricknil

##### Date avec python

- https://www.tutorialspoint.com/How-to-print-current-date-and-time-using-Python

### 22.04.2021

- J'ai continué mon travail sur le bluetooth. Histoire d'y voir un peu plus claire je me suis résigné à faire un schéma explicant + en détails quelles sont les valeurs que nous avons reçu et qu'est-ce qu'elles veulent dire à l'aide de [la documentation de Lego pour le Bluetooth](https://lego.github.io/lego-ble-wireless-protocol-docs/index.html#advertising). J'ai remarqué un potentiel problème. Soit c'était moi qui n'arrivait pas à comprendre comment le tableau des Manufacturer Data était conçu ou si juste les données reçus par le bluetooth lors du scan de l'appareil étaient incomplètes.
  - Comme on peut le voir ci-dessous, je n'ai pas pris en compte l'ID du fabricant car comme vu ici : `[CHG] Device 90:84:2B:50:36:43 ManufacturerData Key: 0x0397`, il a ne semble pas avoir de champ pour lui dans le `[CHG] Device 90:84:2B:50:36:43 ManufacturerData Value: `. J'ai tenté de rentrer les informations suivantes : `00 80 06 00 61 00` en prenant compte de la taille min et max de chaque cellules (voir [la documentation de Lego pour le Bluetooth](https://lego.github.io/lego-ble-wireless-protocol-docs/index.html#advertising)) pour calculer la longueur de la trame, j'ai ensuite vérifié que les données puissent rentrer dans les champs et c'est à ce moment que j'ai commencé à me demander si quelque chose ne jouait pas.
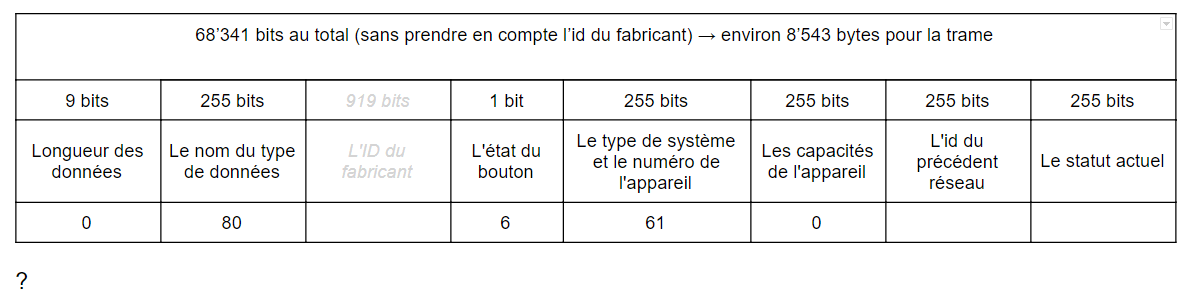
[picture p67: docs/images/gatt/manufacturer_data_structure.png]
Représentation du tableau des Manufacturerdata
    
  - En effectuant des recherches, je suis tombé sur [cet article](https://docs.silabs.com/bluetooth/2.13/code-examples/stack-features/adv-and-scanning/adv-manufacturer-specific-data). Il parlait d'une application smarthphone nommée `EFR Connect`. J'en avais besoin car je voulais avoir plus d'informations concernant les `Manufacturer Data`. J'ai lancé un scan depuis l'application, et en ce qui concerne voici les informations que l'application m'a retrounée :
    1. Flags : `0x06: LE General Discoverable Mode, BR/EDR Not Supported`
    2. Complete list of 128-bit service class UUIDs : `00001624-1212-EFDE-1623-785FEABCD123`
    3. Manufacturer Data :
       1. Company Code : `0x0397`
       2. Data : `0x008006004100`
       3. Slave connection interval range : `20.0ms`
       4. Tx power level: `0 dBm`
       5. Complete local name : `Technic Hub`
- Je me suis ensuite connecté au `Technic Hub` avec l'application, j'ai vu apparaître un sous menu m'affichant 3 sections :
  1. Generic attribute : `0x1801`
     1. UUID : `0x2A05`
     2. Descriptor : _champs vide_
     3. Client characteristic configuration : `0x2902`
  2. Generic access :
     1. Device name : `0x1800`
     2. Appearance : `0x2A01`
     3. Peripheral preffered connection parameters : `0x2A04`
        1.
  3. _Unknown Service_ :
     1. UUID : `00001624-1212-EFDE-1623-785FEABCD123`
     2. Descriptor : _champs vide_
     3. Client characteristic configuration : `0x2902`
     4. Value : `50430460016000160000000` mais lorsque depuis l'application j'active le mode `notify` sa valeur change à `0F 04 64 01 36 00 01 00 00 00 01 00 00 00 00 00 00 00 00`
- En voyant ces données je me suis dit que j'avais pris les mauvaises données à mettre dans le tableau des Manufacturer Data. J'ai abandonné l'idée de remplir le tableau de Manufacturer Data car ces données ne correspondaient pas. En revanche, j'ai tenté de jouer avec l'application `EFR Connect` car on peut lire, écrire et être notifié. Lorsque je me connecte au `Technic Hub` et que je lit les données présentes voici ce que je reçois : `0F 04 64 01 36 00 01 00 00 00 01 00 00 00 00 00 00 00 00`. J'ai ensuite essayer d'envoyer la commande `Hub Properties` car on peut envoyer de l'hexadécimal au hub, j'ai donc tenté avec les valeurs du tableau [ici présent](<(https://lego.github.io/lego-ble-wireless-protocol-docs/index.html#message-types)>). Ensuite, avec le mode écriture lorsque j'ai relus le contenu avec changé et était devenu : `05 00 05 00 05 36 00 01 00 00 00 01 00 00 00 00 00 00 00 00`. En me balandant sur internet je suis retombé sur [ce lien](https://brickarchitect.com/powered-up/#footnote1) qui disait que le `Technich Hub` peut uniquement être programmé avec le firmware de PyBricks. J'ai donc essayé de télécharger [le repos git](https://github.com/pybricks/pybricks-micropython) et d'installer le firmware "manuellement" afin de pouvoir écrire mes propres script python pour contrôler la voiture. J'ai suivi le tutoriel de mise en place pour un environnement de développement mais je n'ai réussi à le mettre en place. Je suis ensuite tombé sur [cette issue git](https://github.com/pybricks/support/issues/167) qui met à disposition des fichier de firmware pour les hub `Spike` et `Mindstorm`. J'ai ensuite retenté de comprendre comment lire [la documentation de Lego](https://lego.github.io/lego-ble-wireless-protocol-docs/index.html).

#### Liens consultés

##### Bluetooth

- https://lego.github.io/lego-ble-wireless-protocol-docs/index.html
- https://stackoverflow.com/questions/52352378/manufacturer-specific-data-on-ble
- https://docs.silabs.com/bluetooth/2.13/code-examples/stack-features/adv-and-scanning/adv-manufacturer-specific-data
- https://brickarchitect.com/powered-up/#footnote1
- https://github.com/pybricks/pybricks-micropython
- https://github.com/pybricks/support/issues/167
- https://github.com/pybricks/pybricksdev

### 23.04.2021

- J'ai commencé la journée par lire cette documentation pour mieux comprendre ce qu'est GATT et comment il est structuré, pour pouvoir l'utiliser ensuite. Les attributs GATT sont des éléments d'information adressables qui peuvent contenir des données utilisateur pertinentes (ou métadonnées) sur la structure et le regroupement des différents attributs contenus dans le serveur. Gatt est structuré de la manière suivante :

  - Roles
    - Client
    - Server
  - UUID
  - Attributes
    - Handle : 0x0000 = dénote un handle invalde, le montant d'handle dipsonible sur chaque serveur GATT est 0xFFFF (soit 16 bits, 65535)
    - Type : détermine le type de donnée des valeurs de l'attribut, il s'agit d'un UUID
    - Permissions
      - Access permissions : similaire au droit lié aux fichiers (None, Readable, Writable, Readable & Writable)
      - Encryption :
        - Security mode 1, level 1
          - Attribut accessible en texte, connexion non encryptée
        - Security mode 1, level 2
          - La connexion doit être encryptée pour avoir accès à l'attribut, mais les clés d'encryptions non pas besoin d'être authentifiées
        - Security mode 1, level 3
          - La connexion doit être encryptée avec des clés authentifiées pour avois accès à l'attribut.
      - Autorization : détermine si une permission utilisateur est nécessaire
    - Value : Contient les données de l'attribut, il n'y a pas de restrictions pour le type de données qu'il contient mais jusqu'à une limite de 512 bytes
  - Attribute and data hierarchy
    - Architecture GATT
      - GATT Server : Technic Hub
      - Service : Generic Attribute
        - Characteristic : Service Change
      - Service : Generic Access
        - Characteristic : Device Name
        - Characteristic : Appearance
        - Characteristic : Peripheral Preferred Connection Parameters
      - Service : LegoTechnicHub (renommée car de base l'application affichait Unknown service)
        - Characteristic : Unknown Charateristic
    - Les attributs sont groupés en _services_, chaque _services_ peut contenir 0 ou + _characteristics_. Ces dernières peuvent avoir de 0 à + _descriptors_
  - Advanced attribute concepts
  - Features
  - Security
  - GATT service

- J'ai installé gatt à l'aide de la commande `sudo pip3 install gatt`. Ensuite j'ai scanné les alentours avec la commande `sudo gattctl --discover`. Une fois que j'ai vu apparaître le `Technic Hub` je m'y suis connecté à l'aide de `sudo gattctl --connect 90:84:2B:50:36:43`. On peut voir que les données reçues sont bien celles présentes dans l'application `EFR Connect` :

```
Connecting...
[90:84:2b:50:36:43] Discovered, alias = Technic Hub
[90:84:2b:50:36:43] Connected
[90:84:2b:50:36:43] Discovered, alias = Technic Hub
[90:84:2b:50:36:43] Resolved services
[90:84:2b:50:36:43]  Service [00001623-1212-efde-1623-785feabcd123]
[90:84:2b:50:36:43]    Characteristic [00001624-1212-efde-1623-785feabcd123]
[90:84:2b:50:36:43]  Service [00001801-0000-1000-8000-00805f9b34fb]
[90:84:2b:50:36:43]    Characteristic [00002a05-0000-1000-8000-00805f9b34fb]
```

- M. Bonvin m'a montré comment utiliser [QCad](https://qcad.org/en/), c'est un outil de dessin technique assité.
- Je me suis ensuite remis sur [la documentation](https://www.oreilly.com/library/view/getting-started-with/9781491900550/ch04.html) pour comprendre comment cela marchait. J'ai exécuter le second code présent sur [le repos](https://github.com/getsenic/gatt-python) mais cette erreur m'est apparue :

```
ERROR:dbus.connection:Exception in handler for D-Bus signal:
Traceback (most recent call last):
  File "/usr/local/lib/python3.7/dist-packages/dbus/connection.py", line 232, in maybe_handle_message
    self._handler(*args, **kwargs)
  File "/home/pi/.local/lib/python3.7/site-packages/gatt/gatt_linux.py", line 398, in properties_changed
    self.services_resolved()
  File "gatt_connection.py", line 10, in services_resolved
    s for s in self.services
StopIteration
```

- J'ai été voir sur internet ce que l'erreur `ERROR:dbus.connection:Exception in handler for D-Bus signal` voulait signifier. Je n'ai pas réussis à trouver d'informations pertinentes, donc je me suis remis sur le script python utilisant GATT. J'ai tenté de modifier le second code afin d'être sûr qu'il fonctionnait. Il semble donc que l'erreur vienne du second script. J'ai cherché ce quel élément pose problème mais je peine encore à trouver le problème.

#### Liens consultés

##### Bluetooth

- http://software-dl.ti.com/lprf/sdg-latest/html/ble-stack-3.x/gatt.html
- https://www.oreilly.com/library/view/getting-started-with/9781491900550/ch04.html
- https://www.oreilly.com/library/view/getting-started-with/9781491900550/ch02.html#Protocol_Stack
- https://doc.qt.io/qt-5/qtbluetooth-le-overview.html
- https://github.com/getsenic/gatt-python

### 26.04.2021

#### Liens consultés

- Pour commencer la semaine, je me suis dit que regarder des vidéos explicative sur le fonctionnement de `GATT` et du bluetooth en général, car ayant passé la semaine passée sur de la documentation explicative sur `GATT` mais qui ne m'avait pas aidé à résoudre les soucis que j'avais.
- Comme pour le 23.04.2021, je vais tenter de refaire une explication détaillée du fonctionnement de GAP et `GATT` car ça me permettera de l'inclure plus aisément dans la documentation que je n'ai toujours pas commencée à l'heure actuelle, mais je me suis dit qu'aujourd'hui devait être le dernier délai pour conclure cette histoire de bluetooth car il faut que je me concentre sur la documentation technique sachant qu'elle sera évaluée le 30.04.2021.
  - `GAP`, _Generic Access Profile_, contrôle les connexions ainsi que l'avertissement déterminant comment les 2 appareils vont pouvoir ou pas intéragir.
  - `GATT`, _Generic Attribute Profile_ ,définit comment les 2 appareils vont échanger des données composées de _Services_ et de _Characteristics_. Ce protocole intérvient uniquement une fois le `GAP` passé.
- J'ai repris la structure que j'avais faite pour montrer la structure du `Technic Hub` au niveau `GATT` :
  - Profile : Technic Hub
    - Service : Generic Attribute
      - Characteristic : Service Change
    - Service : Generic Access
      - Characteristic : Device Name
      - Characteristic : Appearance
      - Characteristic : Peripheral Preferred Connection Parameters
    - Service : LegoTechnicHub (renommée car de base l'application affichait Unknown service)
      - Characteristic : Unknown Charateristic
- Comme on peut le voir, Profile contient une collection de services. Ces derniers divisent les données en entités logiques qui contiennent des blocs de données spécifiques appelés caractéristiques. Ce sont ces caractéristiques qui contiennent les données importantes.
- Depuis l'application mobile `EFR Connect`, j'ai tenté dans la characteristic concernant le `Technic Hub` d'écrire des commandes de la manière suivante : Dans la [documentation lego](https://lego.github.io/lego-ble-wireless-protocol-docs/index.html) les commandes sont dans un chapitre `Output Command 0x81`. Dans ce chapitre, les commandes présentent sont écrites comme suit `StartPower (Power1, Power2): Output Command 0x81 - Sub Command 0x02`. Étant donné qu'il s'agit de _sub command_, je ne sais pas si écrire en hexa une suite de bytes en hexa permet d'exécuter une commande. En tout cas, depuis que j'ai tenté d'écrire une commande, lorsque j'ai activé le mode _notify_ la valeur retournée est la suivante `0F 00 04 61 01 39 00 01 00 00 00 01 00 00 00`.
- Je sais que je change de cap souvent, mais étant un peu perdu je tente d'explorer chaques idées qui me vient en tête. Celle que je viens d'avoir concerne l'utilisation du code présent sur [le repos de pyboost](https://github.com/JorgePe/pyb00st), car même s'il concerne le LEGO Boost Move Hub je me suis dit qu'il y a moyen que puisse l'utiliser. De plus sur la documentation de [Lego Wireless Protocol](https://lego.github.io/lego-ble-wireless-protocol-docs/index.html) il parlait de SDK, je me suis dit qu'il fallait que je trouve un bon SDK et je suis alors tombé en premier temps sur celle de `pyb00st`. Par conséquent, j'ai cloné le repos sur le Raspberry Pi afin d'exécuter les codes d'exemples.
  - J'ai commencé par utiliser la méthode `set_led_color(color)` pour voir si la connexion et les méthodes intéragissaient avec le `Technic Hub`. Résultat, ça fonctionne. Maintenant je vais m'intéresser aux méthodes touchant aux moteurs. je n'ai pas réussi à implémenter `pyb00st`, cependant je me suis dit que d'utiliser le code de [pylgbst](https://github.com/undera/pylgbst) pourrait fonctionner car j'ai été lire la [documentation Lego](https://lego.github.io/lego-ble-wireless-protocol-docs/index.html), et vu qu'elle parle de commandes à envoyé, j'ai été voir s'il en proposait. Après quelque recherche, j'ai vu que oui. Même si rien n'était écris à propos du `Technic Hub`, je me suis lancé en me disant que ça doit être exactement le même mécanisme.
  - J'ai commencé par utiliser la méthode `get_connection_auto()`, cette fonction va choisir parmi la liste suivante :
    - bluepy
    - bluegiga
    - gatt
    - bleak
    - gattool
    - gattlib
  - À noter qu'on peut choisir par nous même quel type de connexion nous voulons établir en reprennant `get_connection_auto()` mais en replaçant le `auto` par l'un des moyens disponible ci-dessus.
  - M'étant documenté ces dernier jours sur `GATT` et ayant utilisé un code fonctionnel, je suis partit du postulat que ça devrait fonctionné sans soucis. J'ai donc commencé par utiliser la méthode `get_connection_gatt()` en lui spécifiant l'adresse mac de l'appareil comme suit : `get_connection_gatt(hub_mac="90:84:2B:50:36:43")`. La méthode affiche ceci dans la console :

```
Have not dedicated class for peripheral type 0x2f on port 0x0
Have not dedicated class for peripheral type 0x2f on port 0x1
Have not dedicated class for peripheral type 0x2e on port 0x2
Have not dedicated class for peripheral type 0x3c on port 0x3d
Have not dedicated class for peripheral type 0x3c on port 0x60
Have not dedicated class for peripheral type 0x39 on port 0x61
Have not dedicated class for peripheral type 0x3a on port 0x62
Have not dedicated class for peripheral type 0x3b on port 0x63
Have not dedicated class for peripheral type 0x36 on port 0x64
Got only these devices: (Peripheral on port 0x0, Peripheral on port 0x1, None, LEDRGB on port 0x32, None, Current on port 0x3b, Voltage on port 0x3c)
```

- Une fois ceci affiché, j'ai crû comprendre que la connexion était bien établie et que des commandes pouvait être envoyées. J'ai regardé dans les fichiers _peripherals_ et _hub_ fournis par `pylgbst` comment était structuré la classe moteur et quels fonctions étaient disponibles.
- Après avoir compris, j'ai écrit ce bout de code :

```python
from pylgbst.hub import MoveHub
from pylgbst.peripherals import Motor
from pylgbst import *

MY_MOVEHUB_ADD = "90:84:2B:50:36:43"
MY_BTCTRLR_HCI = "hci0"

conn = get_connection_gatt(hub_mac=MY_MOVEHUB_ADD)
try:
    movehub = MoveHub(conn)
    motor_a = Motor(movehub, movehub.PORT_A)
    motor_c = Motor(movehub, movehub.PORT_C)
    motor_a.start_power(-1)
    motor_c.start_power(1)
    conn.disconnect()
finally:
    conn.disconnect()
```

- Ce bout de code fonctionne parfaitement. Entre temps j'ai écris celui ci qui fonctionne parfaitement lui aussi :

```python
  #!/usr/bin/env python3

from pylgbst.hub import MoveHub
from pylgbst.peripherals import Motor
from pylgbst import *
from time import sleep

MY_MOVEHUB_ADD = "90:84:2B:50:36:43"
MY_BTCTRLR_HCI = "hci0"

def play_scenario(movehub):
    motor_a = Motor(movehub, movehub.PORT_A)
    motor_b = Motor(movehub, movehub.PORT_B)
    motor_c = EncodedMotor(movehub, movehub.PORT_C)

    print("Forward:")
    forward(motor_a, motor_b, motor_c)
    sleep(1)

    print("Downward:")
    downward(motor_a, motor_b, motor_c)
    sleep(1)

    print("Left:")
    go_left(motor_a, motor_b, motor_c)
    sleep(1)

    print("Right:")
    go_right(motor_a, motor_b, motor_c)
    sleep(1)

def forward(motor_1, motor_2, motor_3):
    motor_1.start_power(-1)
    motor_2.start_power(-1)
    motor_3.start_power(0)
    print("done!")

def downward(motor_1, motor_2, motor_3):
    motor_1.start_power(1)
    motor_2.start_power(1)
    motor_3.start_power(0)
    print("done!")

def go_left(motor_1, motor_2, motor_3):
    motor_1.start_power(0)
    motor_2.start_power(0)
    motor_3.start_power(-1)
    print("done!")

def go_right(motor_1, motor_2, motor_3):
    motor_1.start_power(0)
    motor_2.start_power(0)
    motor_3.start_power(1)
    print("done!")

conn = get_connection_gatt(hub_mac=MY_MOVEHUB_ADD)
try:
    movehub = MoveHub(conn)
    play_scenario(movehub)
    conn.disconnect()
finally:
    conn.disconnect()
```

- Cependant de temps en temps quand je relance le programme. Cette erreur apparaît :

```
Traceback (most recent call last):
  File "pylgbst_bluetooth.py", line 53, in <module>
    conn = get_connection_gatt(hub_mac=MY_MOVEHUB_ADD)
  File "/usr/local/lib/python3.7/dist-packages/pylgbst/__init__.py", line 25, in get_connection_gatt
    return GattConnection(controller).connect(hub_mac, hub_name)
  File "/usr/local/lib/python3.7/dist-packages/pylgbst/comms/cgatt.py", line 100, in connect
    for dev in devices:
RuntimeError: dictionary changed size during iteration
```

- Pour la résoudre, en général, j'éteins le bluetooth puis je le rallume et cela semble résoudre le problème de temps en temps. De temps à autre cette technique ne fonctionne pas et je dois redémarrer le Raspberry Pi afin de régler le problème. J'ai essayé pendant un long moment à mettre en place un système qui permetterai de reset l'angle du moteur gérant la direction. Le problème que j'ai est que je n'ai pas réussi à trouver les valeurs minimals et maximales pour les angles, car lorsque l'on dit au moteur d'utiliser la fonction `angled(degrees=-150)` suivi de `angled(degrees=75)`, ce qui devrait mettre le moteur tout à droite puis au centre mais le problème est qu'après la première instruction, l'exécution s'arrête. Est-ce que la première valeur fait crash le programme ?
  - Ayant pratiquement terminé avec le bluetooth, je me suis dit que je devais commencer la documentation technique car pour l'heure rien n'avait été fait à ce sujet.

##### Bluetooth Youtube

- https://www.youtube.com/watch?v=u4HY3OIk2-c
- https://www.youtube.com/watch?v=MzM3-YWftxE
- https://www.youtube.com/watch?v=E8_5UZWDgMo
- https://www.youtube.com/watch?v=eHqtiCMe4NA

##### Bluetooth

- http://software-dl.ti.com/lprf/sdg-latest/html/ble-stack-3.x/gatt.html#gatt-characteristics-and-attributes
- https://www.oreilly.com/library/view/getting-started-with/9781491900550/ch04.html#gatt_attr_table
- https://devzone.nordicsemi.com/f/nordic-q-a/6700/adding-characteristic-user-description-0x2901-0x2902
- https://github.com/getsenic/gatt-python
- https://bleak.readthedocs.io/en/latest/usage.html
- https://lego.github.io/lego-ble-wireless-protocol-docs/index.html
- https://github.com/peplin/pygatt
- https://github.com/JorgePe/pyb00st
- https://github.com/undera/pylgbst

### 27.04.2021

- J'ai débuté la journée en continuant le documentation technique.
- Durant l'après-midi, avec M. Ray Yvelin, M. Bonvin et moi même, nous sommes aller apporter du matériel en C305 à Ternier et nous avons pris dans cette salle :
  - 1 Oscilloscope
  - 1 Alimentation stabilisée
  - Les câbles associés au éléments ci-dessus
  - Des tournevis
  - 1 Fer à souder avec de la soudure
  - 1 Multimètre
  - 1 Étaux
- Après cela j'ai continué à travailler sur la documentation technique.

#### Liens consultés

##### Données relatives au capteurs

- https://pijaeducation.com/arduino/sensor/ir-sensor-and-arduino/
- https://fr.wikipedia.org/wiki/Baud_(mesure)
- https://fr.wikipedia.org/wiki/UART
- http://bucket.download.slamtec.com/20b2e974dd7c381e46c78db374772e31ea74370d/LD208_SLAMTEC_rplidar_datasheet_A2M8_v2.6_en.pdf
- https://en.wikipedia.org/wiki/Pulse-width_modulation
- https://github.com/Slamtec/rplidar_sdk/releases/tag/release%2Fv1.12.0

### 28.04.2021

- J'ai continué la documentation technique. Après l'entretien avec M. Bonvin, j'ai mis à disposition le code écrit sur le Raspberry Pi, puis je me suis remis à travailler sur la documentation technique. Pour expliquer plus en détails les composants qui composeront le voiture, j'ai réalisé ce croquis :

Croquis du plan de la voiture

- J'ai tenté d'importer l'état actuel de ma documentation technique sur ReadTheDoc, mais la version en ligne qui créait une documentation à partir d'un repository Github ne fonctionnait pas vraiment. J'ai alors installé MkDocs pour générer la documentation à partir du fichier Markdown.

#### Liens consultés

##### Flask

- https://flask.palletsprojects.com/en/1.1.x/quickstart/

##### MkDocs

- https://www.mkdocs.org/#installation

### 29.04.2021

- J'ai commencé par définir plus clairement ce qu'était le bluetooth dans la documentation technique.
- J'ai recompilé la documentation technique avec MkDocs pour avoir un aperçu de la mise en forme.
  - J'ai eu des soucis de mise en page en ce qui concerne les listes à points ou numérotées tandis qu'affiche en Markdown fonctionnent très bien.
  - Pour ne pas perdre plus de temps dessus j'ai commenté tous le code écrit.
  - Après avoir tous commenté, je me suis remis sur la documentation afin d'expliquer le T'chat bluetooth fait en collaboration avec M. Moreno
  - Pour terminer la journée j'ai corrigé les problèmes de mise en forme pour la conversion avec MkDocs.

#### Liens consultés

##### Bluetooth

- https://arduino.stackexchange.com/questions/18895/how-master-and-slave-concept-works-with-bluetooth
- https://fr.wikipedia.org/wiki/S%C3%A9curit%C3%A9_des_protocoles_Bluetooth
- https://fr.wikipedia.org/wiki/Contr%C3%B4le_de_redondance_cyclique
- https://fr.wikipedia.org/wiki/Protocol_Data_Unit
- http://software-dl.ti.com/lprf/sdg-latest/html/ble-stack-3.x/gap.html#connection-parameters

### 30.04.2021

- J'ai customisé le thème de la documentation générée par MkDocs.
- J'ai mis à disposition la documentation technique sur ReadTheDocs : https://ackermanngue-ag-dipl-tech-2021-voitureassistee.readthedocs.io/fr/latest/documentation_technique/
- J'ai avancé la documentation technique afin de pouvoir me concentrer sur l'implémention de Flask en tant que télécommande pour contrôler la voiture une fois les derniers éléments ajoutés.
- J'ai commencé à travailler sur l'utilisation de Flask pour gérer la voiture à distance.
  - J'ai crée une variable globale concernant la voiture (elle s'occupe de la connexion ainsi que du déplacement de la voiture)
    - J'ai eu une erreur me disant que lors que je tente d'accéder à la route créant l'objet concernant la voiture il n'était pas accessible alors que je l'ai définit en tant que variable globale.
    - Pour palier à ce problème, j'ai voulu implémenter le design pattern Singleton car j'avais besoin de récupérer la référence sur la classe afin de pouvoir exécuter les méthodes associées. Pour ce faire, je me suis basé sur l'exemple présent [ici](https://blog.finxter.com/how-to-create-a-singleton-in-python/).
    - La méthode `__init__` est remplacée par la méthode `__new__`. La méthode `__init__` est appellée lorsque l'objet doit être initialisé tandis que la méthode `__new__` est appelée lors de la création de l'objet.
    - Voici le code écrit pour le constructeur de mon objet `CarController` :

```python
def __new__(cls):
    if(cls.instance is None):
        cls.instance = super(CarController, cls).__new__(cls)
        cls.connection = get_connection_gatt(hub_mac=cls.MY_MOVEHUB_ADD)
        try:
            # The motors
            cls.movehub = MoveHub(cls.connection)
            cls.front_motor = Motor(cls.movehub, cls.movehub.PORT_A)
            cls.back_motor = Motor(cls.movehub, cls.movehub.PORT_B)
            cls.directionnal_motor = EncodedMotor(cls.movehub, cls.movehub.PORT_C)
        except:
            cls.movehub = None
            cls.front_motor = None
            cls.back_motor = None
            cls.directionnal_motor = None
    return cls.instance
```

- La raison pour laquelle on utilise `cls` à la place de `self` c'est parce que `self` doit être utilisé pour les méthodes d'instances tandis que `cls` est utilisé pour les méthodes de classes.
  - Par exemple, si une classe contient une méthode `move`, si nous utilisons des éléments propres à la classe dans ce cas on utilisera `self`.
  - Alors que pour si nous utilision une méthode tel que `__new__` ou `__init__`, étant donné qu'il s'agit de méthodes de classes, on utilisera `cls`.

```python
#Méthode de classe
__new__(cls)

# Méthode d'instance
move(self, motor_speed, angle_rotation)
```

#### Liens consultés

##### Python

- https://www.python.org/dev/peps/pep-0008/#function-and-method-arguments
- https://blog.finxter.com/how-to-create-a-singleton-in-python/
- https://www.geeksforgeeks.org/\_\_new__-in-python/

### 03.05.2021

- J'ai commencé par continué le code de la télécommande bluetooth avec Flask
  - J'ai eu un problème, lors de la tentative de déconnexion de l'appareil depuis un bouton présent sur le formulaire
  - lorsque j'accédais à la route depuis l'URL, cela déconnectait bien les appareils, cependant lorsque j'utilisais une redirection depuis le code, la déconnexion ne se faisait pas
    - C'est peut-être dû au fait qu'il doit passer au return quand même, même si un redirect est présent dans la méthode
    - En fait, le redirect c'est une fonction a retourner comme pour le `render_template`
  - Pour rendre l'application plus simple d'accès entre les différents routes j'ai regardé comment mettre en place une navbar
  - J'ai regardé [ce tutoriel](https://medium.com/analytics-vidhya/flask-how-create-a-responsive-navbar-146c7213df60) pour comprendre les navbar étaients écrites
    - Premièrement il faut télécharger Bootstrap pour Flask, les navbar pour Flask avec la commande suivante `sudo pip3 install flask_bootstrap && sudo pip3 install flask_nav`
    - Après avoir mis en place une interface plus user friendly avec Bootstrap ainsi qu'une Navbar
      - J'ai tenté de régler problème `dictionary changed size during iteration`. De ce que j'ai pu voir sur internet, il faudrait modifier le code parcourant une liste en utilisant ses clés comme suit : `for i in d.keys():` ou en forçant la création d'une liste `for i in list(d):`
    - Au fur et à mesure que j'avançais, j'ai tenté de voir si la déconnexion fonctionnait bien et en soit oui elle fonctionne, cependant lorsque l'on suit ce schéma ça ne recréé pas une connexion :

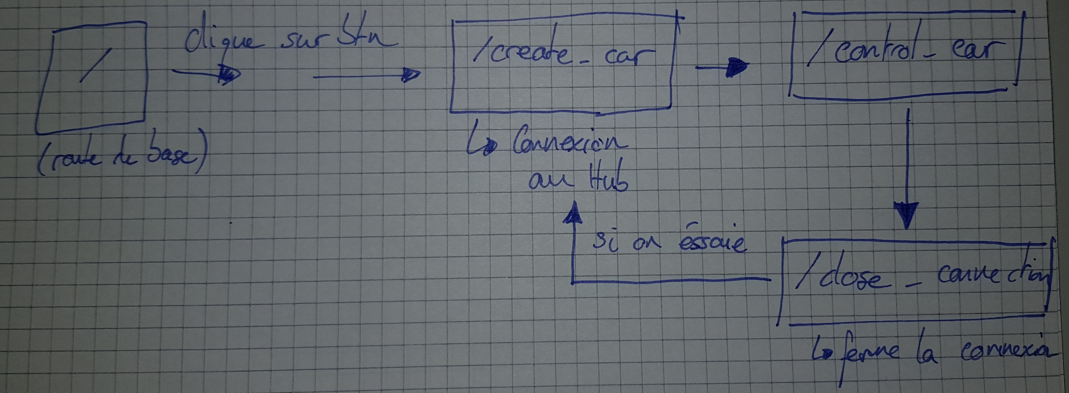
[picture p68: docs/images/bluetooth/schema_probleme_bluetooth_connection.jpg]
Schéma du problème avec la connexion bluetooth


- Je vais voir s'il n'y a pas moyen de clear le cache. J'ai lu cette [documentation](https://flask-caching.readthedocs.io/en/latest/index.html) j'ai par conséquent désactiver le cache car je pensais qu'il devait stocker une forme d'exécution des méthodes ou quelque chose dans le genre. Après l'avoir désactivé puis après avoir retesté le scénario présent sur le schéma ça n'a pas réglé le problème.
- J'ai passé le reste de l'après midi sur la tentative de compréhension de ce problème.
  - J'ai regardé dans les méthodes des objets fournis voir s'il y avait moyen d'avoir un callback sur la déconnexion pour s'assurer de la déconnexion

#### Liens consultés

##### Flask

- https://medium.com/analytics-vidhya/flask-how-create-a-responsive-navbar-146c7213df60
- https://medium.com/analytics-vidhya/flask-how-create-a-responsive-navbar-146c7213df60
- https://pypi.org/project/flask-navbar/
- https://flask-caching.readthedocs.io/en/latest/index.html

##### Jquery

- https://jquery.com/download/

##### Bootstrap

- https://getbootstrap.com/docs/4.0/components/buttons/

### 04.05.2021

- J'ai commencé la journée en m'informant sur la manière d'implémenter du JQuery avec Flask.
  - De ce que j'ai vu dans [cet article](https://codehandbook.org/python-flask-jquery-ajax-post/), vu qu'il s'agit de code Javascript on peut l'inclure dans nos fichiers comporant de l'HTML
  - Lors de la mise en place, j'ai eu une erreur HTTP : `405 Method Not Allowed` ce qui est normal car j'avais oublié d'inclure ceci : `methods=['POST']` dans la fonction de la route Flask
  - Ensuite j'ai eu une erreur 500 car lors de l'envoie de trop de données d'un coup, le Hub est surchargé et renvoie ce message : `AssertionError: Pending request MsgPortOutput({'payload': b'02110b240000009c647f03', 'needs_reply': True, 'port': 2, 'is_buffered': False, 'do_feedback': True, 'subcommand': 11, 'params': b'240000009c647f03'}) while trying to put MsgPortOutput({'payload': b'00110164', 'needs_reply': True, 'port': 0, 'is_buffered': False, 'do_feedback': True, 'subcommand': 1, 'params': b'64'})` car lors de l'envoie d'une commande il va bloquer un thread afin de s'en occuper. C'est pourquoi je pense qu'il ne faut pas que l'utilisateur surchage le changement de valeurs des sliders car je ne sais pas pour l'heure s'il est possible de palier à ce problème.
  - Voici la variable utilisée pour bloquer le thread.

```python
self._sync_lock = threading.Lock()
```

- J'ai refait le croquis du plan de la voiture après en avoir parlé à M. Bonvin. Voici ci-dessous la nouvelle version :

Croquis du plan de la voiture

- Je me suis ensuite mis à réaliser le plan de la voiture avec QCAD. Après avoir terminé les mesures des endroits susceptible de gêner donc qu'il faudra découper pour pouvoir les laisser passer, j'ai tenté de prendre une photo du LEGO 4x4 depuis le dessus de la manière la plus droite possible afin de pouvoir faire une preview de ou et comment la plaque en plastique se positionnera sur la voiture. La photo n'étant pas prise parfaitement, il faut prendre en compte la perspective qu'ajoute la focale de l'appareil.
- À noter que le schéma ci-dessous est à l'échelle 1:2

Plan de la plaque en plastique recouvrant la voiture permettant de disposer les différents capteurs

- Pour poursuivre, je me suis occupé de la plaque qui sera devant et derrière. Celle qui s'occupera du support des Flying-Fish :

Schéma de la plaque avant / arrière s'occupant du support des Flying-Fish

- Voici la version imprimée et testée avec une feuille (Il est incrusté dans la feuille, non pas juste poser dessus):

Schéma de la plaque avant / arrière s'occupant du support des Flying-Fish

- Voici ou la plaque avant et arrière devrait se située :

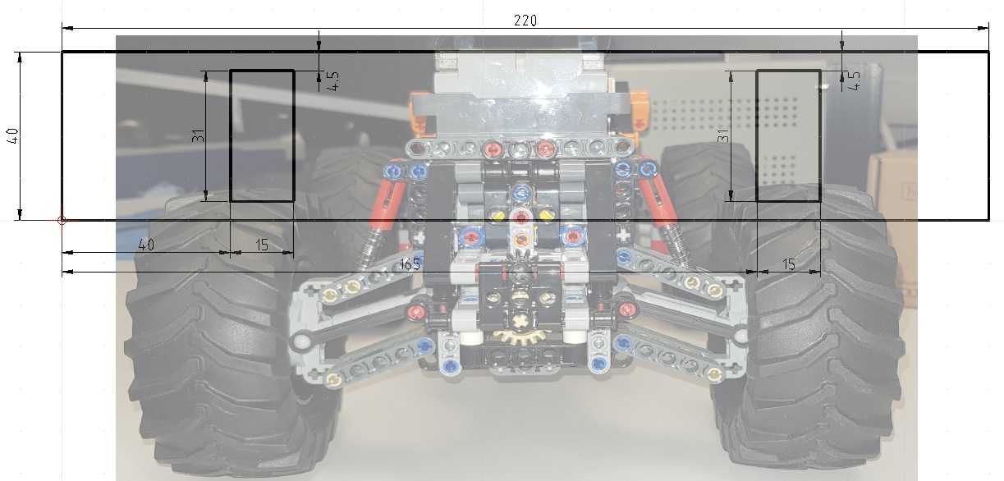
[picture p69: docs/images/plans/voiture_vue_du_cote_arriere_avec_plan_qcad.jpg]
Plan de la plaque avant / arrière s'occupant du support des Flying-Fish


- Je vais faire le plan de la voiture vue de côté car il y aura la caméra et le bright pi dessus.
- Voici où le Bright Pi et la caméra sera fixé sur le côté (dans le carré de 30 par 30) :

Plan de la plaque gauche / droite s'occupant du support des Bright Pi et caméras

- Voici ce comment la caméra et le Bright Pi seront disposés :

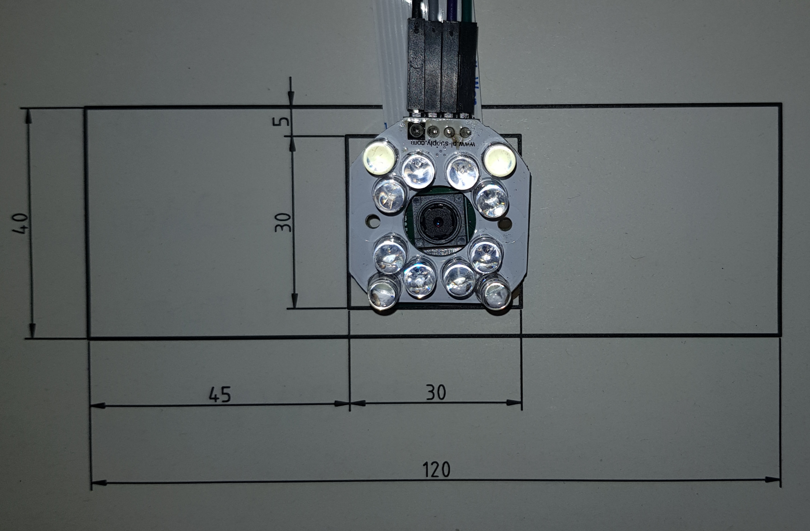
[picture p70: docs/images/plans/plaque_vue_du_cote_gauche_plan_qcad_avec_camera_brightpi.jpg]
Plan de la plaque gauche / droite s'occupant du support des Bright Pi et caméras


- De manière très schématique voici ce à quoi ça devrait ressemble (en omettant la plaque supérieur pour le moment) :

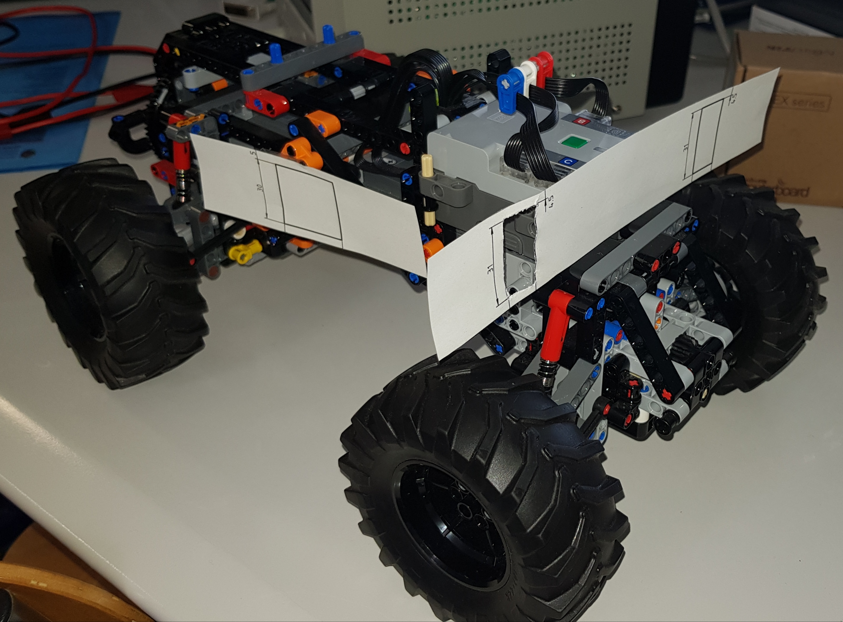
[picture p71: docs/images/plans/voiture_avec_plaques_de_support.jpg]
Voiture avec les "plaques" supportant les capteurs


#### Liens consultés

##### Python

- https://codehandbook.org/python-flask-jquery-ajax-post/

##### QCad

- https://qcad.org/doc/qcad/latest/reference/en/index.php?page=scripts/Draw/Image/doc/Image

##### LEGO Bluetooth

- https://lego.github.io/lego-ble-wireless-protocol-docs/index.html#document-index

### 05.05.2021

- J'ai commencé la journée par continué ma documentation technique.
- Par la suite, j'ai mis en place le système d'évenement avec le GPIO. Grâce à cela, j'ai pu lancer l'arrêt des moteurs lorsque le flying-fish ne détecte plus de sol :

```python
def get_grounded_state(self):
  """Will stop the motors if the ground isn't detected anymore
  """
  car = CarController()
  if GPIO.input(23):
      car.stop_moving()

[...]

if __name__ == '__main__':
[...]
    # Set the mode into Broadcom SOC channel
    # It allows to use GPIO number instead of pin number
    GPIO.setmode(GPIO.BCM)
    # Set the GPIO 23 into input mode
    GPIO.setup(23, GPIO.IN)
    # Add the event
    GPIO.add_event_detect(23, GPIO.RISING, callback=get_grounded_state, bouncetime=100)

[...]
```

#### Liens consultés

##### GPIO

- https://magpi.raspberrypi.org/articles/remote-control-gpio-raspberry-pi-gpio-zero
- https://raspberrypi.stackexchange.com/questions/12966/what-is-the-difference-between-board-and-bcm-for-gpio-pin-numbering

##### Pull-up resistor

- https://www.electronics-tutorials.ws/logic/pull-up-resistor.html

### 06.05.2021

- Aujourd'hui, j'avais envie de faire quelque chose d'autre que du code. C'est pourquoi j'ai décidé de commencer la journée sur l'élaboration du Poster qui doit être rendu le 14.05.2021
- J'ai d'abord commencé par réfléchir à comment j'allais mettre en avant les différents capteurs et technologies que je vais utiliser
- Pour le découpage j'ai pensé découpé l'affiche en 4 parties

  1. Titre
  2. Liste des capteurs + image de la voiture
  3. Technologies utilisées
  4. Nom / Classe / Travail diplôme

- Pour la voiture, je me suis dit que ce serait une bonne idée de reprendre ce schéma afin de décrire les capteurs que nous alions utiliser et quel sont leur champs d'actions :

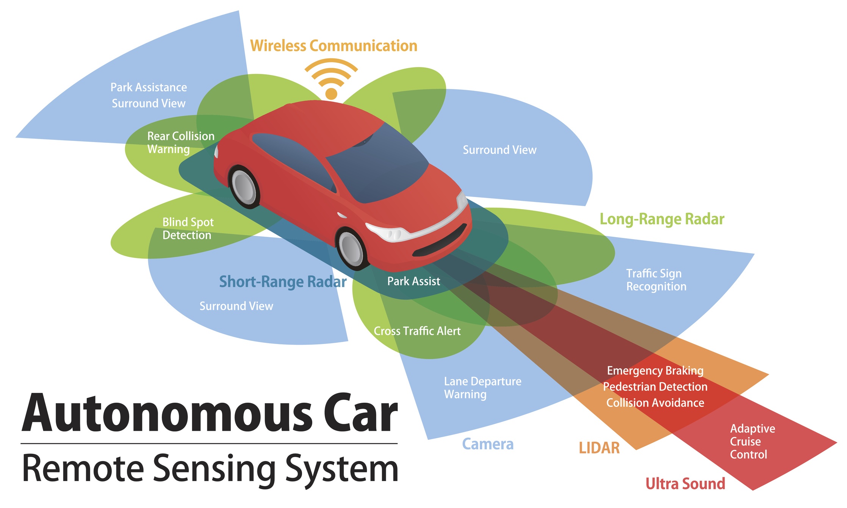
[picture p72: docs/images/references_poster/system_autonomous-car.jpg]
Plan d'une voiture autonome


- Pour la voiture, j'ai pris une photo du 4x4 que j'ai détourée puis sur laquelle j'ai ajouté un filtre permettant d'en faire un _flat design_ :

LEGO 4x4 Flat design

- Ensuite, j'ai ajouté les capteurs avec différents couleurs afin de les représenter différements chacun :

LEGO 4x4 Flat design avec les capteurs

- Le turquoise représente les caméras ainsi que les bright pi
- Le bleu sous les roues représente la détection du sol faite par le Flying-FIsh
- Le rouge pale représente la balayage du lidar

- Une fois les différents éléments assemblés voici le résultat :
  Poster du projet

- Pour avancer dans le projet, j'ai mis en place le routeur wifi
  - J'ai connecté le routeur puis j'ai été sur router.asus.com, l'interface d'accès au routeur.
  - Lors de l'arrivé sur le site, les logs pour se connecter sont user : admin, mdp : admin
    - Dès lors on peut modifier ces valeurs, pour ma part j'ai mis user : rtr_ackermanngue, mdp : cfpt18
    - J'ai aussi renommé le routeur en rtr_ackermanngue
- Une fois le routeur installé, j'ai mis en place un raspberry pi 0 wifi (en version desktop pour avoir une interface graphique sur le fonctionnement du streaming de la caméra)

#### Liens consultés

#####

### 07.05.2021

- J'ai mis en place un Raspberry Pi 0 Wifi pour avoir accès à la caméra depuis un autre Raspberry Pi
  - J'ai cherché un câble comme ceci (celui à gauche) :

Différents types de câble pour la caméra

- Ensuite sur le Raspberry Pi 0 Wifi, j'ai téléchargé OpenCV avec les commandes suivantes :
- `pip3 install opencv-python && sudo apt install libcblas-dev && sudo apt install libhdf5-dev && sudo apt install libhdf5-serial-dev && sudo apt install libatlas-base-dev && sudo apt install libjasper-dev && sudo apt install libqtgui4 && sudo apt install libqt4-test`
- `sudo pip3 install imutils`
- puis j'ai lancé le programme qui stream un flux de caméra sur un serveur Flask et je m'y suis connecté avec mon téléphone pour voir le flux.
- Dans le programme flask qui controlera la caméra, bright pi et le flying fish, j'ai commencé par ajouter le système de stream de la caméra.
  - Vu que je voulais une image à afficher lorsque l'utilisateur veut désactiver la caméra, pas qu'il y aie un simple rectangle noir.
  - Voici l'image faite :

Image affichée lorsque la caméra est éteinte

- J'ai aidé M. Borel à réaliser son poster.
- J'ai commencé à réaliser le système de flux de caméra sur le serveur
  - J'ai perdu 2 heures de mon temps car je voulais rentourner l'image à travers une route, comme pour le flux de la caméra qui est une _frame_ envoyée chaque milliseconde afin d'en faire une animation.
- J'ai remarqué une erreur étrange que je n'ai pas sû résoudre, il s'agit de la connexion SSH. Lorsque je tente de me connecter en SSH à mon Pi 0 Wifi, il me dit `the remote's host architecture isn't supported` alors que l'interface SSH est bien activée. Lorsque cette même carte SD est sur le Pi 4, je peux y accéder en SSH.
- J'ai terminé la journée en créant la page d'interface utilisateur.

#### Liens consultés

##### Raspberry

- https://projects.raspberrypi.org/en/projects/raspberry-pi-zero-time-lapse-cam/2

### 10.05.2021

- J'ai décidé de commencer la journée en réalisant un petit système avec le Remote GPIO me permettant d'intéragir depuis le Pi 4 avec les composants branchés au Pi 0 W
- La première chose que j'ai remarqué, c'est que le Bright Pi n'offre pas la possibilité d'être contrôlé en remote.
  - Ce que j'ai fais pour palier à ce soucis, c'est que je me suis dit qu'il faudrait un serveur flask qui tourne sur le Pi 0 WiFi. Son role est de géré les capteurs associés. Le contrôle sera fait à l'aide de route tel que : `/sensor/state` donc pour l'exemple du Bright Pi avant : `light/on`
- Avant de continuer, j'ai aidé M. Paulino à faire son poster.
- Pendant le développement du serveur Flask qui tourne sur le Pi 0 WiFi, je me suis aperçu que de temps en temps, j'ai cette erreur pour la caméra : `picamera.exc.PiCameraMMALError: Failed to enable connection: Out of resources`
  - J'ai tenté de reboot le Pi 0 pour voir si cela aurait pu résoudre le problème, cependant ça n'a pas changé le soucis
  - Quand je tentais de lancer, j'avais l'explorateur de fichier ouvert en fond, donc j'ai tenté de reboot puis lancer le serveur sans que rien d'autre ne soit activé mais toujours la même erreur.
  - Cependant lorsque je lance uniquement le code du stream de flask cela fonctionne sans soucis
  - À voir si le problème est uniquement un problème de ressource car si c'est le cas, il faudra switch sur de Pi 4
- Pour retourner les informations, étant donné que j'ai créé une classe qui stock les informations des capteurs, je l'ai convertie en JSON
  - J'ai eu des problèmes au début, du style que l'objet n'était pas convertissable en JSON etc... mais grâce à la méthode ci-dessous, j'ai pu résoudre ce problème :

```python
import json
class Sensor:
    """Class containing the values of the sensor
    """

    def __init__(cls, sensor_type, sensor_state):
        cls.type = sensor_type
        cls.state = sensor_state

    def convert_to_json(self):
        return json.dumps(self, default=lambda o: o.__dict__,
            sort_keys=True, indent=4)

```

- En continuant de coder, j'ai eu l'erreur suivante :
  - `UnboundLocalError: local variable 'brightpi_state' referenced before assignment`
  - Ce qui est étrange avec cette erreur, c'est que la variable `brightpi_state` est instancié globalement et lorsque je la print dans la console, tandis que lorsque j'en ai besoin dans la méthode gérant les capteurs, l'erreur surgit
  - Pour palier à ce problème, j'ai vu qu'il suffisait d'indiquer dans la méthode que les variable étaient global, comme suit :

```python
global brightpi_state
global camera_state
global flyingfish_state
```

#### Liens consultés

##### Python

- https://stackoverflow.com/questions/20941539/how-to-get-if-checkbox-is-checked-on-flask
- https://stackoverflow.com/questions/3768895/how-to-make-a-class-json-serializable#15538391
- https://stackoverflow.com/questions/3768895/how-to-make-a-class-json-serializable
- https://www.tutorialspoint.com/json-encoder-and-decoder-package-in-python
- https://pythonexamples.org/python-list-to-json/

### 11.05.2021

- J'ai commencé la journée en continuant de coder le serveur Flask présent sur le Raspberry Pi 0 WiFi.
- J'ai de nouveau eu l'erreur pour la caméra : `picamera.exc.PiCameraMMALError: Failed to enable connection: Out of resources`
  - J'ai regardé avec la commande `htop` l'utilisation du CPU
    - Lorsque je lance le programme qui gère les capteurs (bright pi, camera et flying-fish), lors de l'initialisation de la caméra, le CPU est à 100% et fait crash le programme
    - Cependant, lorsque je lance le programme gérant uniquement le stream de la caméra, la caméra s'initialise bien et fonctionne tout aussi bien mais la charge CPU est à 100% constamment
  - En attendant la disponibilité de M. Bonvin, j'ai aidé M. Paulino à réaliser son logo
  - Après discussion avec M. Bonvin, il m'a conseillé de réduire la résolution ainsi que le nombre d'images par seconde
    - La résolution de base était : 320 par 240
      - Que j'ai réduit à 160 par 128
    - Le nombre d'image par seconde étaient 32
      - Que j'ai réduit à 10
  - Étonnement j'ai toujours le même soucis
    - J'ai remarqué que même si j'avais fait ça :

```python
def __init__(self, flip = False, fps=10, res=(160, 128)):
        self.vs = PiVideoStream(resolution=res, framerate=fps).start()
        self.flip = flip
        print("cam init")
        time.sleep(2.0)
```

- Les valeurs resolution et framerate n'ont pas été changés.
  - Étant donné que `PiVideoStream` est définit dans la libraire `imutils` et par conséquent n'est pas modifiable, j'ai décidé de faire une copie de ce fichier pour tester si les valeurs changeait si j'utilisais une version local à mon serveur flask tandis que d'aller piocher dans la libraire elle même
    - Après avoir importer les éléments nécessaire du fichier, j'ai retenté en vérifiant à l'aide de print dans la console les différents valeurs passées en paramètres tel que la résolution ainsi que le nombre d'images par secondes
    - Hélas, j'ai toujours eu le problème `Out of resources`
  - En regardant sur internet, les gens parlaient du fait que c'est peut-être un problème de Thread donc il faudrait s'assurer que le thread ne soit pas modifié avant l'initialisation complète de la caméra
    - J'ai tenté de mettre un sleep de 10 secondes après la création de l'objet caméra :

```python
def __init__(self, flip = False, fps=10, res=(160, 128)):
        print("cam init")
        self.vs = PiVideoStream(resolution=res, framerate=fps).start()
        time.sleep(10.0)
        if self.vs != None:
            print("cam init done")
        self.flip = flip
```

- Mais cela n'a pas résolu le problème, je pense que le fait que la charge CPU arrive à 100% et que les autres capteurs soit utilisés que ça pose problème
- J'ai tenté les commandes présentes sur [cet article](https://forums.pimoroni.com/t/camera-not-working-mmal-mmal-vc-component-enable-failed-to-enable-component-enospc/3789/7) mais ça n'a rien changé, je pense vraiment que le problème de charge CPU est inévitable et il faudrait donc changer de modèle de Raspberry Pi

#### Liens consultés

##### Python

- https://www.pythontutorial.net/advanced-python/python-threading-lock/
- https://raspberrypi.stackexchange.com/questions/26829/picamera-not-working
- https://stackoverflow.com/questions/36283347/raspberry-pi-camera-out-of-resources
- https://github.com/waveform80/picamera/issues/488
- https://www.pyimagesearch.com/2016/08/29/common-errors-using-the-raspberry-pi-camera-module/
- https://forums.pimoroni.com/t/camera-not-working-mmal-mmal-vc-component-enable-failed-to-enable-component-enospc/3789/7

### 12.05.2021

- J'ai commencé ma journée en modifiant l'arboressence du dossier `flask_sensor_control` afin d'avoir un répertoir clean.
- La dernière chose à laquelle j'ai pensé pour palier au fait que la caméra est `Ouf of Resources` c'était de faire le test sur une version sans affichage graphique (OS du Raspberry Pi)
- J'ai mis un temps fou à mettre en place le Pi 0 car entre les temps d'installations, la configuration du raspberry ainsi que l'accès en SSH ça a pris un temps énorme juste pour mettre en place la Pi 0 avec l'OS lite pour faire le test de la caméra pour s'assurer des problèmes de charge CPU.
  - Pour le SSH, j'ai dû désactiver le login au lancement du Pi 0 car si je ne me suis pas connecté en tant que pi avec le mot de passe raspberry, je n'ai pas accès la connexion en SSH car d'après cette [issue github](https://github.com/microsoft/vscode-remote-release/issues/669) l'architecture n'est pas supportée par VSCode Remote SSH
  - Par conséquent, j'ai demandé à M. Moreno comment il a fait pour intéragir avec, ce à quoi il m'a répondu qu'il a utilisé Putty
  - Après avoir lancé le programme, j'ai toujours eu l'erreur concernant le `Out of Resources`
- J'ai aidé M. Fasler à faire son poster car M. Schmid n'a pas accepté la version qu'il avait proposé et il m'a donc demandé d'aider M. Fasler

#### Liens consultés

##### Python

- https://www.askpython.com/python-modules/daemon-threads-in-python

##### Raspberry Pi

- https://github.com/microsoft/vscode-remote-release/issues/669
- https://raspberrypi.stackexchange.com/questions/41032/i-changed-my-raspberry-pi-default-keyboard-settings-how-can-i-reset-this-change
- https://raspberrypi.stackexchange.com/questions/9826/couldnt-establish-raspberry-pi-ssh-connection

### 14.05.2021

- J'ai commencé la journée en remplaçant le Pi 0 par un Pi 4 pour voir si le problème de `Out of Resources` était toujours présent. Malheureusement oui, par contre j'ai remarqué que l'intialisation de la caméra se faisait 2 fois. Je me suis alors renseigné sur internet pour savoir pourquoi est-ce que le init se faisait deux fois. N'ayant rien trouvé à ce sujet, j'ai été demandé de l'aide à M. Beney. Il m'a montré les paramètres qu'il utilisait dans la méthode `app.run()` pour stream sa caméra, ses paramètres sont `app.run(host='0.0.0.0', debug=True, threaded=True, use_reloader=False)`. Grâce à lui j'ai pu comprendre quel était le problème, car de base `use_reloader`est à true, ce qui lors du lancement du serveur, le lançait 2 fois. Grâce à lui je n'ai plus de soucis de caméra `Out of Resources`, car la caméra se lançait 2 fois.
  - Vu que ce problème est réglé, je vais mettre en place de l'AJAX pour l'appuie sur les boutons qui vont changer l'état des capteurs sur l'autre raspberry
    - J'ai une erreur HTTP 405 lors de l'appel AJAX
- Après discussion avec M. Bonvin par rapport au poster, j'ai fait les modifications discutées. Voici la nouvelle version :
  Poster du projet
- Je l'ai ajouté à la documentation technique

#### Liens consultés

##### Python / Flask

- https://www.paramiko.org/installing.html
- https://stackoverflow.com/questions/3586106/perform-commands-over-ssh-with-python$
- https://developpaper.com/python-flash-solves-cross-domain-problems/
- https://stackoverflow.com/questions/28461001/python-flask-cors-issue#43019954
- https://flask-cors.readthedocs.io/en/latest/
- https://www.arundhaj.com/blog/definitive-guide-to-solve-cors-access-control-allow-origin-python-flask.html
- https://stackoverflow.com/questions/42681311/flask-access-control-allow-origin-for-multiple-urls

##### JQuery / Javascript

- https://stackoverflow.com/questions/1133770/how-to-convert-a-string-to-an-integer-in-javascript#1133814
- https://www.w3schools.com/jsref/jsref_substring.asp
- https://stackoverflow.com/questions/19304833/how-to-get-name-of-an-input-field-using-jquery#19304924
- https://stackoverflow.com/questions/2834350/get-checkbox-value-in-jquery
- https://developer.mozilla.org/en-US/docs/Web/JavaScript/Guide/Text_formatting
- https://learn.jquery.com/using-jquery-core/document-ready/
- https://stackoverflow.com/questions/3442322/jquery-checkbox-event-handling

### 17.05.2021

- J'ai commencé la journée par tenter de résoudre le problème que j'avais avec l'AJAX, le code HTTP que je recevais était le 405
  - Pour résoudre ce problème, j'ai ajouté à ma route le paramètre `methods=['POST', 'OPTIONS']` car de ce que j'ai vu sur internet, la première vérification de la page (pour les headers) se fait avec la méthode `OPTIONS`. Et j'ai ajouté entre la route et le nom de la fonction, la méthode `cross_origin()`

```python
@app.route('/<string:sensor>/<int:state>', methods=['POST', 'OPTIONS'])
@cross_origin()
def sensor_control(sensor=None, state=None):
  # code ...
```

- Ensuite, je me suis informé sur une manière d'afficher un stream en `HTML5` à la place d'utiliser un `iframe`.
  - J'ai commencé par regarder ce que fournissait la librairie [GStreamer](https://gstreamer.freedesktop.org/) mais j'ai pu voir dans le code du `Hello World`, qu'il permettait la transmission de flux depuis un fichier en entrée
  - Ensuite, je suis tombé sur [cet article](https://randomnerdtutorials.com/video-streaming-with-raspberry-pi-camera/), et j'ai pu voir qu'il utilisait une manière similaire à celle que j'utilise à présent, qui est d'encodé chaque frames de la caméra en `MJPEG` afin de change la source d'une balise `<img>`
  - J'ai continué à chercher et j'ai vu plusieurs fois apparaître le terme `RTMP` donc j'ai lu [cet article](https://streamhash.com/how-rtmp-helps-in-video-streaming/). En le lisant, j'ai pu lire qu'il avait plusieur avantages, tel que : sa capacité à précharger les paquets en temps réel ce qui permet une faible latence dans le flux vidéo, que la plupart des appareils supportent le RTMP
    - J'ai trouvé qu'il pouvait être pratique, cependant je ne l'utiliserai pas pour le moment car je trouve que j'ai pris pas mal de retard donc il faut que je continue à avancer sans me lancer dans une technologie inconnue, mais c'est une piste à garder pour sûr en cas d'améliorations
- C'est pourquoi je pense continuer avec mon histoire d'`<iframe>`
- Après avoir mis en place les iframes ainsi que la recharche automatique des canvas lors du changement d'état des caméras.
- J'ai remis la caméra ainsi que le bright pi sur un Pi 0 W pour refaire les tests
  - Tout fonctionne parfaitement
- Après avoir fait la vérification pour le Pi 0 Wifi, j'ai décidé de copier le contenue de la carte SD afin de pouvoir installer l'exacte même configuration pour chaque Pi 0 Wifi
  - Pour la copie, j'ai utilisé `Win32 Disk Imager`

Interface du programme Win32 Disk Imager

- Maintenant que l'interface utilisateur, le tableau de bord est terminé à 70%, car il manque encore le changement d'état pour le lidar, j'ai décidé de me pencher sur le problème du lidar qui output les données dans la console. Je vais tenter de faire en sorte que les données du lidar soit retournées soit dans le code, soit par une route en JSON
- J'ai commencé à regarder le code affichant les distances pour chaque angles afin de pouvoir le modifier

#### Liens consultés

##### Streaming

- https://gstreamer.freedesktop.org/
- https://randomnerdtutorials.com/video-streaming-with-raspberry-pi-camera/
- https://streamhash.com/how-rtmp-helps-in-video-streaming/

##### Javascript / JQuery / HTML

- https://www.w3schools.com/tags/tag_iframe.asp
- https://stackoverflow.com/questions/13477451/can-i-force-a-hard-refresh-on-an-iframe-with-javascript
- https://stackoverflow.com/questions/48852888/iframe-contentwindow-undefined-even-after-load-function
- https://stackoverflow.com/questions/23711448/iframe-contentwindow-is-undefined-when-use-window-framesname-to-access
- https://stackoverflow.com/questions/4249809/reload-an-iframe-with-jquery

### 18.05.2021

- J'ai commencé la journée par déballer le baterie portable `XB304 Titan` puis mis à charger.
- Ensuite, j'ai modifié le code présent dans le fichier `simple_grabber.cpp` afin qu'il retourne un tableau de 360 valeurs, pour lesquelles chaque index est un angle avec la distance d'un objet.
  - Premier problème que j'ai rencontré, était qu'étant donné que le grabber récupére les distances avec des valeurs à virgules comme suit :

```
...

   theta: 210.31 Dist: 00875.00
   theta: 211.12 Dist: 00874.00
   theta: 211.83 Dist: 00876.00
   theta: 213.91 Dist: 00000.00
   theta: 214.59 Dist: 00000.00
   theta: 214.61 Dist: 00872.00
   theta: 215.28 Dist: 00000.00

...
```

- On peut remarquer que des fois vu qu'il s'agit d'un angle non plein, des fois les valeurs que je stock pour des angles pleines sont négatives car ils n'ont pas de valeur vu que chaque scan va être effectué avec un incrément de 0.7 pour les valeurs d'angles :

```
...

ANGLE : 210  DISTANCE : 875.000000 [mm]
ANGLE : 211  DISTANCE : 874.000000 [mm]
ANGLE : 212  DISTANCE : -0.431641 [mm]
ANGLE : 213  DISTANCE : 0.000000 [mm]
ANGLE : 214  DISTANCE : 0.000000 [mm]
ANGLE : 215  DISTANCE : 0.000000 [mm]

...
```

- J'ai tenté diverse méthode pour palier à ce problème mais aucune ne fut concluantes car je m'y prennais mal.
  - Après discussion avec M. Bonvin sur le sujet, il m'a dit de récupérer les valeurs, les stockées, refaire le scan puis avec les anciennes valeurs faire une moyenne, d'utiliser un seuil pour les valeurs qui ne m'intéressent pas, par exemple les éléments à plus d'1 mètre (1000 [mm]) et de mettre à 0 les valeurs négatives.
  - Pour m'aider sur la manière de dessiné le radar, il m'a montré rapidement que c'était facile de le faire à l'aide de trigonométrie :

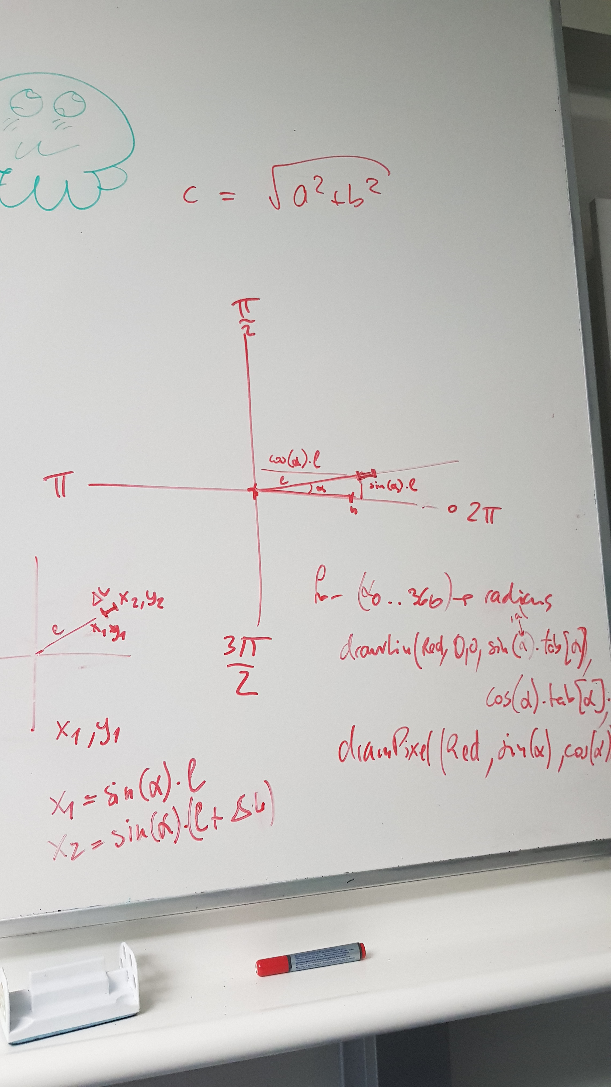
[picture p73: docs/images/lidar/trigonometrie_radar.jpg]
Schéma explicatif sur la manière de connaître les coordonnées du point à placer


#### Liens consultés

##### C++

- https://www.geeksforgeeks.org/list-cpp-stl/
- https://www.geeksforgeeks.org/listpush_front-listpush_back-c-stl/
- https://www.interviewsansar.com/cpp-map-insert/
- https://www.cplusplus.com/reference/list/list/insert/
- https://www.cplusplus.com/doc/tutorial/arrays/
- https://www.tutorialspoint.com/how-do-i-find-the-length-of-an-array-in-c-cplusplus
- https://stackoverflow.com/questions/51609816/return-float-array-from-a-function-c
- https://www.programiz.com/cpp-programming/library-function/cmath/round
- https://askubuntu.com/questions/527665/undefined-reference-to-symbol-expglibc-2-2-5
- https://en.cppreference.com/w/cpp/numeric/math/round
- https://stackoverflow.com/questions/19901934/libpthread-so-0-error-adding-symbols-dso-missing-from-command-line

### 19.05.2021

- J'ai commencé la journée en continuant la modification du code `C++`
  - J'ai d'abord récupérer les valeurs d'angle plusieurs fois afin d'éffectuer un lissage à l'aide de moyennes
    - J'ai eu une erreur avec Numpy `numpy.core.multiarray failed to import`, pour régler le problème, j'ai dû le mettre à jour avec la commande : `pip install -U numpy`
  - Ensuite, j'ai créé un fichier lançant le projet et récupérant les données présentes dans la console
    - J'ai effectué de traitement de texte pour récupérer les données
  - Ensuite, j'ai été me documenter sur la libraire `Matplotlib`
    - J'ai d'abord eu une erreur avec la plugin utilisé pour le rendu `PyQT5`, pour régler le soucis, j'ai dû installer les packages avec la commande suivante : `sudo apt install pyqt5-dev-tools pyqt5-dev`
    - J'ai pris le code d'exemple présent [ici](https://matplotlib.org/stable/gallery/pie_and_polar_charts/polar_scatter.html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)
    - Mais j'avais un bug que je ne comprennais pas, ce dernier m'affichait une fenêtre vide, tel que je voyais à travers la fenêtre qui était sensé affiché le graphique.
    - J'ai demandé de l'aide à M. Burgener, et il m'a dit d'utiliser `plt.NOM_DE_LA_MÉTHODE` car dans le code d'exemple, il utilise un objet `figure()`
    - Voici le rendu du graphique généré par le code d'exemple :

Affichage du graphique généré par le code d'exemple

#### Liens consultés

##### Python

- https://www.digitalocean.com/community/tutorials/how-to-use-subprocess-to-run-external-programs-in-python-3
- https://docs.python.org/3/library/subprocess.html#subprocess.CalledProcessError.stderr
- https://matplotlib.org/stable/gallery/pie_and_polar_charts/polar_scatter.html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
- https://matplotlib.org/stable/tutorials/introductory/usage.html#sphx-glr-tutorials-introductory-usage-py
- https://pythonguides.com/python-degrees-to-radians/

##### C++

- https://stackoverflow.com/questions/9951678/initializing-an-empty-array-in-c#9951694
- https://www.cplusplus.com/forum/beginner/106567/

### 20.05.2021

- J'ai commencé la journée en continuant de travailler sur l'affichage des éléments reçu par le Lidar
  - Au début j'ai eu un problème avec les array numpy car en reprennant le code d'exemple, `np.random.rand(N)` retourne un tableau comme suit `[ 2.304320 3.304320 2.304320 ... ]` et lorsque je remplaçait le tableau généré alétoirement par les valeurs que je récupérais du Lidar, j'avais cette erreur `ValueError: x and y must be the same size`
  -
  - mais je n'arrivais pas à comprendre pourquoi la fonction qui va mettre en place les valeurs sur le graphique me retournait l'erreur
  - En creusant un peu, j'ai vu que je donnais en X un tableau avec les valeurs X et Y donc j'ai pu me rendre compte qu'en fait la valeur `theta` du code d'exemple représentait la variable x mais pas en terme de position mais en terme d'angles et que la variable `r` représentait la valeur Y à placer sur le graphique

```python

import numpy as np
import matplotlib.pyplot as plt

# Fixing random state for reproducibility
np.random.seed(19680801)

# Compute areas and colors
N = 150
r = 2 * np.random.rand(N)
theta = 2 * np.pi * np.random.rand(N)
area = 200 * r**2
colors = theta

fig = plt.figure()
ax = fig.add_subplot(projection='polar')
c = ax.scatter(theta, r, c=colors, s=area, cmap='hsv', alpha=0.75)

```

- Je m'en suis rendu compte car en plus d'avoir vu qu'il s'agissait des paramètres x et y dans la documentation, je trouvais vraiment étrange qu'il y aie des valeurs négatives en terme de distance vu que dans le programme `C++` j'ai fais un tri des données.

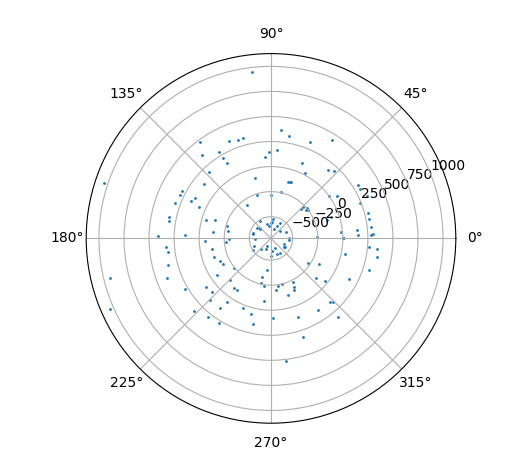
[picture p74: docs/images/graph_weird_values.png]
Affichage du graphique avec des valeurs étranges généré


```python
r = 1500
for angle, distance in rows:
    data.append((
        math.sin(math.radians(angle) * distance),
        math.cos(math.radians(angle) * distance)))

plt.scatter(data, r, c=colors, s=area, cmap="hsv", alpha=0.75)

```

- Vu que j'utilisais les calculs présent sur le tableau pour trouver les coordonées à afficher sur le graphique, puis je me suis dit qu'en fait, le `theta` représentait un angle en radian, vu que dans l'exemple, il s'agit d'une valeur multipliéé par 2 pi.

- Et par conséquent que `r` était la valeur à placer sur le graphique, donc j'ai itéré sur les les lignes du tableau de données splité en [`tuple`](https://www.w3schools.com/python/python_tuples.asp) pour uniquement donner l'angle en radian avec sa valeur dans des tableau différents pour X et Y :

```python
data_x = []
data_y = []
for angle, distance in rows:
    data_x.append(math.radians(angle))
    data_y.append(distance)

plt.subplot(projection="polar")
plt.scatter(data_x, data_y, s=1)

```

- Et voici le résultat :

Affichage du graphique généré avec de bonnes valeurs

- J'ai ensuite regardé comment on pouvait faire en sorte que plus le point est loin du 0 plus il est vert et à l'inverse plus il est proche plus il est rouge.
  - Je suis tombé sur [cet exemple](https://matplotlib.org/stable/gallery/color/custom_cmap.html), il m'a permit très rapidement d'implémenter ce dont j'avais besoin. Voici le résultat :

Affichage du graphique généré avec les couleurs prévenant le danger par rapport à un obstacle

```python
# Create the colors I need, values between 0 and 1 for (r, g, b)
colors = [(1, 0.2, 0.3), (1, 0.8, 0), (0.1, 0.5, 0.1)]  # near -> mid -> far
cmap_name = "distance_warning"
cmap = matplotlib.colors.LinearSegmentedColormap.from_list(cmap_name, colors)
```

- Ensuite, j'ai regardé comment faire en sorte de rafraichir le programme afin qu'il sorte 1 graphique toutes les 2-3 secondes environ, car pour lisser les données je lance 10 scans à la suite donc ce processus est répété plusieurs fois, à voir si on peut potentiellement rendre ceci continue
  - J'ai lancé plusieurs fois le programme pour faire ceci, mais je me suis rendu compte que c'était vraiment pas performant alors j'ai été modifié le code `C++` pour pouvoir accès aux données en temps réel.

#### Liens consultés

##### Python

- https://numpy.org/doc/stable/reference/random/generated/numpy.random.rand.html#numpy.random.rand
- https://matplotlib.org/stable/gallery/pie_and_polar_charts/polar_scatter.html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
- https://www.geeksforgeeks.org/how-to-convert-float-to-int-in-python/
- https://www.geeksforgeeks.org/convert-string-to-float-in-python/
- https://stackoverflow.com/questions/41659535/valueerror-x-and-y-must-be-the-same-size#41661392
- https://matplotlib.org/stable/api/_as_gen/matplotlib.colors.LinearSegmentedColormap.html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
- https://matplotlib.org/stable/gallery/color/custom_cmap.html

### 21.05.2021

- J'ai continué le programme affichant les données du Lidar en temps réel
  - Au début j'ai eu une erreur qui me disait que je ne pouvais pas convertir la valeur string float, mais j'ai vite compris lorsque j'affichais la données qu'elle avait un `\n`, une fois retiré cela fonctionnait
  - J'ai tenté de changer de manière d'utiliser mon `subprocess` avec un Popen car je me suis dit qu'étant donné que la console (pour le programme `C++`) retourne du contenu en temps réel que si je lisais ligne par ligne que ça pourrait être une bonne idée alors j'ai tenté la manière de faire [ici présente](https://www.endpoint.com/blog/2015/01/28/getting-realtime-output-using-python) mais ça n'a pas fonctionné, au contraire ça ne récupérais rien
  - J'ai donc regardé comment rendre mon code asynchrone en lisant [cet article](https://stackoverflow.com/questions/803265/getting-realtime-output-using-subprocess) car la méthode que j'utilisais de lire le contenu que retourne le code `C++` le faisait en continue et cela était bloquant
  - J'ai commencé à mettre en place le code ici présent :

```python

import asyncio
from asyncio.subprocess import PIPE
from asyncio import create_subprocess_exec

async def _read_stream(stream, callback):
    while True:
        line = await stream.readline()
        if line:
            callback(line)
        else:
            break

async def run(command):
    process = await create_subprocess_exec(
        *command, stdout=PIPE, stderr=PIPE
    )

    await asyncio.wait(
        [
            _read_stream(
                process.stdout,
                lambda x: print(
                    "STDOUT: {}".format(x.decode("UTF8"))
                ),
            ),
            _read_stream(
                process.stderr,
                lambda x: print(
                    "STDERR: {}".format(x.decode("UTF8"))
                ),
            ),
        ]
    )

    await process.wait()

async def main():
    await run("docker build -t my-docker-image:latest .")

if __name__ == "__main__":
    loop = asyncio.get_event_loop()
    loop.run_until_complete(main())
```

- En implémentant le code, j'ai eu une autre erreur `cannot unpack non-iterable float`. Je me suis rendu compte par la suite que j'utilisais encore le tuple pour faire le parcours de la boucle pour les placer sur le graphique

```python

for angle, distance in rows:
    data_x.append(math.radians(angle))
    data_y.append(distance)

```

- j'utilise donc array simple :

```python

for distance in rows:
        data_x.append(math.radians(angle))
        data_y.append(distance)
        angle += 1

```

- Donc vu que pour le code asynchrone lis le contenu de la console en temps réel ligne par ligne, j'ai dû le modifié ainsi :

```python

async def _read_stream(stream, callback):
    while True:
        line = await stream.readline()
        if line:
            callback(line.split(b','))
        else:
            break

async def run(should_scan):
    command = ("./simple_grabber /dev/ttyUSB0 " + should_scan).split()
    process = await create_subprocess_exec(*command, stdout=PIPE, stderr=PIPE)
    await asyncio.wait(
        [
            _read_stream(
                process.stdout,
                # x will be the line
                lambda x: {
                    get_radar_data(x)
                }
            )
        ]
    )
    await process.wait()

    async def main(should_scan):
    await run(should_scan)

if __name__ == "__main__":

time_between_scans = 6
run_scan = True
# value "hardcoded" in order to preshot the Flask use case
should_scan = "1"
try:
    loop = asyncio.get_event_loop()
    loop.run_until_complete(main(should_scan))
except KeyboardInterrupt:
    loop = asyncio.get_event_loop()
    loop.run_until_complete(main("0"))
```

- Pour avoir accès de manière constante au tableau de données, j'en ai fait une variable global `rows`
- On peut donc avoir accès en quasi temps réel au scanner :

Affichage des données en temps réel

- Vu que dans l'interface utilisateur, il y a un endroit ou le radar doit être activé j'ai commencer à implémenter le programme python que j'ai fait

#### Liens consultés

##### Matplotlib

- https://stackoverflow.com/questions/11874767/how-do-i-plot-in-real-time-in-a-while-loop-using-matplotlib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
- https://matplotlib.org/stable/gallery/color/custom_cmap.html
- https://matplotlib.org/stable/api/_as_gen/matplotlib.colors.LinearSegmentedColormap.html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
- https://stackoverflow.com/questions/8213522/when-to-use-cla-clf-or-close-for-clearing-a-plot-in-matplotlib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
- https://www.pythonpool.com/clear-plot-matplotlib/

##### Python

- https://stackoverflow.com/questions/15318208/capture-control-c-in-python#15319004
- https://stackoverflow.com/questions/803265/getting-realtime-output-using-subprocess
- https://www.endpoint.com/blog/2015/01/28/getting-realtime-output-using-python
- https://docs.python.org/3.8/library/codecs.html#codecs.StreamReader.readline
- https://stackoverflow.com/questions/19243020/in-python-get-the-output-of-system-command-as-a-string#19243080
- https://www.delftstack.com/howto/python/how-to-read-input-from-stdin-in-python/
- https://www.programcreek.com/python/example/82053/asyncio.wait
- https://stackoverflow.com/questions/4056768/how-to-declare-array-of-zeros-in-python-or-an-array-of-a-certain-size
- https://stackoverflow.com/questions/54273077/cannot-unpack-non-iterable-numpy-float64-object-python3-opencv
- https://java2blog.com/typeerror-a-bytes-like-object-is-required-not-str/
- https://stackoverflow.com/questions/62608482/getting-an-error-like-typeerror-cannot-unpack-non-iterable-float-object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
- https://www.geeksforgeeks.org/python-convert-float-string-list-to-float-values/
- https://www.geeksforgeeks.org/global-local-variables-python/
- https://stackoverflow.com/questions/12665994/function-not-changing-global-variable

##### C++

- https://www.tutorialspoint.com/how-can-i-clear-console-using-cplusplus

### 24.05.2021

- J'ai continué la mise en place du coder pour le lidar / radar dans le serveur flask mais la première erreur que j'ai eu me disait ça : `RuntimeError: There is no current event loop in thread 'Thread-4'.`, le [premier lien trouvé](https://stackoverflow.com/questions/46727787/runtimeerror-there-is-no-current-event-loop-in-thread-in-async-apscheduler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) m'a permis de résoudre ce problème.

* Ensuite, j'ai eu cette erreur : `RuntimeError: Cannot add child handler, the child watcher does not have a loop attached`, en cherchant je suis tombé sur [cet article](https://www.programcreek.com/python/example/125582/asyncio.get_child_watcher), et cet article parlait des `child_watcher`, j'ai donc implémenter la ligne : `asyncio.get_child_watcher().attach_loop(loop)` et ça a supprimé l'erreur précédente.
* Cependant, maintenant lorsque j'active et désactive le lidar, voici le message que j'ai : `RuntimeError: This event loop is already running` donc j'ai été cherché comment résoudre ce problème et j'ai vu que tout simplement cette manière de faire était la plus adaptée :

```python
try:
    loop = asyncio.get_running_loop()
except RuntimeError:  # no event loop running:
    loop = asyncio.new_event_loop()
    return loop.run_until_complete(main(state))
```

- Ensuite, j'ai tenté d'importer le png du radar sur la tableau de bord pour voir si vu que le fichier originel changeait, je me suis dit que potentiellement ça changerait le contenu de l'image en quasi temps réel mais hélas non, donc je vais devoir tenter de rendre l'image "streamable", certainement en reprennant le concept pour le streaming de la caméra avec flask

* En attendant, j'ai décidé de regarder si on pouvait rendre la taille du graphique stable car pour l'instant il s'adapte aux données fournies donc au lieux de toujours avec 2000 en valeurs maximale, des fois il affiches des plus petites :

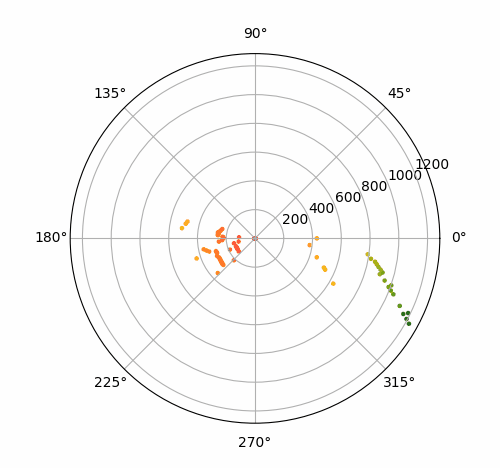
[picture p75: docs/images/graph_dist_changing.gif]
Affichage des données en temps réel mais avec la taille du radar qui change


- Je suis tombé sur [ce site](https://www.tutorialspoint.com/matplotlib/matplotlib_setting_limits.htm) m'explicant que l'on pouvait forcé une valeur maximale avec la méthode : `ylim()`

#### Liens consultés

##### Python

- https://stackoverflow.com/questions/46727787/runtimeerror-there-is-no-current-event-loop-in-thread-in-async-apscheduler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

* https://www.programcreek.com/python/example/125582/asyncio.get_child_watcher
* https://izziswift.com/runtimeerror-this-event-loop-is-already-running-in-python/
* https://www.tutorialspoint.com/matplotlib/matplotlib_setting_limits.htm

### 25.05.2021

- J'ai commencé la journée en tentant de mettre en place le système de streaming que j'avais utilisé pour la caméra, mais je ne comprennais pas pourquoi ça faisait crash le programme
- J'ai donc tenté d'afficher l'image du scanner avec OpenCV mais j'ai eu cette erreur : `error: (-2:Unspecified error) Can't initialize GTK backend in function 'cvInitSystem'` mais c'est parce que je lançais le code depuis le SSH et non depuis le raspberry pi, car dès que je l'ai lancé depuis le raspberry, j'ai eu la fenêtre qui s'affichait mais instantanément après j'ai eu cette erreur : `UserWarning: Starting a Matplotlib GUI outside of the main thread will likely fail. plt.title("Lidar : ") WARNING: QApplication was not created in the main() thread. qt5ct: using qt5ct plugin /usr/local/lib/python3.7/dist-packages/matplotlib/backends/backend_qt5.py:119: Warning: g_main_context_push_thread_default: assertion 'acquired_context' failed`
- Cette erreur survenait car je tentais d'afficher l'image avec la méthode d'opencv : `cv2.imshow(img)`, j'utilisais ça pour voir si l'image se mettait bien à jour et la réponse est que oui donc je l'ai enlevé afin d'éviter cette erreur sauf que quand je tente de prévisualiser l'image sur la route associée : `/video_feed/<int:state>`, l'image n'est pas transmise.
- Voici la manière que j'utilise pour faire le stream :

```python

def lidar_stream(state=None):
    # get the picture
    radar = cv2.imread("static/img/test.png")
    # convert it to bytes
    radar_bytes = radar.tobytes()
    while state == MODE_ON:
        # async encoding
        yield (b'--frame\r\n'
               b'Content-Type: image/png\r\n\r\n' + radar_bytes + b'\r\n\r\n')

@app.route("/video_feed/<int:state>")
def video_feed(state=None):
    # prepare the response to send
    return Response(lidar_stream(state), mimetype='multipart/x-mixed-replace; boundary=frame')

```

- En réfléchissant, je me suis demandé si c'était utile d'encoder l'image en png vu que je récupérais une image en png, mais je me suis dit qu'il fallait tenter étant donné que ça ne marchait pas. Après avoir rajouté cette ligne : `radar = cv2.imencode(".png", radar)[1]`, l'image s'est affiché.
- Mais elle ne s'actualisait pas, donc j'ai mis le code qui va chercher l'image et l'encoder dans la boucle, et ça a marché, cependant j'ai des erreurs qui surviennent de temps en temps lors du réaffichage de l'image mais en soit ça fonctionne
- J'ai remarqué que lorsque je relançais le scanner pour la seconde fois depuis l'interface utilisateur, j'avais des problèmes de données (il semblerait) :

Affichage des données en temps réel mais avec des données étranges

- L'une des erreurs que j'ai eu me disait : `libpng error: Read Error`, en lisant [cet article](https://stackoverflow.com/questions/8827016/matplotlib-savefig-in-jpeg-format), j'ai pu voir que les gens disaient d'utiliser un format JPEG pour les images avec la méthode `plt.savefig("static/img/test.jpg", "JPEG")`, si on spécifie pas le `JPEG` en paramètre, on a l'erreur suivante : `Premature end of JPEG file` et ça a réglé le soucis
- Peu après, je me suis rendu compte que j'ai toujours des soucis, il me dit que cette méthode requiert 2 arguments et que je lui en fournit 3 : `plt.savefig("static/img/test.jpg", "JPEG")`, n'ayant pas compris pourquoi il me disait ça alors que ça fonctionnait auparavant, j'ai tenté utiliser cette manière de faire, présente dans l'article.

```python
import Image
import matplotlib.pyplot as plt

plt.savefig('testplot.png')
Image.open('testplot.png').save('testplot.jpg','JPEG')

```

- Ceci a résolu mes soucis

#### Liens consultés

##### Python

- https://stackoverflow.com/questions/59809381/capture-video-stream-flask#62530004
- https://flask.palletsprojects.com/en/1.1.x/patterns/streaming/
- https://stackoverflow.com/questions/44663347/python-opencv-reading-the-image-file-name#44663464
- https://stackoverflow.com/questions/54417742/werkzeug-routing-builderror-could-not-build-url-for-endpoint-success-did-you
- https://pythonexamples.org/python-opencv-imshow/
- https://www.programiz.com/python-programming/methods/built-in/bytes
- https://www.pyimagesearch.com/2019/09/02/opencv-stream-video-to-web-browser-html-page/
- https://stackoverflow.com/questions/8827016/matplotlib-savefig-in-jpeg-format
- https://stackoverflow.com/questions/46683264/libpng-error-read-error-by-using-open-cv-imread
- https://github.com/rytilahti/python-miio/issues/201
- https://he-arc.github.io/livre-python/pillow/index.html
- https://stackoverflow.com/questions/63433777/savefig-takes-2-positional-arguments-but-3-were-given-how-to-pass-only-the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

##### HTML / Jquery

- https://stackoverflow.com/questions/4390627/whats-the-correct-way-to-set-src-attribute-in-jquery#4390635
- https://developer.mozilla.org/en-US/docs/Web/HTTP/Basics_of_HTTP/MIME_Types?retiredLocale=ar
- https://developpaper.com/using-multipart-x-mixed-replace-to-realize-http-real-time-video-streaming/

### 26.05.2021

- Aujourd'hui j'ai commencé à faire les premiers branchement pour la voiture étant donné que la voiture
  - En un premier temps, j'ai commencé par brancher les flying-fish puis le phare avant mais je me suis rendu compte que les rapsberry pi ne se connectaient pas au réseau donc j'ai été vérifié l'activation du WiFi sur les Raspberry Pi
  - J'ai branché les capteurs avant, et je me suis rendu compte que le flying-fish avant gauche ne fonctionnait pas. Il est bien alimenté, mais quand je change la valeur du potentiomètre, rien ne se passe et la led qui indique qu'un élément est détecté ne s'allume pas
  - Quand j'ai vérifié la carte SD pour le Pi 0, j'ai vu un problème apparaître `Kernel panic-not syncing: VFS: unable to mount root fs on unknown- block(179,6)`, j'ai tenté de faire ce que [cet article](https://raspberrypi.stackexchange.com/questions/40854/kernel-panic-not-syncing-vfs-unable-to-mount-root-fs-on-unknown-block179-6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) propose mais ça n'a pas fonctionné.
    - J'ai regardé les différentes cartes SD
      - 1 fonctionne mais les 2 autres (celle que j'avais copiées) donc il va falloir que je refasse l'image des carte SD afin qu'elle soit fonctionnelles
  - J'ai tenté de me connecter à distance aux raspberry pi mais le problème que j'ai eu avec le Pi 4 fu ça : `no buffer space available` et en voulant chercher sur internet j'ai remarqué que je n'avais plus accès à internet (depuis mon poste de travail), j'ai tenté de ping google, et ça a fonctionné donc pour potentiellement enlever les erreurs, j'ai redémarré mon poste
  - Ensuite, j'ai fait le test des différents élément suivant :
    - La connexion à la voiture, ça fonctionne, mais j'ai toujours des problèmes avec la connexion bluetooth. De temps en temps, la connexion ne se fait pas ou je ne sais pas trop quoi. Vu que j'utilise une singleton pour la connexion à la voiture, je vais tenter d'utiliser une variable global car j'ai l'impression que le singelton fait tout crash
    - La gestion des capteurs à distance
      - La caméra, fonctionne parfaitement
      - Le lidar, fonctionne très bien sauf que le graphique du radar des fois plante et ne permet plus de continuer le stream du graphique
      - Le bright pi, fonctionne parfaitement
  - J'ai fait cette image pour pouvoir avoir un aperçu de ce à quoi ressemble la voiture après avoir travaillé dessus :

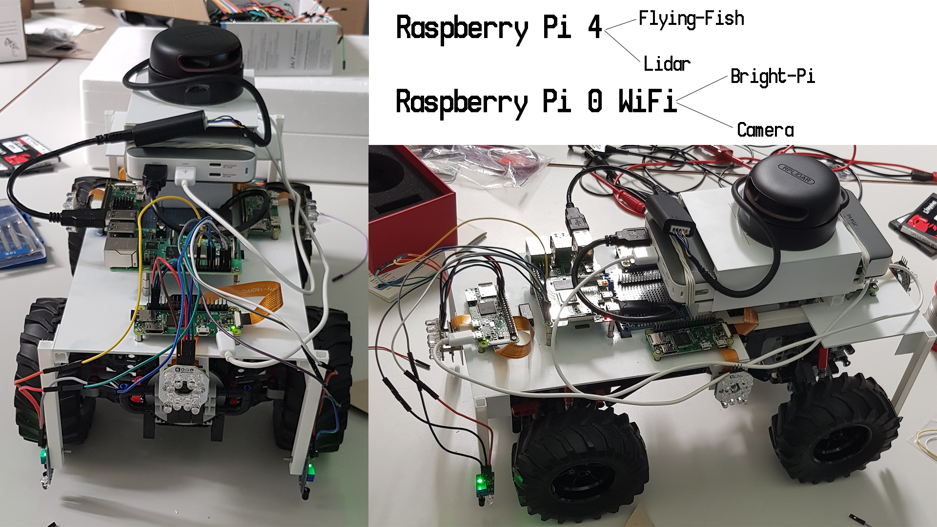
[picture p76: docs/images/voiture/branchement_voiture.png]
Branchement de la voiture


- J'ai fait une petite démonstration à mes camarades de classe ainsi qu'à messieurs Aigroz et Garcia

* Ensuite, j'ai modifié le code pour pouvoir avoir accès à l'output que génère le flying-fish, dans mon précédent code j'utilise cette manière de faire :

```python
 def get_grounded_state(self):
    """Will stop the motors if the ground isn't detected anymore"""
    car = CarController()
    if GPIO.input(23):
        car.stop_moving()
```

- Donc j'ai changé le code de la sorte :

```python
GPIO_FLYINGFISH_FRONT = 17

def get_grounded_state(self):
    """Will stop the motors if the ground isn't detected anymore"""
    car = CarController()
    if GPIO.input(GPIO_FLYINGFISH_FRONT):
        car.stop_moving()

...

# Reverse the result because it returns True if there isn't a ground below
    grounded = not GPIO.input(GPIO_FLYINGFISH_FRONT)

...

# Set the GPIO GPIO_FLYINGFISH_FRONT into input mode
    GPIO.setup(GPIO_FLYINGFISH_FRONT, GPIO.IN)
    # Add the event
    GPIO.add_event_detect(GPIO_FLYINGFISH_FRONT, GPIO.RISING, callback=get_grounded_state, bouncetime=100)

```

- Pour par la suite, créer une méthode qu initialisera les différents événements pour le flying-fish (Front, Right, Back, Left) avec leurs GPIO ainsi que leur évenement à chacun
- Ensuite j'ai fait un peu de documentation

#### Liens consultés

##### Python

- https://www.pythoncentral.io/how-to-check-if-an-object-has-an-attribute-in-python/

##### Autre

- https://serverfault.com/questions/131935/network-error-no-buffer-space-available#616474
- https://www.javatpoint.com/get-hostname-from-ip-address
- https://raspberrypi.stackexchange.com/questions/40854/kernel-panic-not-syncing-vfs-unable-to-mount-root-fs-on-unknown-block179-6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

### 27.05.2021

- J'ai commencé la journée en continuant la documentation faite la veille
- Ensuite j'ai lu [cet article](https://tutorials-raspberrypi.com/transfer-raspberry-pi-raspbian-os-to-an-sd-card-windows/) afin de cloner à nouveau les cartes SD car la dernière fois que je l'avais fait, elles étaient illisibles et provoquait cette erreur : `Kernel panic-not syncing: VFS: unable to mount root fs on unknown- block(179,6)`
  - Dans cet article, ils disent d'utiliser [ce logiciel](https://www.sdcard.org/downloads/formatter/sd-memory-card-formatter-for-windows-download/) pour formater les cartes SD
    - Dans l'article, ils disent de cocher la case `format size adjustment` mais l'exécutable ne nous permet pas de cocher cette case. En lisant le [manuel utilisateur](https://www.sdcard.org/pdf/SD_CardFormatterUserManualEN.pdf), ils disent que cette option est disponible uniquement sur l'exécutable windows (celui dans lequel je suis), donc étrange que ça ne fonctionne pas.
    - Cependant, ils disent que cette option est utilisable uniquement sur les cartes de 8Go ou moins, mais pour ma part j'utilise une carte SD de 16Go.
  - Après avoir fait la copie de la carte et de l'avoir mise sur un Pi 4 pour tester l'installation, j'ai toujours le même problème je vais donc essayer de refaire une image car c'est peut-être l'image de base qui est défectueuse
  - Je me suis rendu compte d'une erreur que j'ai faite, n'ayant pas vérifié la taille des cartes SD lors de l'élaboration de l'image, j'ai travaillé sur une carte SD de 64Go et j'essaie de copier cette carte dans une carte de 16Go, évidemment que ça ne fonctionne pas
  - J'ai donc refait une image sur une carte de 16Go en reconfigurant le Raspberry Pi :
    - Désactivation du login au démarrage en allant dans la configuration du raspberry pi avec : `sudo raspi-config`, ensuite aller dans `System Options`, ensuite dans `Boot / Auto Login` et `Console Autologin`
    - Changer le clavier de la langue, aller dans `Localisation Options`, ensuite `Keyboard`, sélectionner le clavier ou la marque de clavier que vous utilisez, dans mon cas `Logitech K120`mais n'étant pas présent dans la liste, j'utilise juste le clavier `Logitech`, ensuite il faut cliquer sur `Other`, allez dans `German (Switerland)`, sélectionner `German (Switzerland) - French (Switzerland)`, sélectionner `The default for the keyboard layout`, `No compose key`
    - Activer le WiFi : toujours dans la configuration du raspberry pi dans le menu `Localisation Options`, il faut aller dans `WLAN Country Set legal wireless channels for your country`, ensuite dans la sélection des pays, il faut chercher cette ligne `CH Switzerland`, par la suite aller dans `System Options`, `Wireless LAN`, il faut entrer le nom du réseau `rtr_ackermanngue` puis le mot de passe : `Super2012`
    - Activer les interfaces utilisées : en allant dans `Interface Options` et en activant :
      - La `Camera`
      - Le `SSH`
      - Le `I2C`
    - Mettre à jour le raspberry pi avec la commande : `sudo apt update && sudo apt full-upgrade`
    - Installer git : `sudo apt install git`
      - Cloner le repos : `git clone https://github.com/ACKERMANNGUE/ACKERMANNGUE-AG_Dipl_Tech_2021_VoitureAssistee`
    - Installer les dépendences :
      - `sudo apt install python3-pip`
      - `sudo pip3 install flask`
      - `sudo pip3 install RPi.GPIO`
      - `sudo apt install python-opencv`
      - `sudo pip3 install smbus`
      - `sudo pip3 install picamera`
    - Une fois installées, j'ai lancé le projet pour faire les tests et ça fonctionne parfaitement
  - Ensuite, j'ai fais une copie de cette carte avec [cette application](https://www.diskpart.com/articles/copy-sd-card-to-sd-card-windows-7201.html) dans une autre similaire en taille
    - Pendant la copie de la carte SD, j'ai continué la documentation, en prennant des captures d'écrans pour la configuration de l'émetteur WiFi
  - Une fois la copie terminée, j'ai testé l'installation, mais ça n'a pas fonctionné. J'ai été demandé à M. Beney comment il avait fait pour cloner ses cartes SD ce à quoi il m'a répondu qu'il a utilisé la commande `DD` ainsi que `balenaEtcher`.
    - Vu que chez lui ceci a fonctionné, je me suis dit que j'allais faire de même.
    - Je n'ai pas eu besoin d'utiliser la commande `DD` car `balenaEtcher` permet de cloner un disque.
  - J'ai installé les 4 cartes SD dans le Pi 0 WiFi en m'assurant avant que chaque carte SD avait bien tous les différents éléments nécessaires
    - Pendant la copie des différentes cartes, j'ai fait cette image montrant comment utiliser balenaEtcher :

Différentes étapes d'utilisation de balenaEtcher

- J'ai ensuite continuer la documentation

#### Liens consultés

##### Raspberry

- https://learn.pi-supply.com/make/bright-pi-quickstart-faq/
- https://tutorials-raspberrypi.com/transfer-raspberry-pi-raspbian-os-to-an-sd-card-windows/
- https://raspberrypi.stackexchange.com/questions/40415/how-to-enable-auto-login#76275

##### Python

- https://stackoverflow.com/questions/6587507/how-to-install-pip-with-python-3
- https://raspberrypi.stackexchange.com/questions/60774/importerror-no-module-named-rpi#61462
- https://stackoverflow.com/questions/48012582/pillow-libopenjp2-so-7-cannot-open-shared-object-file-no-such-file-or-directo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
- https://stackoverflow.com/questions/57860201/importerror-libavcodec-so-57-cannot-open-shared-object-file-no-such-file-or-d

##### Autre

- https://www.sdcard.org/downloads/formatter/sd-memory-card-formatter-for-windows-download/
- https://www.sdcard.org/pdf/SD_CardFormatterUserManualEN.pdf
- https://www.diskpart.com/articles/copy-sd-card-to-sd-card-windows-7201.html
- https://www.diskpart.com/articles/copy-sd-card-to-sd-card-windows-7201.html
- https://www.balena.io/etcher/
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

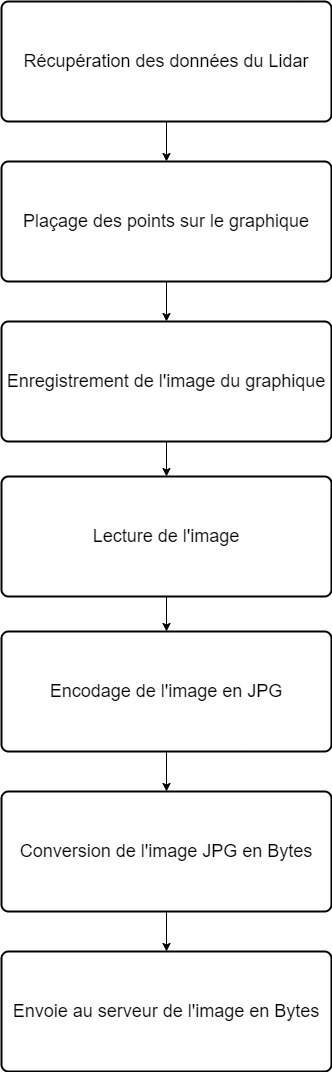
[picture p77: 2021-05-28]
docs/images/problem_lidar.png

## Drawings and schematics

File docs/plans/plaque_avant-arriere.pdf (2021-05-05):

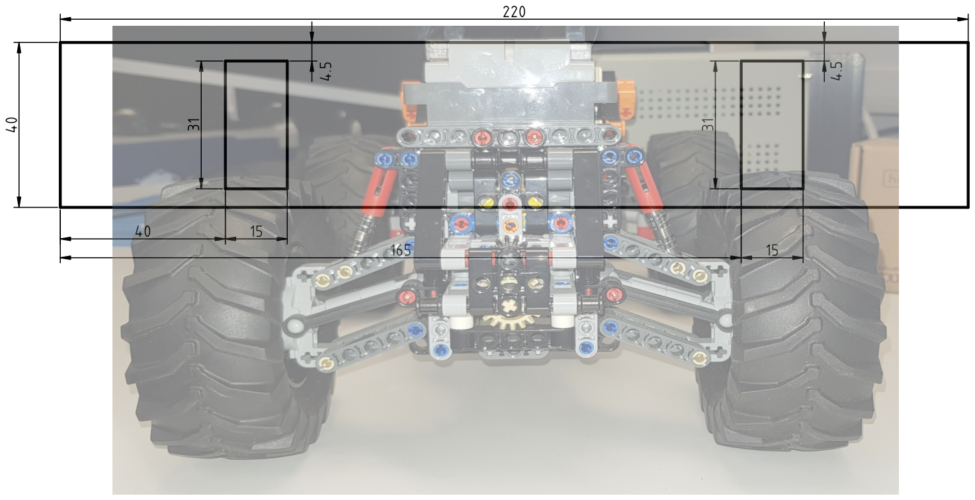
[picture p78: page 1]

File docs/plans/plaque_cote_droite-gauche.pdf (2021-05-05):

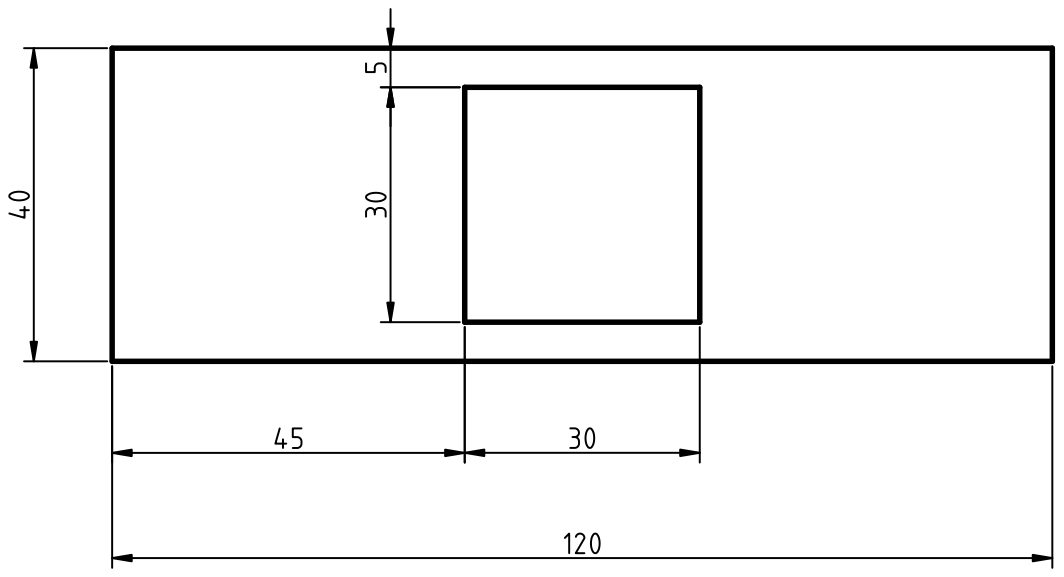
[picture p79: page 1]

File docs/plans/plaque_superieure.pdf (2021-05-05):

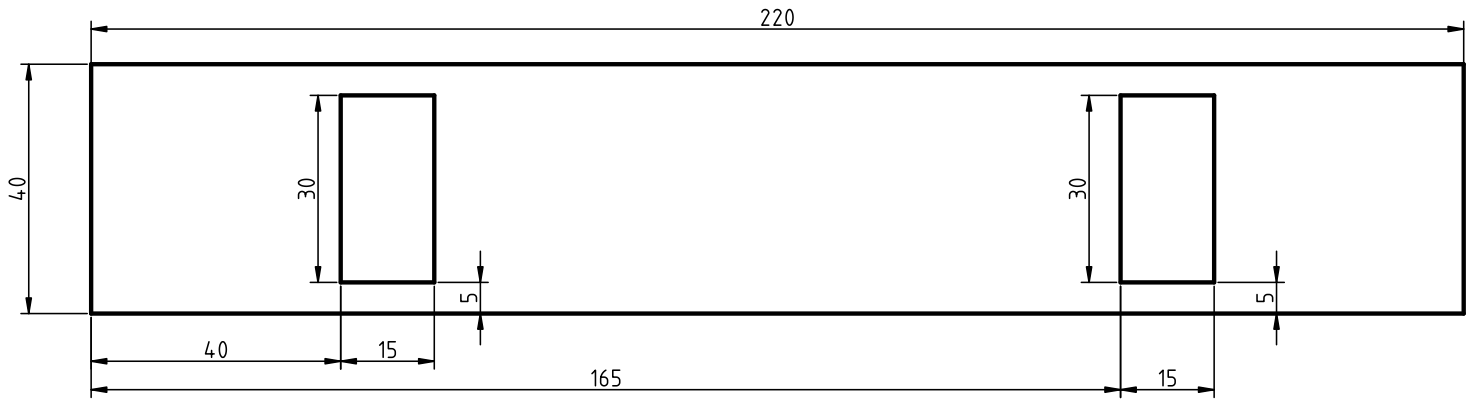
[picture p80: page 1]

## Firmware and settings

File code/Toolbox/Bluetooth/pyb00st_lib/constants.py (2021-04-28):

#
# Constants
#

MOVE_HUB_HARDWARE_HANDLE = 0x0E
MOVE_HUB_HARDWARE_UUID = '00001624-1212-efde-1623-785feabcd123'

# Ports

PORT_A = 0x37
PORT_B = 0x38
PORT_C = 0x01
PORT_D = 0x02
PORT_TILT = 0x3A

# Device Types
TYPE_NONE = 0x00
TYPE_WEDO2MOTOR = 0x01
TYPE_LED = 0x17
TYPE_WEDO2TILT = 0x22
TYPE_WEDO2DISTANCE = 0x23
TYPE_COLORDISTANCE = 0x25
TYPE_ENCODERMOTOR = 0x26
TYPE_MOTOR = 0x27   # ???
TYPE_HUBTILT = 0x28


# Commands for setting RGB LED color
SET_LED_OFF = b'\x08\x00\x81\x32\x11\x51\x00\x00'
SET_LED_PINK = b'\x08\x00\x81\x32\x11\x51\x00\x01'
SET_LED_PURPLE = b'\x08\x00\x81\x32\x11\x51\x00\x02'
SET_LED_BLUE = b'\x08\x00\x81\x32\x11\x51\x00\x03'
SET_LED_LIGHTBLUE = b'\x08\x00\x81\x32\x11\x51\x00\x04'
SET_LED_CYAN = b'\x08\x00\x81\x32\x11\x51\x00\x05'
SET_LED_GREEN = b'\x08\x00\x81\x32\x11\x51\x00\x06'
SET_LED_YELLOW = b'\x08\x00\x81\x32\x11\x51\x00\x07'
SET_LED_ORANGE = b'\x08\x00\x81\x32\x11\x51\x00\x08'
SET_LED_RED = b'\x08\x00\x81\x32\x11\x51\x00\x09'
SET_LED_WHITE = b'\x08\x00\x81\x32\x11\x51\x00\x0A'

SET_LED_COLOR = [SET_LED_OFF,
                 SET_LED_PINK,
                 SET_LED_PURPLE,
                 SET_LED_BLUE,
                 SET_LED_LIGHTBLUE,
                 SET_LED_CYAN,
                 SET_LED_GREEN,
                 SET_LED_YELLOW,
                 SET_LED_ORANGE,
                 SET_LED_RED,
                 SET_LED_WHITE]

# Colors:
LED_COLORS = ['OFF', 'PINK', 'PURPLE', 'BLUE', 'LIGHTBLUE', 'CYAN', 'GREEN', 'YELLOW', 'ORANGE', 'RED', 'WHITE']

# Motors:

MOTOR_A = bytes([0x37])
MOTOR_B = bytes([0x38])
MOTOR_AB = bytes([0x39])
MOTOR_C = bytes([0x01])
MOTOR_D = bytes([0x02])

# a group of all single motors
MOTORS = [MOTOR_A, MOTOR_B, MOTOR_AB, MOTOR_C, MOTOR_D]

# a group of 1 is silly but there might be other pairs in the future
MOTOR_PAIRS = [MOTOR_AB]

# Commands for Interactive Motors (Timed):

# Motor A, B, C, D: 12-byte commands
# Motor AB: 13-byte commands

MOTOR_TIMED_INI = b'\x0c\x01\x81'
MOTOR_TIMED_MID = b'\x11\x09'
MOTOR_TIMED_END = b'\x64\x7f\x03'

MOTORS_TIMED_INI = b'\x0d\x01\x81'
MOTORS_TIMED_MID = b'\x11\x0A'
MOTORS_TIMED_END = b'\x64\x7f\x03'

# Commands for Interactive Motors (Angle):

# Motor A, B, C, D: 14-byte commands
# Motor AB: 15-byte commands

MOTOR_ANGLE_INI = b'\x0e\x01\x81'
MOTOR_ANGLE_MID = b'\x11\x0b'
MOTOR_ANGLE_END = b'\x64\x7f\x03'

MOTORS_ANGLE_INI = b'\x0f\x01\x81'
MOTORS_ANGLE_MID = b'\x11\x0c'
MOTORS_ANGLE_END = b'\x64\x7f\x03'

# Commands for WeDo Motors (just Duty Cycle):
MOTOR_WEDO_INI = b'\x08\x00\x81'
MOTOR_WEDO_MID = b'\x11\x51\x00'


# Commands that Initialize sensors in certain Modes

LISTEN_INI = b'\x0a\x00\x41'
LISTEN_END = b'\x01\x00\x00\x00\x01'
LISTEN_BUTTON = b'\x05\x00\x01\x02\x02'

MODE_COLORDIST_SENSOR = b'\x08'
MODE_ENCODER = b'\x02'
MODE_HUBTILT_BASIC = b'\x02'
MODE_HUBTILT_FULL = b'\x00'

# WeDo 2.0 Tilt Sensor modes:
# 0 = angle
# 1 = tilt
# 2 = crash
# 3 = some variation of angle
# modes 0,1,2 like WeDo 2.0 modes

MODE_WEDOTILT_ANGLE = b'\x00'
MODE_WEDOTILT_TILT = b'\x01'
MODE_WEDOTILT_CRASH = b'\x02'
MODE_WEDODIST_DISTANCE = b'\x00'

# WeDo 2.0 Distance Sensor modes:
# 0 = distance 00..0A
# 1 = increments when blocked
# 2 = distance and luminosity ?
# all continuous reading
# just using mode 0=distance

MODE_WEDODIST_1 = b'\x01'
MODE_WEDODIST_2 = b'\x02'

#
# Constants:
#

# Sensor Colors:
COLOR_SENSOR_COLORS = ['BLACK', '', '', 'BLUE', '', 'GREEN', '', 'YELLOW', '', 'RED', 'WHITE']

# Encoder
ENCODER_MID = 2147483648
ENCODER_MAX = 4294967296

# Button

BUTTON_PRESSED = '\x01'
BUTTON_RELEASED = '\x00'

# BOOST Tilt Sensor
TILT_HORIZ = 0x00
TILT_UP = 0x01
TILT_DOWN = 0x02
TILT_RIGHT = 0x03
TILT_LEFT = 0x04
TILT_INVERT = 0x05

TILT_BASIC_VALUES = [TILT_HORIZ, TILT_UP, TILT_DOWN, TILT_RIGHT, TILT_LEFT, TILT_INVERT]
TILT_BASIC_TEXT = ['TILT_HORIZ', 'TILT_UP', 'TILT_DOWN', 'TILT_RIGHT', 'TILT_LEFT', 'TILT_INVERT']

# WeDo 2.0 Tilt Sensor

WEDO_TILT_HORIZ = 0x00
WEDO_TILT_LEFT = 0x07
WEDO_TILT_RIGHT = 0x05
WEDO_TILT_UP = 0x03
WEDO_TILT_DOWN = 0x09

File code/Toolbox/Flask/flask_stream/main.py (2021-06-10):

# @file cam_test.py
# @brief Used to test the streaming of the camera with flask

# Author : Ackermann Gawen
# Last update : 10.06.2021

from flask import Flask, render_template, Response, request
from camera import VideoCamera
import time
import threading
import os
import cv2

pi_camera = VideoCamera(flip=True) # flip pi camera if upside down.


app = Flask(__name__)

@app.route('/streaming_camera')
def cam_stream():
    """
    Route which display the video feed page
    """
    global camera_state
    return render_template('index.html', name=constants.FRONT_CAM, mode=camera_state, on=constants.STATE_ON, off=constants.STATE_OFF)

def gen(camera):
    """
    Convert the frame into a response in bytes format

    camera : The camera object
    """
    #get camera frame
    while True:
        frame = camera.get_frame()
        yield (b'--frame\r\n'
               b'Content-Type: image/jpeg\r\n\r\n' + frame + b'\r\n\r\n')

@app.route('/video_feed')
def video_feed():
    """Route which returns the video feed of the camera"""
    global pi_camera
    return Response(gen(pi_camera),
                    mimetype='multipart/x-mixed-replace; boundary=frame')
                    mimetype='multipart/x-mixed-replace; boundary=frame')


if __name__ == '__main__':

    app.run(host='0.0.0.0', debug=False)
    

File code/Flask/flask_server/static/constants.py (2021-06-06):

DEFAULT_MODE = False
MODE_OFF = 0
MODE_ON = 1
DEFAULT_SPEED = 0
DEFAULT_ANGLE = 0

BTN_REQUEST_RESET_ANGLE = "reset angle"
BTN_REQUEST_STOP = "stop"
BTN_REQUEST_DISCONNECT = "disconnect"

SENSOR_BRIGHTPI = "bright-pi"
SENSOR_CAMERA = "camera"
SENSOR_FLYINGFISH = "flying-fish"

CHART_PATH = "static/img/"
CHART_NAME = "chart.jpg"
CHART_DOWN_NAME = "radar_down.png"

GPIO_FLYING_FISH_FRONT_RIGHT = 17
GPIO_FLYING_FISH_FRONT_LEFT = 27
GPIO_FLYING_FISH_BACK_RIGHT = 23
GPIO_FLYING_FISH_BACK_LEFT = 24

GPIO_BOUNCEBACK = 300

FLYING_FISH_STATE_GROUNDED = True
FLYING_FISH_STATE_UNGROUNDED = False

GPIO_FLYING_FISH = [
    (GPIO_FLYING_FISH_FRONT_LEFT, FLYING_FISH_STATE_GROUNDED),
    (GPIO_FLYING_FISH_FRONT_RIGHT, FLYING_FISH_STATE_GROUNDED),
    (GPIO_FLYING_FISH_BACK_LEFT, FLYING_FISH_STATE_GROUNDED),
    (GPIO_FLYING_FISH_BACK_LEFT, FLYING_FISH_STATE_GROUNDED),
]

CODE_TURN_NOTHING = 0
CODE_TURN_LEFT = 1
CODE_TURN_RIGHT = 2

CODE_MOVE_NOTHING = 0
CODE_MOVE_FORWARD = 1
CODE_MOVE_BACKWARD = 2

MAX_ANGLE_OBSTACLE_DETECTION = 15
FRONT_DISTANCE_OBSTACLE_DETECTION = 320
BACK_DISTANCE_OBSTACLE_DETECTION = 150

FULL_ANGLE = 360
HALF_ANGLE = FULL_ANGLE / 2


MAX_SPEED_FROM_BORDER = 0.2

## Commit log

2021-04-20 ajout des images pour le logbook + avancement logbook
2021-04-23 avancement bluetooth + GATT + plan de la plaque superieur avec QCad
    [plaque_superieure.dxf]
2021-04-28 avancement de la documentation
2021-04-28 restructuration projet
    [plaque_superieure.dxf]
2021-04-28 correction de liens pour les images
    [plaque_superieure.dxf]
2021-04-29 ajout des commentaires
2021-04-29 mise à jour de la documentation technique + logbook
2021-04-29 ajout de la documentation générée par MkDocs
    [plaque_superieure.dxf]
2021-05-04 ajout maquettes + plans, continuation logbook
    [plaque_avant-arriere.dxf, plaque_cote_droite-gauche.dxf, plaque_superieure.dxf]
2021-05-05 ajout flying-fish stoppant les moteurs
2021-05-07 ise en place page de stream
2021-05-10 code flask pour les raspberry pi 0 Wifi
2021-05-14 resolution probleme camera
2021-05-17 ajout code asynchrone pour l'était des capteurs sur le serveur principale
2021-05-20 ajout code d'affichage des données du scanner 360°
2021-05-28 correction bug bluetooth + correction code detection de sol
    [car.py, server.py]
2021-05-28 modification du code gérant les capteurs
2021-05-31 ajout code gérant les déplacements possible avec les détecteurs + avancement logbook
2021-06-03 flip de la camera + augmentation framerate et resolution + continuation logook
2021-06-03 modification code pour tous les flying-fish
2021-06-06 voiture mode automatique avancer/reculer eviter de tomber
2021-06-07 correction bug evitement obstacles
    [car.py, server.py]
2021-06-09 supression des imports inutiles
